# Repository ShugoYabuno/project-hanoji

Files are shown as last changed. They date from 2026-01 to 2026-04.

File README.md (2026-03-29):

# Project Hanoji

## 概要
手首や腕の負担を軽減する、八の字型（回外姿勢）のレバーレスコントローラー開発プロジェクト。

## 目標
- エルゴノミクスに基づいた操作性の高いコントローラーの開発
- 製品化および販売

## ディレクトリ構成
- `marketing/sns/`: SNS発信（投稿案・スケジュール管理）
- `marketing/strategy/`: 戦略立案（市場調査・競合分析・販売戦略）
- `marketing/product/`: 商品企画（仕様書・ロードマップ）
- `content/`: コンテンツ（ブログ記事・SNS投稿案・画像素材）
- `docs/`: ドキュメント（試作仕様・Deep Research）

## エージェント起動方法（Claude Code）

各ディレクトリで `claude` を起動すると、専用の指示（CLAUDE.md）が自動で読み込まれます。

| やりたいこと | 起動コマンド |
|---|---|
| SNS投稿を作りたい | `cd marketing/sns && claude` |
| 商品企画・試作仕様を進めたい | `cd marketing/product && claude` |
| 市場調査・戦略を考えたい | `cd marketing/strategy && claude` |
| ブログ記事を書きたい | `cd content && claude` |

複数タブで同時に起動することで、並列に作業できます。

## ドキュメント
- 競合調査（2026-01-14）: `docs/deepresearch/market_strategy/competitive_research_2026-01-14.md`
- Deep Research INDEX: `docs/deepresearch/INDEX.md`

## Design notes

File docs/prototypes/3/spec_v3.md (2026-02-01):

# 試作3号機 (v3) 仕様書：多面体キーウェルと分割構造の導入

## 1. 概要 (Overview)
試作3号機（v3）は、v1/v2で得られた「角度（Tenting/Opening Angle）」の知見に加え、新たに**「深さ（Depth）」と「分割構造（Modularity）」**を取り入れる。
人間の手の解剖学的構造に寄り添う「多面体（Polyhedral）」形状を採用することで、製造難易度を抑えつつ、ハイエンドなエルゴノミクスキーボードに近いフィット感と入力精度を実現することを目的とする。

## 2. 開発背景と振り返り

### v1/v2 の課題
*   **v1 (Flat Tented)**: テンティングのみでハの字角がなく、手首の背屈（反り）と滑り落ちが発生。
*   **v2 (Monocoque Tented)**:
    *   **形状**: 一体成型のため、3Dプリント時のオーバーハング面が荒れ、製造時間が長大化。
    *   **親指**: 親指キーが他の指と同じ平面にあったため、CM関節への負担が残り、押しにくさがあった。
    *   **配置**: パームレストに対し、ボタン位置が手前すぎた（窮屈）。

### v3 での解決アプローチ
*   **多面体キーウェル**: 曲面を「平面の組み合わせ」で近似し、指の屈曲軌道に合わせる。
*   **親指の立体配置**: 親指ユニットを物理的に一段下げる（Vertical Offset）。
*   **3パーツ分割構造**: 「天板」「フレーム」「底面」を分けることで、プリント品質の安定化とメンテナンス性を確保。

---

## 3. コンセプト (Concept)

### "Polyhedral Key Well" (多面体キーウェル)
完全な曲面（Curved）ではなく、複数の平面を角度をつけて接合する設計。
*   **メリット**:
    *   3Dプリント時に平面が出しやすく、スイッチの座りが安定する（ガタつかない）。
    *   パラメータ調整（角度変更）が容易。

### "Negative Tilt & Integrated Rest"
*   パームレスト部を最も高くし、指先に向かって下がる（Negative Tilt）形状を採用。
*   手首をニュートラル（水平〜やや下向き）に保ち、腱の緊張を最小化する。

---

## 4. 詳細仕様 (Specifications)

### 4.1 ジオメトリ・パラメータ
解剖学的調査に基づき、以下の数値を採用する（v3確定値）。

| 項目 | 設定値 | 意図・根拠 |
| :--- | :--- | :--- |
| **テンティング角 (Tenting)** | **20°** | 前腕の回内緊張を取り除くスイートスポット。 |
| **ハの字角 (Opening Angle)** | **20° (片側)** | センターラインに対する片側の開き角度（両側合計 40°）。脇を少し開いた自然な姿勢に合わせる。 |
| **チルト角 (Negative Tilt)** | **-10°** | パームレスト面（水平基準）に対し、Ridgeから奥側の**ボタン配置面（アクションボタン・移動ボタン共に）**が下がる角度。手首の背屈を防ぐ。 |
| **親指オフセット (Thumb Z)** | **-6.0 mm** (基準面より) | 親指の対立運動に合わせ、他指より低く配置。 |
| **親指内転角 (Thumb Inward)** | **20°** | 親指の腹が自然にスイッチを捉える角度。 |

### 4.2 レイアウト寸法
*   **パームレスト深さ**: 豆状骨（Pisiform）のサポート位置からホームポジション（中指）まで **約90mm** を確保。
*   **ボタン配置**:
    *   v2より全体を **15mm 奥へ移動**。

### 4.3 ボタンレイアウト詳細 (Advanced Layout Strategy)
調査資料「指に優しいボタンレイアウトの設計ガイド」に基づき、各指の役割と可動域に合わせた配置を行う。

#### A. Column Stagger (縦方向オフセット)
中指の先端位置を基準(0mm)とし、指の長さに合わせて各列を縦方向にずらす。
*   **中指列**: ±0 mm (基準)
*   **人差し指列**: -4.0 mm
*   **薬指列**: -6.0 mm
*   **小指列**: **-15.0 mm** (約0.75キー分)
    *   *根拠*: 小指は中指より約20mm短いため、大胆に下げることで「届かない」ストレスを解消する。

#### B. Row Stagger (横方向オフセット)
*   **オフセット量**: **0mm (Ortholinear / 縦揃え)**
    *   *理由*: 一般的なキーボードの斜めズレ（Row Stagger）は、脇を締めた姿勢で指を斜めに動かすための補正である。本機は「ハの字（Opening Angle）」によって腕の進入角度を正対させているため、指は真っ直ぐ手前に屈曲する。したがって、ボタンも縦一列に揃えるのが解剖学的にもゲーム操作（スライド入力等）的にも最適解となる。
    *   *(参考: Alice配列キーボード等も、ハの字に開くことでキー配列自体は縦揃えに近い構成を採用している)*

#### C. Splay (放射状配置)
*   **小指列の角度**: 外側に **10° 〜 15°** 開く。
    *   *根拠*: 小指の自然な外転運動に合わせ、窮屈な内側へのねじ込みを防ぐ。

#### C. Zoning (ゾーニング戦略)
フィッツの法則に基づき、使用頻度と距離を最適化する。
*   **Primary Zone (半径50mm圏内)**:
    *   主要攻撃ボタン（弱・中・強パンチ/キック）を配置。
    *   指先（DIP関節）の屈伸だけで届く範囲に収める。
*   **Secondary Zone**:
    *   特殊アクション（パリィ、インパクト等）は、Primary Zoneから **外側へ10mm** 離して配置。
    *   *意図*: 誤入力を防ぐとともに、明確な「指の移動」を意識させる。

#### D. Ridge (折れ目) との距離定義
多面体構造における平面の境界線（Ridge）と、設計上の基準点（Reference Point）を以下のように定義する。

*   **パームレスト基準点 (Reference Point)**:
    *   **定義**: 筐体（パームレスト部）の **手前エッジ (Front Edge) から 30mm 奥** の地点。
    *   *意図*: ここに豆状骨（手首の小指側の骨）が乗ることを想定する。手前ギリギリに置くとエッジが当たって痛いため、余裕を持たせた位置を基準とする。

*   **Ridge Line (屈曲点)**:
    *   パームレスト基準点から **45mm** 前方（※手前エッジからは計75mm）。
    *   このラインを最高点とし、ここからボタン面（Negative Tilt面）へと切り替わる。
    *   *意図*: 手のひらの中央（中手骨）付近で面を折り、MP関節の可動域と指の巻き込み（Curl）をサポートする。

*   **Ridgeから各ボタン穴の中心 (Hole Center) までの距離**:
    *   ※設計・モデリングの基準とするため、すべて「ボタン穴の中心座標」までの距離とする。
    *   **中指**: **45mm**
        *   *(参考: φ24mmボタンの場合、指が触れる手前エッジまでは約33mm)*
    *   **人差し指**: **42mm**
    *   **薬指**: **42mm**
    *   **小指**: **30mm**
        *   *補足*: 小指はColumn Stagger（-15mm）と合わせて、物理的にもRidgeに近づけることで、短い指でも無理なく届くようにする。

#### E. Movement Buttons (左手・移動ボタン) のY軸定義
左手側の3ボタン（Left, Down, Right）は一段構成であるため、右手側との整合性を以下のように定義する。

*   **Y軸基準 (Row Alignment)**:
    *   右手側の **上段 (Punch列) と下段 (Kick列) の中間、かつ上段寄り** を基準とする。
    *   **具体的数値**: 上段ボタン（Punch列）の中心Y座標から **手前へ 10mm (-10mm)** の位置を、移動ボタン（中指・Down）のY座標基準とする。
    *   *理由*: ユーザーのホームポジション感覚（上段と下段の間）に一致させ、左右の手首位置を対称に保つため。
*   **各指のオフセット (Stagger)**:
    *   右手と同様のColumn Staggerを適用し、指の長さにフィットさせる。
    *   **薬指 (Left)**: 中指より **-6.0mm** (手前)
    *   **中指 (Down)**: 基準 (0mm) / Ridgeから45mm
    *   **人差し指 (Right)**: 中指より **-4.0mm** (手前)

### 4.4 構造設計 (Mechanical Design)
プリント方向と品質を最適化するため、以下の3パーツ構成とする。

1.  **Top Plate (天板)**
    *   スイッチをはめ込むメインパーツ。多面体形状。
    *   *プリント方向*: 立てて出力（積層痕を打鍵方向に対して垂直にし、滑らかにする）。
2.  **Main Frame (側面・パームレスト)**
    *   手首を支える土台。剛性を確保。
    *   *プリント方向*: 平置き。
3.  **Bottom Plate (底蓋)**
    *   メンテナンス用ハッチ。
    *   *プリント方向*: 平置き。

### 4.5 締結・固定仕様 (Assembly)
*   **ネジ穴径**: **φ3.2 mm** (M3ネジ用)
    *   *方式*: ヒートインサートナットを使用せず、ボルト＆ナット（貫通またはポケット）で固定する設計とする。3Dプリント品へのダイレクトタッピングは強度が不安なため避ける。
    *   *配置*: 応力が集中する「パームレスト境界」と「四隅」の計6箇所を固定推奨。

---

## 5. 検証項目 (Hypotheses to Validate)

1.  **親指オフセットの操作性**:
    *   -6mmの段差は、同時押し（スライド入力）を阻害しないか？
    *   ジャンプボタンへのアクセスは改善するか？
2.  **多面体のフィット感**:
    *   指の腹で捉える感覚は向上するか？
    *   エッジ（折れ目）が手に当たって痛くないか？（フィレット処理の要否）
3.  **分割構造の剛性**:
    *   激しい打鍵（台パン等）において、接合部の強度は十分か？
    *   音鳴り（共振）が発生しないか？

## 6. 次のステップ
1.  **CADモデリング**: Fusion 360にて多面体ブロックを作成し、パラメータを適用。
2.  **部分試作**: 親指ユニット周辺のみを切り出してプリントし、オフセット量を確認。
3.  **全体試作**: v3-alphaの出力と組み立て。

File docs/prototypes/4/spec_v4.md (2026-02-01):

# 試作4号機 (v4) 仕様書：チルト角度 -15° の検証

## 1. 概要 (Overview)
試作4号機（v4）は、v3をベースに**チルト角のみ -15° に変更**して、手首の負担と指の巻き込み感を確認するための検証機である。
他の設計パラメータはv3を踏襲し、角度変更による体感差を明確に比較することを目的とする。

## 2. 開発背景と振り返り

### v3 からの変更点
*   **チルト角 (Negative Tilt)** を **-10° → -15°** に変更。
*   それ以外の構造・レイアウトはv3と同一。

---

## 3. コンセプト (Concept)

### "Polyhedral Key Well" (多面体キーウェル)
完全な曲面（Curved）ではなく、複数の平面を角度をつけて接合する設計。
*   **メリット**:
    *   3Dプリント時に平面が出しやすく、スイッチの座りが安定する（ガタつかない）。
    *   パラメータ調整（角度変更）が容易。

### "Negative Tilt & Integrated Rest"
*   パームレスト部を最も高くし、指先に向かって下がる（Negative Tilt）形状を採用。
*   手首をニュートラル（水平〜やや下向き）に保ち、腱の緊張を最小化する。

---

## 4. 詳細仕様 (Specifications)

### 4.1 ジオメトリ・パラメータ
解剖学的調査に基づき、以下の数値を採用する（v4確定値）。

| 項目 | 設定値 | 意図・根拠 |
| :--- | :--- | :--- |
| **テンティング角 (Tenting)** | **20°** | 前腕の回内緊張を取り除くスイートスポット。 |
| **ハの字角 (Opening Angle)** | **20° (片側)** | センターラインに対する片側の開き角度（両側合計 40°）。脇を少し開いた自然な姿勢に合わせる。 |
| **チルト角 (Negative Tilt)** | **-15°** | パームレスト面（水平基準）に対し、Ridgeから奥側の**ボタン配置面（アクションボタン・移動ボタン共に）**が下がる角度。手首の背屈を防ぐ。 |
| **親指オフセット (Thumb Z)** | **-6.0 mm** (基準面より) | 親指の対立運動に合わせ、他指より低く配置。 |
| **親指内転角 (Thumb Inward)** | **20°** | 親指の腹が自然にスイッチを捉える角度。 |

### 4.2 レイアウト寸法
*   **パームレスト深さ**: 豆状骨（Pisiform）のサポート位置からホームポジション（中指）まで **約90mm** を確保。
*   **ボタン配置**:
    *   v2より全体を **15mm 奥へ移動**。

### 4.3 ボタンレイアウト詳細 (Advanced Layout Strategy)
調査資料「指に優しいボタンレイアウトの設計ガイド」に基づき、各指の役割と可動域に合わせた配置を行う。

#### A. Column Stagger (縦方向オフセット)
中指の先端位置を基準(0mm)とし、指の長さに合わせて各列を縦方向にずらす。
*   **中指列**: ±0 mm (基準)
*   **人差し指列**: -4.0 mm
*   **薬指列**: -6.0 mm
*   **小指列**: **-15.0 mm** (約0.75キー分)
    *   *根拠*: 小指は中指より約20mm短いため、大胆に下げることで「届かない」ストレスを解消する。

#### B. Row Stagger (横方向オフセット)
*   **オフセット量**: **0mm (Ortholinear / 縦揃え)**
    *   *理由*: 一般的なキーボードの斜めズレ（Row Stagger）は、脇を締めた姿勢で指を斜めに動かすための補正である。本機は「ハの字（Opening Angle）」によって腕の進入角度を正対させているため、指は真っ直ぐ手前に屈曲する。したがって、ボタンも縦一列に揃えるのが解剖学的にもゲーム操作（スライド入力等）的にも最適解となる。
    *   *(参考: Alice配列キーボード等も、ハの字に開くことでキー配列自体は縦揃えに近い構成を採用している)*

#### C. Splay (放射状配置)
*   **小指列の角度**: 外側に **10° 〜 15°** 開く。
    *   *根拠*: 小指の自然な外転運動に合わせ、窮屈な内側へのねじ込みを防ぐ。

#### C. Zoning (ゾーニング戦略)
フィッツの法則に基づき、使用頻度と距離を最適化する。
*   **Primary Zone (半径50mm圏内)**:
    *   主要攻撃ボタン（弱・中・強パンチ/キック）を配置。
    *   指先（DIP関節）の屈伸だけで届く範囲に収める。
*   **Secondary Zone**:
    *   特殊アクション（パリィ、インパクト等）は、Primary Zoneから **外側へ10mm** 離して配置。
    *   *意図*: 誤入力を防ぐとともに、明確な「指の移動」を意識させる。

#### D. Ridge (折れ目) との距離定義
多面体構造における平面の境界線（Ridge）と、設計上の基準点（Reference Point）を以下のように定義する。

*   **パームレスト基準点 (Reference Point)**:
    *   **定義**: 筐体（パームレスト部）の **手前エッジ (Front Edge) から 30mm 奥** の地点。
    *   *意図*: ここに豆状骨（手首の小指側の骨）が乗ることを想定する。手前ギリギリに置くとエッジが当たって痛いため、余裕を持たせた位置を基準とする。

*   **Ridge Line (屈曲点)**:
    *   パームレスト基準点から **45mm** 前方（※手前エッジからは計75mm）。
    *   このラインを最高点とし、ここからボタン面（Negative Tilt面）へと切り替わる。
    *   *意図*: 手のひらの中央（中手骨）付近で面を折り、MP関節の可動域と指の巻き込み（Curl）をサポートする。

*   **Ridgeから各ボタン穴の中心 (Hole Center) までの距離**:
    *   ※設計・モデリングの基準とするため、すべて「ボタン穴の中心座標」までの距離とする。
    *   **中指**: **45mm**
        *   *(参考: φ24mmボタンの場合、指が触れる手前エッジまでは約33mm)*
    *   **人差し指**: **42mm**
    *   **薬指**: **42mm**
    *   **小指**: **30mm**
        *   *補足*: 小指はColumn Stagger（-15mm）と合わせて、物理的にもRidgeに近づけることで、短い指でも無理なく届くようにする。

#### E. Movement Buttons (左手・移動ボタン) のY軸定義
左手側の3ボタン（Left, Down, Right）は一段構成であるため、右手側との整合性を以下のように定義する。

*   **Y軸基準 (Row Alignment)**:
    *   右手側の **上段 (Punch列) と下段 (Kick列) の中間、かつ上段寄り** を基準とする。
    *   **具体的数値**: 上段ボタン（Punch列）の中心Y座標から **手前へ 10mm (-10mm)** の位置を、移動ボタン（中指・Down）のY座標基準とする。
    *   *理由*: ユーザーのホームポジション感覚（上段と下段の間）に一致させ、左右の手首位置を対称に保つため。
*   **各指のオフセット (Stagger)**:
    *   右手と同様のColumn Staggerを適用し、指の長さにフィットさせる。
    *   **薬指 (Left)**: 中指より **-6.0mm** (手前)
    *   **中指 (Down)**: 基準 (0mm) / Ridgeから45mm
    *   **人差し指 (Right)**: 中指より **-4.0mm** (手前)

### 4.4 構造設計 (Mechanical Design)
プリント方向と品質を最適化するため、以下の3パーツ構成とする。

1.  **Top Plate (天板)**
    *   スイッチをはめ込むメインパーツ。多面体形状。
    *   *プリント方向*: 立てて出力（積層痕を打鍵方向に対して垂直にし、滑らかにする）。
2.  **Main Frame (側面・パームレスト)**
    *   手首を支える土台。剛性を確保。
    *   *プリント方向*: 平置き。
3.  **Bottom Plate (底蓋)**
    *   メンテナンス用ハッチ。
    *   *プリント方向*: 平置き。

### 4.5 締結・固定仕様 (Assembly)
*   **ネジ穴径**: **φ3.2 mm** (M3ネジ用)
    *   *方式*: ヒートインサートナットを使用せず、ボルト＆ナット（貫通またはポケット）で固定する設計とする。3Dプリント品へのダイレクトタッピングは強度が不安なため避ける。
    *   *配置*: 応力が集中する「パームレスト境界」と「四隅」の計6箇所を固定推奨。

---

## 5. 検証項目 (Hypotheses to Validate)

1.  **チルト角 -15° の体感**:
    *   連続入力時の手首角度と疲労感は改善するか？
    *   指先の巻き込み量が過剰にならないか？
2.  **親指オフセットの操作性**:
    *   -6mmの段差は、同時押し（スライド入力）を阻害しないか？
    *   ジャンプボタンへのアクセスは改善するか？
3.  **多面体のフィット感**:
    *   指の腹で捉える感覚は向上するか？
    *   エッジ（折れ目）が手に当たって痛くないか？（フィレット処理の要否）

## 6. 次のステップ
1.  **CADモデリング**: v3モデルを複製し、チルト角のみ -15° に変更。
2.  **部分試作**: アクションボタン面のみを切り出して傾斜の体感を確認。
3.  **全体試作**: v4-alphaの出力と組み立て。

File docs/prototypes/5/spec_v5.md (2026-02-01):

# 試作5号機 (v5) 仕様書：ボタンレイアウト調整版

## 1. 概要 (Overview)
試作5号機（v5）は、v4の筐体仕様（チルト角 -15°）を踏襲しつつ、**ボタンレイアウトのみを調整**した検証機である。
筐体角度は固定し、入力感の改善を目的にレイアウトの微修正を行う。

## 2. 開発背景と振り返り

### v4 からの変更点
*   **チルト角**: v4と同一（-15°）。
*   **ボタンレイアウト**: v4の配置をベースに、手の届きやすさと誤入力の減少を目的として微調整する。

---

## 3. コンセプト (Concept)

### "Polyhedral Key Well" (多面体キーウェル)
完全な曲面（Curved）ではなく、複数の平面を角度をつけて接合する設計。
*   **メリット**:
    *   3Dプリント時に平面が出しやすく、スイッチの座りが安定する（ガタつかない）。
    *   パラメータ調整（角度変更）が容易。

### "Negative Tilt & Integrated Rest"
*   パームレスト部を最も高くし、指先に向かって下がる（Negative Tilt）形状を採用。
*   手首をニュートラル（水平〜やや下向き）に保ち、腱の緊張を最小化する。

---

## 4. 詳細仕様 (Specifications)

### 4.1 ジオメトリ・パラメータ
解剖学的調査に基づき、以下の数値を採用する（v5確定値）。

| 項目 | 設定値 | 意図・根拠 |
| :--- | :--- | :--- |
| **テンティング角 (Tenting)** | **20°** | 前腕の回内緊張を取り除くスイートスポット。 |
| **ハの字角 (Opening Angle)** | **20° (片側)** | センターラインに対する片側の開き角度（両側合計 40°）。脇を少し開いた自然な姿勢に合わせる。 |
| **チルト角 (Negative Tilt)** | **-15°** | パームレスト面（水平基準）に対し、Ridgeから奥側の**ボタン配置面（アクションボタン・移動ボタン共に）**が下がる角度。手首の背屈を防ぐ。 |
| **親指オフセット (Thumb Z)** | **-6.0 mm** (基準面より) | 親指の対立運動に合わせ、他指より低く配置。 |
| **親指内転角 (Thumb Inward)** | **20°** | 親指の腹が自然にスイッチを捉える角度。 |

### 4.2 レイアウト寸法
*   **パームレスト深さ**: 豆状骨（Pisiform）のサポート位置からホームポジション（中指）まで **約90mm** を確保。
*   **ボタン配置**:
    *   v2より全体を **15mm 奥へ移動**。

### 4.3 ボタンレイアウト詳細 (Advanced Layout Strategy)
ボタンレイアウトはv4から調整する。寸法は**v5のCADスケッチを正**とし、以下の差分を記録する。

#### A. v5で調整対象とする項目
*   **アクションボタン上下段のY間隔**: ホームポジション感覚に合わせて微調整。
*   **アクションボタン列のX位置**: 指の到達距離と誤入力のバランスを確認。
*   **移動ボタンのY基準**: 上段寄りの中間位置を維持しつつ、レイアウトの整合性を再確認。

#### B. v4からの暫定踏襲値
*   Column Stagger / Row Stagger / Splay / Ridge距離はv4と同等（必要に応じて上書き）。
*   変更点が確定したら、本セクションに数値を追記する。

### 4.4 構造設計 (Mechanical Design)
プリント方向と品質を最適化するため、以下の3パーツ構成とする。

1.  **Top Plate (天板)**
    *   スイッチをはめ込むメインパーツ。多面体形状。
    *   *プリント方向*: 立てて出力（積層痕を打鍵方向に対して垂直にし、滑らかにする）。
2.  **Main Frame (側面・パームレスト)**
    *   手首を支える土台。剛性を確保。
    *   *プリント方向*: 平置き。
3.  **Bottom Plate (底蓋)**
    *   メンテナンス用ハッチ。
    *   *プリント方向*: 平置き。

### 4.5 締結・固定仕様 (Assembly)
*   **ネジ穴径**: **φ3.2 mm** (M3ネジ用)
    *   *方式*: ヒートインサートナットを使用せず、ボルト＆ナット（貫通またはポケット）で固定する設計とする。3Dプリント品へのダイレクトタッピングは強度が不安なため避ける。
    *   *配置*: 応力が集中する「パームレスト境界」と「四隅」の計6箇所を固定推奨。

---

## 5. 検証項目 (Hypotheses to Validate)

1.  **ボタンレイアウト調整の効果**:
    *   指の到達距離が短くなったか？
    *   誤入力は減少したか？
2.  **チルト角 -15° の体感**:
    *   連続入力時の手首角度と疲労感は改善するか？
    *   指先の巻き込み量が過剰にならないか？

## 6. 次のステップ
1.  **CADモデリング**: v4モデルを複製し、ボタンレイアウトのみを修正。
2.  **部分試作**: 右手側ボタン面のみを切り出して比較テスト。
3.  **全体試作**: v5-alphaの出力と組み立て。

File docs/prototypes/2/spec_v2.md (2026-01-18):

# プロトタイプ v2 設計仕様書 (Draft)

## 1. 概要
- **目的**: v1の検証結果（保持困難、手首負荷）を解消し、快適な操作性を実現する。
- **主要変更点**:
    - **多面体・屈曲天板構造（Polyhedral/Bent Plate）の採用** [New!]
    - パームレストの一体化（必須アタッチメント化）
    - XY平面への角度付け（ハの字配置）
    - テンティング角の維持・最適化

## 2. 幾何学パラメータ (Geometry)

### 2.1 角度設定
| パラメータ | 設定値 (暫定) | 備考 |
| :--- | :--- | :--- |
| **テンティング角 (Z軸回転)** | 10° 〜 15° | エルゴノミクス調査に基づく推奨値。多面体構造により実現。 |
| **ハの字角度 (XY平面回転)** | **30° (片側 15°)** | **確定**。手首の尺側偏位を防ぐため。 |
| **スロープ傾斜角 (前方)** | **10° 〜 15° (Negative Tilt)** | 手首の背屈を抑制。これ以上の角度は神経圧迫のリスクあり。 |

### 2.2 寸法・配置
- **基本レイアウト**: レバーレス（Hitbox準拠）
- **構造デザイン**: **Polyhedral（多面体）構造**
    - 連続曲面ではなく、平面の組み合わせで構成。スイッチの固定安定性と製造容易性を優先。
    - **Ridge（折れ目）設定**:
        - **位置 (深さ)**: パームレスト手前端から **90mm**。
            - 手首の骨〜手のひらの中心までをカバーし、指の付け根(MP関節)がRidgeに来る想定。
        - **形状**: 鋭利な角を避け、**R2.0mm以上**のフィレット（丸み）を必須とする。
- **左右分割**:
    - [ ] 完全分割型
    - [x] **一体型（V字形状）**
        - **理由**: 膝上プレイ時の安定性を最優先するため（格闘ゲーム用途）。
        - **特徴**: 左右のユニットが中央または底面プレートで接続され、固定された「ハの字」と「テンティング」を持つ。
        - **左右間隔 (Split Distance)**: **50mm** (中央部でのボタン群の距離)
- **ボタン配置・サイズ**:
    - アクションボタン: 24mm
        - **配置**: Ridgeからボタン中心までの距離は **20mm 〜 25mm**。
            - 指を自然に曲げた状態での着地点を狙う。
    - ジャンプ/親指: 30mm
        - **高さオフセット**: 4指の平面より **-5mm 〜 -8mm** 低く配置 (親指の自然な握り込みに対応)。

## 3. 構造・コンポーネント
### 3.1 パームレスト
- **要件**: 天板の傾斜に合わせた**完全一体型**。
    - 水平な机に置くタイプは不可（手首が浮くため）。
- **形状**: 傾斜がついているため、手が滑り落ちないような摩擦係数の高い素材、または「返し」となる形状が必要。

### 3.2 安定性対策
- 底面に滑り止めシート用エリアを確保。
- 内部にウェイト（重り）を入れるスペースを作るか？
- 天板の剛性確保（アクリルなら3mm以上、または支柱追加）。

### 3.3 外側ストッパー（Side Wall）
- **目的**: テンティング傾斜（10-15°）による手の滑り落ち（外側へのスライド）防止。
- **デザイン方針**: **手首側限定＆フェードアウト形状**を採用。
    - **配置**: パームレスト部（小指球付近）にのみ高さを設け、ボタン横（指の可動域）に差し掛かる前に高さをなだらかに消失させる。
        - **理由**: 最外ボタンと縁の距離が **9.5mm** と狭いため、ボタン横に壁があると小指が衝突するリスクが高いため。
    - **寸法**:
        - **高さ**: **5mm 〜 8mm**（最適値）。
    - **形状処理**: 肌への当たりを優しくするため、内側（手が触れる側）にはR3mm以上のフィレット、または外に開くドラフト角を設ける。

## 4. 製造・素材選定 (Material & Manufacturing)
- **素材選定方針**: プロジェクト共通の指針については [hardware/materials_guide.md](../../../materials_guide.md) を参照のこと。

### 4.1 本プロトタイプ(v2)での採用設定
- **素材**: **PLA** (試作フェーズのため)
- **製造**: Bambu Lab P1/X1
- **サポート設定**: **Tree Hybrid** (内部空洞・傾斜面の支持に最適)

## 5. モデリング・Todo
- [ ] Fusion 360でのシートメタル/多面体設計の検討
- [ ] 「曲げ」による高さの変化と、内部スペース（配線・基板）の干渉チェック
- [ ] ボタン配置スケッチの作成（Ridgeからの距離20-25mmを基準線にする）
- [ ] 親指ボタンの段差（-5mm〜-8mm）の実装方法の検討

## 6. フィードバック & 改善記録
- **2026-01-18 印刷試験**: 天板裏面の荒れ対策として、側面設置プリント設定を確立。詳細は [v2_feedback.md](./v2_feedback.md) を参照。

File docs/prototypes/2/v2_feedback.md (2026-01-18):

# プロトタイプ v2 試作フィードバック & 次期(v3)検討事項

## 1. 3Dプリント製造上の課題と対策 (2026-01-18)

### 課題: 天板裏面の荒れ
- **現象**: テンティングおよびハの字傾斜により、天板の裏側が広範囲のオーバーハングとなる。`Tree (Default)` サポートで出力した結果、フィラメントの垂れ下がりが発生し、面が荒れてしまった。
- **影響**: ナット締結時の座面が不安定になる恐れがある。

### 対策方針 (次回プリント/v3試作時)

#### アプローチA: 造形方向の変更（推奨）
表面（天板面）の滑らかさを最優先し、積層痕を目立たなくするために**「側面を下にして立てて印刷」**する。

*   **配置 (Orientation)**:
    *   **Y軸合わせ**: モデルの長辺をプリンタのY軸（ベッド移動方向）に平行に合わせる。
        *   *理由*: Bambu Lab A1等のベッド駆動型において、転倒リスクを最小化するため。
*   **定着設定 (Bed Adhesion)**:
    *   **Brim**: `Outer brim only`, 幅 `15mm` 〜 `20mm`。
        *   *理由*: 接地面積が極端に狭いため、ブリムで強制的に足を広げて転倒を防ぐ。
*   **サポート設定**:
    *   **揺れ防止支柱**: `Tree (manual)` を使用し、モデルの中腹（高さの半分〜2/3付近）に手動でサポートポイントを追加して、左右から支える。
        *   *理由*: 高さがあるため、ノズル移動時の振動でモデル上部が揺れ、造形品質が下がるのを防ぐ（リンギング対策）。
*   **印刷速度**:
    *   **Silent Mode**: 必要に応じて速度を50%に落とす。

#### アプローチB: 平置きでの改善（安定重視）
もし立てて印刷して失敗する場合のバックアッププラン。

*   **サポート種類**: `Normal` (Style: `Grid` or `Rectilinear`)
    *   *理由*: Treeよりも土台が安定するため、広い平面を支えるのに適している。
*   **インターフェース設定**:
    *   **Top Z distance**: `0.1mm` 〜 `0.15mm` (通常0.2mmより詰める)
    *   **Top interface spacing**: `0mm` (Dense / 隙間なし)
    *   *理由*: サポート最上面を密な板状にし、本体との隙間を極限まで減らすことで垂れ下がりを物理的に防ぐ。

## 2. 設計・形状へのフィードバック (2026-01-18)

### 構成: 分割構造への回帰
- **現状 (v2)**: 一体成形（シングルプリント）。接合面がなく美しいが、サポート材の出力に時間がかかりすぎる。
- **次期 (v3)**: **「天板」「側面」「底面」の3パーツ構成**にする。
    - **狙い**: プリント時間の短縮と、各パーツの向きを最適化することでサポートを減らし、品質を向上させる。

### 外形形状: 5角形から4角形へ
- **現状 (v2)**: 5角形ベースの形状。
- **次期 (v3)**: **4角形（台形・長方形に近い形状）**に変更する。
    - **狙い**: 手のひらを置くスペース（パームレストエリア）を広く確保するため。

### 面構成: 親指（ジャンプ）エリアの高さ
- **現状 (v2)**: 設計簡易化のため、単純な多面体構成を採用。
- **次期 (v3)**: **ジャンプボタンの面を、パームレスト面よりも一段低く**設定する。
    - **狙い**: 親指の自然な可動域に合わせ、よりリラックスした状態で打鍵できるようにする。

### ボタンレイアウト配置
- **変更**: 移動ボタン群とアクションボタン群を、現在の位置よりも**上方向に約15mm**ずらす。
    - **狙い**: 手のひらの置き位置と指の届き具合の最適化。

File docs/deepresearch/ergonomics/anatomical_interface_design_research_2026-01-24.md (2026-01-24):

# 人間の手の解剖学的特性に基づく高効率・低負荷指先操作インターフェースの包括的研究

## 序論：現代インターフェース設計における人間工学的転換

現代の産業、医療、芸術、およびエンターテインメントの各分野において、指先を用いた精密な操作インターフェースの重要性はかつてないほど高まっている。しかし、伝統的な入力デバイスの多くは、依然として19世紀の機械的制約を色濃く残しており、人間の手の解剖学的構造に最適化されているとは言い難い。例えば、標準的なQWERTY配列キーボードに見られる「行ズレ（Row-staggered）」配置は、もともと機械式タイプライターの印字棒が絡まるのを防ぐために考案された歴史的遺物であり、バイオメカニクス的な合理性は欠如している。

本研究の目的は、エルゴノミクスキーボード、楽器、戦闘機の操縦系（HOTAS）、F1ステアリングホイール、そして手術支援ロボットといった、極めて高度な指先操作が要求される多領域の知見を統合することである。これにより、指の長さ、可動域、および筋肉の負荷分散に基づいた、次世代のゲームコントローラー設計にも応用可能な「解剖学的最適配置ルール」を導き出す。

設計思想の根底にあるのは、人間を機械に合わせるのではなく、機械を人間の身体構造に適応させるという「バイオメカニカル・エラ（生体力学時代）」への移行である。

## 指の解剖学的基本構造と運動特性の定量的分析

指の操作レイアウトを設計する上で、最優先されるべきパラメータは各指の長さの差異と、関節の回転中心に基づく運動軌道である。

### 指の長さの統計的指標

成人の指の長さ、すなわち中手指節関節（MP関節）から指先までの距離には、個体差はあるものの明確な統計的パターンが存在する。以下の表は、エルゴノミクス設計の基礎となる平均的な指の長さのデータである。

| 部位（指） | 平均長さ (mm) | 標準偏差 (mm) | 相対的な差（中指基準） |
| :--- | :--- | :--- | :--- |
| 親指 (Thumb) | 49.5 | 5.5 | -21.2 |
| 人差し指 (Index) | 63.9 | 4.1 | -6.8 |
| 中指 (Middle) | 70.7 | 5.2 | 0.0 |
| 薬指 (Ring) | 65.5 | 4.8 | -5.2 |
| 小指 (Little) | 53.3 | 4.3 | -17.4 |

このデータから明らかなように、中指を頂点とした非対称な円弧が手の自然な形状を構成している。人差し指と薬指の長さは比較的近いが、小指は中指に対して約17mm以上短く、この長さの差をボタン配置の垂直オフセット（Vertical Stagger）で吸収することが、エルゴノミクス設計の第一歩となる。

### 関節の可動域とバイオメカニクス

指の動きは、主にMP関節（付け根）、PIP関節（第1関節）、DIP関節（第2関節）の3つの関節によって制御される。ボタン操作において最も重要なのはMP関節を中心とした回転運動である。

*   **屈曲と伸展**: 指を曲げると指先は掌の内側に集まり、伸ばすと放射状に広がる。
*   **内転と外転**: 指を閉じる動きと開く動きである。小指は他の指に比べて外転の可動域が広く、薬指から離れる方向に大きく開くことができる。

特に小指は、垂直方向の運動（屈曲・伸展）において最も疲労しやすい特性を持っており、エルゴノミクスキーボードの設計者の中には、小指の負荷を減らすために垂直方向のキーを減らし、代わりに横方向のクラスタを配置するアプローチを提唱する者もいる。

## エルゴノミクスキーボードにおける配置最適化

キーボード設計の分野では、長年のユーザー体験と生体力学的研究に基づき、特定の数値や角度が「事実上の標準」として定着しつつある。

### 垂直オフセット（Column-staggered）の設計値

各指の長さに合わせて列（カラム）を上下にずらす手法において、中指を基準（0mm）とした場合の推奨される標準的なオフセット値は以下の通りである。

*   **中指（Middle）**: 基準点（0mm）。
*   **人差し指（Index）**: 中指より **3mm 〜 5mm** 下げる。
*   **薬指（Ring）**: 中指より **5mm 〜 8mm** 下げる。
*   **小指（Little）**: 最も大きな調整が必要であり、中指に対して **10mm 〜 15mm**（約0.75Uから1.0U）下げる配置が、多くの「攻撃的なスタッガー（Aggressive Stagger）」を特徴とするモデル（Kyria, Ferris Sweepなど）で採用されている。

これらの数値を適用することで、ホームポジションに指を置いた際、すべての指のパッド（腹）がキーの中心に自然に位置するようになる。逆に、直線の行に指を合わせようとすると、短い小指や薬指を不自然に伸ばす必要があり、これが腱に過度な張力を生じさせる原因となる。

### 放射状配置（Splay）の有効性と角度

「Splay」とは、キーの列を平行ではなく、MP関節を中心とした扇形に配置する設計である。これにより、手首を不自然に内側へ曲げる「尺側偏位（Ulnar deviation）」を完全に排除できる。

*   **標準的な開き角度**:
    *   人差し指列：**0度**（基準）
    *   薬指列：外側に **5度 〜 10度**
    *   小指列：外側に **15度 〜 25度**

研究によれば、指の自然な運動弧（Arc）に沿ったレイアウトは、標準的なレイアウトと比較して伸筋群の活動を最大37%減少させることができる。X-BowsやAlice配列に見られるような角度のついた配置は、一見特殊に見えるが、解剖学的な「ニュートラル・ポスチャ（中立位）」に基づいた真実の設計と言える。

### 3D凹面キーウェル（Key Wells）の効果

Glove80やKinesis Advantageなどのハイエンド・エルゴノミクスデバイスで採用されている「凹面キーウェル」は、垂直オフセットを3次元に拡張した概念である。

*   **メカニズム**: キーキャップを指先の回転半径に合わせた球面状に配置することで、上段や下段のキーへの到達距離を短縮する。
*   **バイオメカニクス的メリット**: 指を伸ばす（伸展）際の負荷が激減し、各キーへのアクセスタイムが均質化される。また、親指クラスタを低い位置に配置することで、親指の対立運動（Opposition）を最大限に活用できる。

## 楽器インターフェースにおける運指最適化の極致

楽器は数世紀にわたり、「高速な連続打鍵」と「複雑な同時押し」という、ゲームコントローラーの操作に極めて近い課題に取り組んできた。

### クロマチック・ボタン・アコーディオン（CBA）の幾何学的規則

CBAのボタン配列は、音楽的な合理性と指の物理的制約を高度に調和させている。

*   **アイソモーフィック・レイアウト**: ボタンは短三度の音程で垂直に並び、半音階が対角線上に並ぶ。この規則性により、どのキー（調）であっても同じ指の形（シェイプ）で演奏が可能となる。
*   **ボタンの物理パラメータ**:
    *   ボタン直径: **15mm 〜 16mm**。
    *   中心間ピッチ: **18mm 〜 20mm**。
    *   列間の段差（Step height）: **約 4mm**。このわずかな段差が、指を滑らせる（Slide）操作を容易にし、同時に隣接ボタンの誤操作を防ぐ触覚フィードバックとなる。

### テオバルト・ベームの管楽器改革（Schema）

19世紀のフルート奏者であり職人であったベームは、指の配置を「音響的な理想」から切り離すという革命を起こした。

*   **ベームの図式（Schema）**: 音孔の位置を数学的（対数的）に決定し、それを人間が届く範囲の「タッチピース」へリンク機構（アクスル、ロッド、スリーブ）を用いて導いた。
*   **教訓**: ボタンの「作用点」と指の「操作点」は必ずしも一致させる必要はない。自作コントローラーにおいても、内部配線やメカニカルリンクを活用し、内部構造を優先するのではなく、指の円弧上にボタンを配置すべきである。
*   **オフセットGキーの採用**: 多くの現代フルートでは、中指より短い薬指のためにGキーをわずかに外側にずらしている。これは、薬指のMP関節が他の指よりも手のひら側に位置するという解剖学的事実に対応している。

## 高機能操縦デバイスにおける situational zoning

戦闘機（HOTAS）やF1のステアリングホイールでは、認知負荷を最小限に抑えつつ、指の到達圏を最大限に活用する「ゾーニング」が徹底されている。

### HOTASにおける指の役割分担

HOTAS（Hands On Throttle-And-Stick）の基本は、グリップを握ったまま全スイッチを操作することである。

| 指 | 主な操作対象 | 特徴と理由 |
| :--- | :--- | :--- |
| 親指 (Thumb) | 多方向ハットスイッチ、TMS/CMS | 4軸の自由度を活かし、メニュー選択や目標捕捉を担当。 |
| 人差し指 (Index) | トリガー（2段階）、通信スイッチ | 反応速度が最も速く、かつ独立した屈曲運動が可能。 |
| 中指 (Middle) | 一部の補助スイッチ | 人差し指の動きと連動しやすいため、重要度の低い機能。 |
| 薬指・小指 | パドルスイッチ、グリップボタン | 「握り込む」動作の強さを利用。誤操作防止のため、重いバネ圧が設定される。 |

### F1ステアリングホイールの三段階ゾーニング

F1の設計では、グリップからの距離と操作頻度を3つの階層に分けている。

1.  **ティア1：常時アクセスゾーン（Upper C Area）**
    *   親指の先端が描く半径30mm以内の円弧上。DRS、オーバーテイクボタン、無線。
    *   理由：グリップを緩めることなく、親指の屈曲・伸展のみで操作可能。
2.  **ティア2：伸展アクセスゾーン（Lower C Area）**
    *   指を最大まで伸ばした際に届く範囲。デフ設定、ブレーキバランス。
    *   理由：1周に数回しか操作しないが、高速走行中に操作する必要がある。
3.  **ティア3：オフハンドゾーン（Main Face）**
    *   グリップを一時的に離す必要がある中央部。ピットリミッター、エンジンマップ、燃料調整。
    *   理由：停車中や直線走行中にしか使用しない、あるいは誤入力を絶対に避けたい機能。

## 手術支援ロボットにおける精密制御とスケーリング

da Vinciなどのロボットサージェリーでは、人間の指の「器用さ」を抽出し、物理的な限界を超えるための技術が組み込まれている。

### da Vinci マスターコントローラーの指配置

執刀医は、親指と人差し指（または中指）をマジックテープ式のリングに固定し、ペンやピンセットを扱うような「微細運動（Fine Motor Skills）」を利用する。

*   **指の選択（1&2 vs 1&3）**: 最近の研究では、親指と人差し指（1&2）よりも、親指と中指（1&3）を用いたほうが、手首の可動域制限が少なく、複雑な縫合において衝突エラーが少ない可能性が示唆されている。
*   **モーション・スケーリングの数理**:
    手元の操作量 $w_{exo}$ とロボット鉗子の開閉幅 $w_{ew}$ の関係は、以下の線形モデルで制御される。
    $$w_{ew} = \frac{max_{ew} - min_{ew}}{max_{exo} - min_{exo}} w_{exo} + C$$
    これにより、人間の指が 5cm 動いても、患部では 1cm しか動かないといった調整が可能になり、高精度な操作が実現される。

### 疲労軽減のための推奨関節角度

da Vinciのコンソール設計では、長時間の執刀を可能にするため、以下の「中立位」関節角度が定義されている。

| 関節 | 推奨角度範囲 | 根拠（RULA評価基準） |
| :--- | :--- | :--- |
| 首 ($\Delta N$) | 0度 〜 10度 | 頚椎への垂直荷重を最小化。 |
| 肩 ($\Delta S$) | 0度 〜 20度 | 肩峰下の圧迫を防止。 |
| 肘 ($\Delta E$) | 60度 〜 100度 | 上腕二頭筋と三頭筋の緊張バランス。 |
| 手首 | 0度 〜 15度 | 正中神経の圧迫を回避（手根管症候群予防）。 |

## 到達圏と快適領域（Reach & Comfort Zone）の理論的基盤

物理的なボタン配置を決定するための最も強力なツールは、フィッツの法則と、それに基づくリーチ・エンベロープ（到達圏包絡面）の定義である。

### フィッツの法則（Fitts' Law）と操作効率

ボタン操作時間（$MT$）を予測する公式は、以下の通りである。

$$MT = a + b \log_2 \left( \frac{D}{W} + 1 \right)$$

ここで、$D$ は現在の指の位置から目標までの距離、$W$ はボタンの有効幅である。この式から導かれる設計の鉄則は以下の3点である：

1.  **距離の短縮**: 最も頻繁に使用するボタンは、指のデフォルトの休息位置（Prime Pixel）に隣接させるべきである。
2.  **有効幅の拡大**: 距離 $D$ が遠くなるボタンほど、ターゲット幅 $W$ を大きく設計し、難易度指数（Index of Difficulty）を一定以下に保つ。
3.  **周辺部の利用**: コントローラーの縁やトリガーのストッパーは、物理的に「行き止まり」となるため、$W$ が無限大とみなされ、正確なエイミングなしに素早く入力できる。

### リーチ・エンベロープの階層定義

人間の前腕と指の動きから、以下の3つの主要なリーチゾーンが定義される。

1.  **第1ゾーン：プライマリ・ゾーン（Neutral Reach Zone）**
    *   肘を脇に置いたまま、前腕の回転のみで届く範囲。半径 約 350mm 〜 460mm（腕全体の場合）。
    *   指先操作においては、指の関節を伸ばしきらずに届く **半径 20mm 〜 40mm** の領域。
    *   ここに配置すべきもの：格闘ゲームの攻撃ボタン、移動用アナログスティック。
2.  **第2ゾーン：セカンダリ・ゾーン（Extended Reach Zone）**
    *   肘をわずかに動かして届く範囲。指先操作では、指を最大まで伸展させて届く **半径 50mm 〜 70mm** の領域。
    *   ここに配置すべきもの：サブウェポン、ガードボタン、インベントリショートカット。
3.  **第3ゾーン：ターシャリ・ゾーン（Outer Reach Zone）**
    *   上体を傾けたり、グリップを持ち替えたりする必要がある範囲。
    *   ここに配置すべきもの：メニュー、設定、リセット。

## 幾何学的作図ルール：自作コントローラーへの応用手順

これまでの調査に基づき、解剖学的に理想的なボタン配置を設計するための具体的な幾何学的作図ルールを提示する。

### 1. 基点（MP関節）の特定

人間の手のひらの幅を測定し、各指のMP関節（拳の骨の付け根）の座標 $(x_n, y_n)$ を定義する。

*   **中指のMP関節**: 原点 $(0, 0)$ とする。
*   **人差し指のMP関節**: $(-20mm, -5mm)$ 付近。
*   **薬指のMP関節**: $(+20mm, -5mm)$ 付近。
*   **小指のMP関節**: $(+40mm, -15mm)$ 付近。

※ 小指の付け根は中指に比べて約 **15mm 低い**位置にあることに注意。

### 2. 到達円弧（Reach Arcs）の描画

各指の MP 関節を中心とし、指を自然に伸ばした際の長さ（前述の平均値）を半径 $R$ として円弧を描く。

$$(x - x_n)^2 + (y - y_n)^2 = R_n^2$$

*   中指 $R = 70mm$
*   人差し指・薬指 $R = 65mm$
*   小指 $R = 55mm$

この円弧上にボタンを配置することで、指の回転運動に対してボタンが常に最短距離に位置することになる。

### 3. 垂直オフセットと Splay 角度の合成

単なる円弧配置ではなく、さらに指の外転（扇状の広がり）を考慮した角度 $ \theta $ を列ごとに設定する。

*   **人差し指列**: $ \theta = -15^\circ $ （内向き）
*   **中指列**: $ \theta = 0^\circ $ （基準）
*   **薬指列**: $ \theta = +10^\circ $ （外向き）
*   **小指列**: $ \theta = +25^\circ $ （大幅な外向き）

これにより、各指の列（カラム）が互いに干渉することなく、独立した直線運動（屈曲・伸展）を行うための通路が確保される。

### 4. ボタンサイズのグラデーション

フィッツの法則を補償するため、中心（ホームポジション）から離れるほどボタン面積を拡大する。

*   **ホームポジションボタン**: 直径 15mm（高速・高精度）
*   **上段・下段ボタン**: 直径 18mm 〜 20mm
*   **最外周・緊急用ボタン**: 24mm 以上、あるいは長円形。

## バイオメカニクス的根拠：なぜこの配置が「楽」なのか

本研究で推奨される配置が指への負担を軽減する理由は、単なる快適性の追求ではなく、以下の生体力学的メカニズムに基づいている。

1.  **尺側偏位（Ulnar Deviation）の解消**
    標準的なキーボードや不適切なコントローラーは、手を無理やり平行に置かせるため、手首が小指側に曲がった状態を強いる。これは手根管（Carpal Tunnel）を物理的に狭窄させ、正中神経を圧迫する。Splay（開き）と傾斜（Tenting）を組み合わせた配置は、手首を完全にニュートラル（真っ直ぐ）な状態に保つため、血流を維持し神経障害のリスクを最小化する。
2.  **腱の移動量（Tendon Excursion）の最適化**
    指を横方向に動かす（側方移動）動作は、本来の指の筋肉の走行に逆らう動きである。Column-staggered 配置により、指の横方向へのジャンプを「垂直方向の屈曲」に置き換えることで、前腕の筋活動量を最大で30%以上削減できる。
3.  **筋肉の出力特性と負荷分散**
    親指は他の指の約2倍の筋質量と筋力を持っている。一方、多くのインターフェースでは親指を「スペースバー」や「単一のボタン」にのみ使用し、非力な小指に多数の「シフト」や「修飾キー」を割り当てている。本報告のゾーニング設計は、強力な親指に頻度の高いコマンドを割り振り、非力な小指には握り込みによるパドル操作などの単純なタスクを限定的に割り当てることで、手全体の疲労バランスを最適化する。

## 結論と設計への推奨事項

自作のゲームコントローラー設計において、人間の手の解剖学的特性を最大限に活かすためには、以下の結論を設計指針とすべきである。

*   **脱・直線格子**: ボタンを直線的なグリッドに並べるのは避けるべきである。中指を頂点とし、小指に向かって **10mm 以上**の垂直スタッガーを設けることが必須である。
*   **放射状運動の受容**: 各指のカラムを外側に **10度 〜 25度** 傾ける「Splay」設計を取り入れる。これにより、指の自然な伸展動作がそのままボタン入力に直結する。
*   **親指の多機能化**: 単一のアナログスティックだけでなく、親指の円弧上に複数の追加ボタン（親指クラスタ）を配置し、手の筋肉の半分近くを占める親指のポテンシャルを解放する。
*   **触覚によるゾーニング**: 操作頻度に応じて、ボタンのサイズ、高さ、表面のテクスチャを変化させる。特に「緊急だが頻度が低い」ボタンには、F1のように誤操作防止のガードリムを設けることが有効である。
*   **スケーリングの導入**: 高速かつ精密なエイミングが必要な場合、da Vinciのように物理的な操作量と内部的な入力値を「5:1」などの比率でスケーリングする調整機能をソフトウェア層で実装することを検討する。

指先インターフェースの設計は、もはや単なる造形ではなく、人間の身体運動をコード化する科学である。本報告に示した数値と作図ルールを適用することで、ユーザーの潜在的なパフォーマンスを最大限に引き出し、同時に長期的な健康を維持する卓越したコントローラーが実現されるだろう。

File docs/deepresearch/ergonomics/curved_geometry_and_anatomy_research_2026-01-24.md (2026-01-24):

# 競技型格闘ゲーム用デバイスにおける曲面幾何学と解剖学的適合性の統合研究：次世代レバーレスコントローラーの設計パラメータ

格闘ゲームという極めて高い入力密度（Actions Per Minute, APM）と、強力な衝撃を伴う「底打ち（Bottoming out）」動作が繰り返される環境において、入力デバイスの人間工学的な設計は、単なる快適性の追求を超え、選手の選手生命を左右する反復性労働災害（RSI）の防止という重要な役割を担っている。従来のレバーレスコントローラー、特に「Hitbox」に代表される平面的なレイアウトは、アーケード文化の継承という側面では合理的であったが、解剖学的な視点からは、手首の背屈（Extension）、尺屈（Ulnar Deviation）、および前腕の回内（Pronation）を強制する構造となっている。

本報告書では、自作キーボードコミュニティにおける「Dactyl Manuform」や、商業的成功を収めた「Glove80」、「Kinesis Advantage360」といった高度な人間工学デバイスの設計思想を分析し、格闘ゲーム用レバーレスコントローラーに適用すべき立体的なボタン配置のパラメータを、具体的な数値と解剖学的根拠に基づいて提示する。

## 1. 親指（Thumb Cluster）の運動学と垂直オフセットの算定

親指は手の機能において約40%から50%の重要性を占めるとされ、他の四指とは根本的に異なる運動メカニズムを有している。他の指が主に屈曲と伸展を行うのに対し、親指は大菱形骨と第一中手骨からなる鞍関節（CMC関節）を起点とした「対立運動（Opposition）」を主動作とする。

### 1.1 垂直オフセットの解剖学的必要性と理論値

平面的なボタン配置において、親指が他の指と同じ高さにある場合、親指を動作させるためにCMC関節を無理に外転・内転させる必要があり、これは腱鞘炎の一種であるド・ケルバン病や母指CM関節症のリスクを高める。これを回避するため、親指ボタンは人差し指のホームポジション面に対して「垂直に低く」配置されなければならない。

Dactyl Manuformの設計フレームワークにおいて、この垂直オフセット（$Z$-offset）は、手の自然な静止位（Position of Function）に基づいて決定される。研究データおよびGitHub上のオープンソースパラメータによれば、基準面からの垂直下降距離は以下のように定義されている。

| 設計パラメータ | 推奨数値 (mm) | 実装モデル・ソース |
| :--- | :--- | :--- |
| 標準垂直オフセット | 9 mm - 12 mm | Dactyl Manuform (Default) |
| 拡張垂直オフセット | 16 mm | Dactyl Manuform (High-tenting configuration) |
| 最低点高度 (Table to Keycap) | 20 mm | Glove80 (Low-profile implementation) |

解剖学的には、手首を20度から30度背屈させた状態での親指の先端は、人差し指の第二関節付近と同じ平面上に位置する。ボタンの高さ（スイッチの全高を含む）を考慮すると、物理的なケース面におけるオフセットは **10mm から 15mm** の範囲が、親指の付け根にかかる緊張を最小化する最適解となる。

### 1.2 親指の回転円弧（Thumb Arc）と傾斜角の最適化

親指を内側に動かす際、その軌跡は単なる直線ではなく、円錐形の回転運動を描く。対立運動が進むにつれて、親指の爪の面は手のひらに対して垂直な状態から平行な状態へと、最大で $90^{\circ}$ 近く回転（回内）する。この運動軌道に適合させるため、親指クラスターは単一の平面ではなく、複数の角度が組み合わされた「ハの字型」の傾斜が必要である。

Dactyl Manuformのソースコード（dactyl.clj）における角度パラメータでは、親指ユニットに対して以下のような多軸的な傾斜が与えられている。

*   **橈側傾斜（Thumb Tilt）**: 約 $15^{\circ}$ から $25^{\circ}$。これは親指の腹がボタン面に対して常に垂直に接するように設定される。
*   **前方傾斜（Thumb Angle）**: $10^{\circ} - 15^{\circ}$。親指を伸ばした際の自然な前方投影に合わせる。

Glove80の設計 journey によれば、親指クラスターの配置は500以上の実験とハードウェアプロトタイプを経て決定されており、手のひらを動かさずに6つのボタンすべてにアクセスできる「パテント・ペンディング」のカーブレイアウトを採用している。

格闘ゲームにおいては、特に「ジャンプ（Up）」ボタンが親指の最も遠い位置（または下部の大きなボタン）に割り当てられるため、このボタンへの到達距離を縮めるために、クラスター全体を親指の付け根方向に数ミリメートル寄せる（Tuck）設計も有効である。

## 2. 指の屈曲軌道に適合する曲面キーウェル（Concave Key Well）の設計

四指（人差し指、中指、薬指、小指）の打鍵動作は、近位指節間関節（PIP関節）を中心とした円弧運動である。平面的なキーボードでは、上段や下段を打つ際に指を伸ばす（Extension）か、手首全体を移動させる必要があるが、曲面（Concave）設計では指を「巻き込む」動作だけで全段にアクセスできる。

### 2.1 曲率半径（Curvature Radius）の算定と幾何学的根拠

曲面設計における最大の課題は、指の長さに合わせた最適な半径 $R$ を見出すことである。PIP関節の屈曲時の回転軸（Helical Axis）を分析した研究によれば、指の運動は純粋な円ではなく、螺旋状の軌跡をたどるが、実用的な設計においては以下の半径が推奨されている。

$$R_{optimal} = L_{finger} \times k + H_{cap}$$

ここで $L_{finger}$ は指の全長（約 $170\text{mm} - 190\text{mm}$）、$k$ はホームポジション時の指の曲げ係数、$H_{cap}$ はキートップから回転中心までの高さである。自作コミュニティにおける実測データによれば、以下の数値が標準として機能している。

| 指の長さ (中指) | 推奨曲率半径 R (mm) | ユーザーの体感 |
| :--- | :--- | :--- |
| 短め (160mm 以下) | 25 mm - 40 mm | 非常にタイトな「お椀型」。指の移動が極小化される。 |
| 標準 (170-180mm) | 50 mm - 70 mm | Dactyl系のデフォルトに近い。適度な開放感とアクセシビリティ。 |
| 長め (190mm 以上) | 100 mm 以上 | Kinesis Advantage2の緩やかなカーブに近い。大きな手の動きを許容する。 |

Glove80の設計において、各列（Column）の円弧は完全な円形（Circular Arc）ではなく、人間の指の関節連動に基づいた「黄金比螺旋（Golden Ratio Spiral）」に近い形状が採用されている。これは、指が深く曲がるほど回転半径が小さくなる解剖学的特性を反映したものである。

### 2.2 テント角（Tenting）とネガティブチルトの相乗効果

前腕の自然な姿勢は、手のひらが内側を向く「握手」のような状態である。平面キーボードはこの姿勢を $90^{\circ}$ 回内させるため、橈骨と尺骨の間に静的な筋肉緊張を生じさせる。格闘ゲームでは、この状態で激しくボタンを叩くため、手首への負担は事務作業の数倍に達する。これを解消するための推奨角度設定は以下の通りである。

*   **テント角（Tenting Angle）**: $15^{\circ} - 40^{\circ}$。Kinesis Advantage360では、ユーザーの好みに合わせて $20^{\circ}$（Low）、Medium、Highの3段階をボタン一つで切り替え可能にしている。「Dactyl-Manuform-Tight」のような極限までコンパクト化したモデルでは、最大 $40^{\circ}$ のテント角が設定され、前腕の緊張をほぼ完全に消失させている。
*   **ネガティブチルト（Negative Tilt）**: $-10^{\circ} - -15^{\circ}$。手前を高く、奥を低くすることで、手首の背屈（Extension）を抑制し、手根管内の圧力を下げる。研究によれば、スロープを $+15^{\circ}$ から $-15^{\circ}$ に変更することで、手首の伸展角は平均 $13^{\circ}$ 改善（$22^{\circ}$ から $9^{\circ}$ へ減少）し、中立的な姿勢に近づく。

**成功例としての組み合わせ例**：
「テンティング 20度 ＋ ネガティブチルト 10度」。この構成は、Glove80やKinesisで実証されており、長時間のプレイにおいても疲労を感じにくい「ニュートラル・ポジション」を実現する。

## 3. パームレストとボタン列（Home Row）の幾何学的相関

レバーレスコントローラーにおいて、手首（特に豆状骨周辺）のサポートは、安定した高速入力を可能にするための基盤である。しかし、不適切な位置への圧迫は正中神経を圧迫し、逆効果となる。

### 3.1 豆状骨（Pisiform）からホームポジションまでの最適距離

手の付け根にある豆状骨（Pisiform）をパームレストのクッションの中心付近に置いたとき、そこから中指のホームボタン（J/Fキーに相当する位置）の中心までの距離は、指の操作範囲を決定する。

*   **解剖学的基準値**: 一般的な成人男性の掌長（手首のしわから指の付け根まで）は約 $100\text{mm} - 110\text{mm}$ である。
*   **デバイスの実測値**: Glove80の総奥行きは $206\text{mm}$ であり、パームレストなしの状態が $168\text{mm}$ であることから、パームレストの深さは約 $38\text{mm} - 40\text{mm}$ と推定される。パームレストの端からホーム列までの物理的距離は $85\text{mm} - 95\text{mm}$ に設定されている。

### 3.2 パームレストの設計思想と「0.6x Hand Length」の経験則

パームサポートの奥行き設計における一つの指針として、以下のヒューリスティック（経験則）が提唱されている。

*   **理想的なサポート深度**: 手の長さの約 0.6倍。
*   **具体的な数値**: 手の長さが $180\text{mm}$ の場合、約 $108\text{mm}$ のサポート面が確保されることが望ましい。

また、パームレストの高さは、キーボードのフロントエッジ（ケースの端）の高さと「±1.5mm以内」で一致させる必要がある。格闘ゲーム特有の「激しい打鍵」を考慮すると、柔らかすぎるメモリーフォームは沈み込みによって手首を背屈させてしまうため、高密度のゲルや硬めのフォーム、あるいは木製やアクリル製の硬質な素材が、姿勢の矯正と力の伝達効率の面で有利に働く。

## 4. 格闘ゲーム専用レバーレスにおける人間工学的設計の特異点

汎用的なエルゴノミクスキーボードと格闘ゲーム用デバイスの最大の違いは、入力の「強さ」と「同時押し」の頻度にある。

### 4.1 スイッチの物理的特性とストロークの最適化

格闘ゲームでは、1フレーム（1/60秒）の入力を競うため、アクチュエーションポイント（反応点）の短さが重視される。

*   **キートラベル（Total Travel）**: 一般的なスイッチは $4.0\text{mm}$ だが、格闘ゲームでは $3.0\text{mm} - 3.5\text{mm}$ 程度のショートストロークが好まれる。
*   **底打ち（Bottoming out）への対策**: 競技者は一日に数千から数万回の打鍵を行う。Gateron Brown（押し下げ圧 $45\text{g} - 55\text{g}$）や、さらに軽い Kailh Box Pink（$35\text{g}$）などが、長時間の集中力を維持するために選択される。

### 4.2 特殊レイアウト：Azealと「BattleHut」に見る革新

従来のHitboxレイアウトに疑問を呈する設計者たちは、より「手指の役割」を明確にした配置を模索している。

*   **BattleHut（カスタムレバーレス）**: 10個のアクションボタンを、手のサイズに合わせてコンパクトに配置。右手の親指ボタンには「Up（ジャンプ）」以外にも「MK（中キック）」や「HK（大キック）」を割り当て、同時押しの利便性を向上させている。
*   **左手用8ボタンDパッド**: 十字キーの代わりに8つのボタンを配置し、斜め入力を一指で完結させる設計。これにより、レバーレス特有の「指の体操」を減らし、複雑なコマンド（214や421など）をより滑らかに実行可能にしている。

## 5. 自作コミュニティとオープンソース・パラメータの解析

GitHub上の「Dactyl Manuform」系リポジトリは、数千人のユーザーによる調整結果が反映された「人間工学の宝庫」である。

### 5.1 パラメータ化された設計の強み

Dactyl Manuformは Clojure で記述されており、以下の変数を変更することで、個々のユーザーに最適化された STL ファイルを生成できる。

*   `rows` / `columns`: 手のサイズに応じて 4x5 から 6x7 まで調整可能。
*   `row-curvature` / `column-curvature`: 指の曲がり具合を定義。
*   `column-offsets`: 指のスタッガー（段差）を定義。中指に対して小指をどれだけ手前に配置するか（Pinky Stagger）は、小指の短さをカバーするために非常に重要である。

### 5.2 実際の製作におけるコミュニティの知見

Reddit（r/ErgoMechKeyboards）や Geekhack での議論によれば、初心者が陥りやすいミスとして「既存のキーボードを模倣しすぎる」ことが挙げられる。曲面設計を導入する場合、以下の手順が推奨される。

1.  **プロトタイプ作成**: 厚紙や粘土で自分の手の「機能的静止位」を型取り、大まかなボタン位置をマーキングする。
2.  **テストプリント**: 筐体全体ではなく、特定の列（中指列など）だけをプリントし、曲率 $R$ が自分の指に合っているか確認する。
3.  **配線の簡略化**: 立体筐体ではプリント基板が使えないため、Amoeba PCB（単一スイッチ用基板）や銅線による手配線が必要となる。この際、配線の厚みがケース内の干渉を引き起こさないよう、ケースの高さを $4\text{mm} - 5\text{mm}$ 余裕を持って設計することが重要である。

## 結論：次世代レバーレスのための設計ロードマップ

以上の調査に基づき、自作エルゴノミクス・レバーレスコントローラーのための推奨設計パラメータを統合する。

*   **親指ユニットの最適化**: 人差し指のホーム面から **12mm** 低く配置し、親指の対立運動に合わせて **20度** の内側傾斜を与える。
*   **キーウェルの構築**: 曲率半径 **R=60mm** 前後の円弧（または螺旋状）の断面を持ち、各指の長さに合わせて **5mm - 8mm** の列スタッガーを設定する。
*   **姿勢の制御**: **20度** のテント角と **-10度** のネガティブチルトを組み合わせ、前腕と手首のニュートラルを維持する。
*   **パームサポート**: 豆状骨からホーム列まで **90mm** 前後の距離を確保し、打鍵時の安定した支点を提供する。

これらの数値は、人間の解剖学的構造と、過酷な格闘ゲームの操作要求を橋渡しするものである。平面から曲面への移行は、習得に時間を要する（Adjustment Period）ものの、一度身体が適合すれば、これまでにない速度での入力と、怪我のリスクを最小化した長時間の競技活動を可能にする。設計者は、単なるスペックの追求ではなく、使用者の「手の延長」としてのデバイスを構築するために、これらのパラメータを自身の身体感覚と照らし合わせて調整し続けるべきである。

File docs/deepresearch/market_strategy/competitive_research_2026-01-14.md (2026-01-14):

# 次世代エルゴノミクス・レバーレスコントローラー市場における競合調査と「Project Hanoji」の市場投入戦略
（Gemini Deep Research 出力の収録）

- 調査日: 2026年1月14日
- リサーチャー: AI分析官（Gemini）
- 注記: 本文は Gemini の出力をベースに収録しています（リンクの Markdown 化・表の体裁調整など、体裁のみ最小限整形）。

---

## 0. エグゼクティブサマリー

格闘ゲーム用デバイス市場は、物理レバーからレバーレス（ボタン式）への歴史的な移行期にあり、入力速度の極大化と同時に「身体への負担」が新たな課題として浮上している。Project Hanojiが掲げる「回外姿勢とテンティング」は、従来の平面型デバイスが引き起こす手首の尺側偏位や前腕のねじれを解消する強力な価値仮説であり、特に長時間練習を行う競技者やエルゴノミクス志向のデスクワーカー層に深く刺さるポテンシャルを有している。現在、市場はRazerやVictrixのような大手メーカーの「PS5認証・薄型・広面積モデル」と、Haute42に代表される「低価格・オープンソース基板・多ボタンモデル」に分断されている。一方で、身体的負担を解決する分割型や傾斜型はMavercadeのKeebWarriorやBishop\|SelectのMaestroなど、極めてニッチかつ高価格、あるいは入手性の低い小規模生産に留まっている。本報告書では、これら25件以上の競合分析に基づき、Project Hanojiが取るべき「可変テンティング」と「膝上安定性」を両立した差別化戦略、およびリスク管理と価格設計を詳述する。

## 1. 競合マップ：カテゴリ別の市場構造

レバーレスコントローラー市場は、その形状と技術的アプローチによって以下の5つの主要カテゴリに分類できる。

### 1.1. 平面レバーレス（スタンダード/薄型）

市場の主流であり、Razer、Victrix、Hit Box、Haute42、JunkFood Arcades（Snack Box）などが含まれる。これらは「携帯性」や「入力精度」を最優先しており、エルゴノミクスについては「薄型化による手首の反りの軽減」という消極的なアプローチに留まっている。

### 1.2. エルゴノミクス一体型（傾斜・スロープ）

筐体自体に傾斜や曲線を持たせたタイプ。Victrix Pro FS-12（6.28度の傾斜）や、木製高級機のMaestro（左右独立傾斜）が代表的である。手首の角度を自然に保とうとする試みだが、角度が固定されているため、ユーザー個々の体格への適合性に課題がある。

### 1.3. 分割（スプリット）・モジュール型

左右のボタンユニットが物理的に分離、あるいはヒンジで接続されているタイプ。MavercadeのKeebWarriorがこのカテゴリの旗手であり、肩幅に合わせた配置が可能だが、高角度のテンティング（傾斜）を実現するには別途スタンドや工夫が必要となる。

### 1.4. キーボード流用・WASD型

MixboxやMavercadeのKeebFighterのように、キーボードのキースイッチやWASD配列をそのまま持ち込んだタイプ。PCゲーマーには親しみやすいが、WASD特有の指の上下移動が格闘ゲームにおける「thumb jump（親指でジャンプ）」よりも効率で劣るという指摘も多い。

### 1.5. DIY・オープンソース系

GitHubで公開されているFlatboxや、3Dプリント筐体を用いたBOOTH/Etsyの個人販売品。価格が安く、特定のユーザーニーズ（特定のボタン配置など）に特化しているが、保証やサポート、PS5互換性に難がある場合が多い。

## 2. 競合リスト：25件の詳細概況

北米、欧州、日本市場における主要競合および注目の個人・小規模メーカー25件を抽出した。価格や仕様は2025年〜2026年時点の最新情報を反映している。

| 製品名 | メーカー | 販売チャネル | 価格帯 (USD/JPY) | 特徴 | 対応機種 | 入手性 |
|---|---|---|---|---|---|---|
| Kitsune | Razer | 公式/Amazon | $299 / ¥48,000 | PS5認証、光学式、19mm薄型 | PS5, PC | 高 |
| Pro FS-12 | Victrix | 公式/Amazon | $399 / ¥60,000 | 6.28度傾斜、アルミ筐体 | PS5, PS4, PC | 中 |
| Hit Box | Hit Box | 公式/代理店 | $249 / ¥40,000 | レバーレスの元祖、三和ボタン | PC, PS4 | 中 |
| Snack Box Micro | JunkFood | 公式 | $185 - $230 | 超小型、アプリ連動、PS5ネイティブ | PS5, XSX, PC | 低 |
| T16 / R16 | Haute42 | AliExpress/Amazon | $50 - $90 | 圧倒的安価、GP2040-CE、液晶 | PC, Switch | 高 |
| M Plus | Haute42 | AliExpress | $100 - $150 | アルミ筐体、質感、多ボタン | PC, Switch | 高 |
| KeebWarrior | Mavercade | 公式 (CA) | $103 - $177 | 分離型、ヒンジ、RJ45接続 | PC, Switch | 低 |
| Maestro | Bishop\|Select | 公式/Etsy | $699 - $739 | 木製高級機、左右独立斜面 | PS5, PC | 極低 |
| Ultra Box | Punk Workshop | 公式/AliExpress | $130 - $280 | 磁気開閉天板、独自静音ボタン | PC, Switch | 中 |
| KeebFighter | Mavercade | 公式 (CA) | $130 - $166 | キーボード風、アクリル積層 | PC, Switch | 中 |
| Flatbox | (Open Source) | BOOTH/Etsy | ¥10,000 - ¥20,000 | 3Dプリント、格安、コミュニティ製 | PC, Switch | 中 |
| Faust / Bridget | SGF Devices | 公式 (US) | $120 - $200 | 3Dプリント、質実剛健 | PC, Switch | 中 |
| Granola | Granola Arcade | 公式 (US) | $100 - $150 | 米国製、独自PCB、薄型 | PC, Switch | 中 |
| ScrubTier | ScrubTier | 公式 (UK) | $150 - $200 | 英国発、デザイン重視 | PC, Switch | 中 |
| Mixbox | Mixbox Arcade | 公式 | $250 - $300 | WASD配列のパイオニア | PC, PS4 | 中 |
| F700 Flat | Mayflash | Amazon | $150 / ¥23,000 | ワイヤレス、PS5パススルーポート | PS5, PC | 高 |
| Nolva | HORI | 公式 (日本) | ¥12,000 | 日本限定、エントリーモデル | PC | 高 |
| Slab Mini | Slab | Etsy | $95 | 3Dプリント、カスタマイズ性 | PC, Switch | 中 |
| Keybox Type 2 | Keybox | Etsy | $122 | 基板剥き出し、DIY感 | PC, Switch | 中 |
| RaidenBox | RaidenBox | Etsy | $189 | 高品質ケース、Snackbox代替 | PC, PS5 | 低 |
| SHINOGI | SAYA ARCADE | BOOTH | ¥29,800 | 日本発、洗練されたデザイン | PC, Switch | 低 |
| JumpHack04 | 蒼い工房 | BOOTH | ¥44,800 | 日本発、SF6特化多ボタン | PC, Switch | 低 |
| PocketXT V2 | (個人販売) | Etsy | $115 | 分割レイアウト、小型 | PC, PS4 | 低 |
| Maestro Prototype | Bishop\|Select | 公式 | $449 | Maestroの廉価/試作版 | PC | 極低 |
| KeebBrawler 04LP | Mavercade | 公式 | $170 | 大型、金属プレート、堅牢 | PC, Switch | 中 |

## 3. 上位10競合の詳細比較表

Project Hanojiの直接的な競合、または技術的ベンチマークとなる上位10件について、詳細な仕様を比較する。

| 項目 | Razer Kitsune | Victrix FS-12 | Snack Box Micro | Haute42 T16 | Mavercade KeebWarrior | Bishop\|Select Maestro | Punk Workshop M | Mayflash F700 Flat | SGF Devices Faust | Project Hanoji (仮) |
|---|---|---|---|---|---|---|---|---|---|---|
| 形状 | 極薄一体型 | 大型一体型 | 超小型一体型 | 中型薄型一体型 | 分割・ヒンジ型 | 左右独立傾斜一体型 | 中型薄型一体型 | 大型厚型一体型 | 小型薄型一体型 | 分割・テンティング型 |
| 角度 | 0度 | 6.28度固定 | 0度 | 0度 | 可変(ヒンジ/別売脚) | 30度傾斜(左右) | 0度 | 0度 | 0度 | 15-30度(目標) |
| サイズ | 338x239x19mm | 416x292x63mm | 254x127x13mm | 296x196x15mm | 148x138x14mm (片) | 約300x200x57mm | 300x200x27mm | 約350x240x60mm | 185x115x15mm | 未定(小型分割想定) |
| 重量 | 約0.8kg | 2.5kg | 0.36kg | 約0.9kg | 0.66kg (両) | 約1.5kg | 約1.5kg | 約2.0kg | 約0.4kg | 0.5-1.0kg(目標) |
| スイッチ | 光学ロープロ | 三和電子 | Kailh Amber | Kailh V2 | Kailh Choc V2 | Crown SDB-202 MX | 独自静音V1 | 三和電子 | Kailh Choc | Cherry MX/静音推奨 |
| Hotswap | × | △ (配線) | 〇 | 〇 | 〇 | △ (配線) | 〇 | △ (配線) | 〇 | 〇 |
| SOCD | 4モード切替 | 標準(CPT準拠) | アプリ制御 | GP2040-CE | GP2040-CE | GP2040-CE/Brook | 独自基板 | 標準切替 | GP2040-CE | GP2040-CE |
| 基板 | Razer独自 | Victrix独自 | M3 PCB (独自) | RP2040系 | RP2040系 | Brook/RP2040 | PKB 2040 | Mayflash独自 | RP2040系 | RP2040系 |
| 自由度 | 低 | 低 | 低 | 中 (多ボタン) | 高 (分離/WASD可) | 中 (傾斜固定) | 中 (ボタン選択) | 低 | 中 | 高 (角度/配置) |
| 素材 | アルミ天板 | アルミ削出 | PC/アクリル | アクリル積層 | 3Dプリント/鉄 | 高級オーク材 | カーボン/アクリル | 樹脂 | 3Dプリント | 3Dプリント/小ロット |
| 組立 | 完成品 | 完成品 | 完成品 | 完成品 | 完成品 | 完成品 | 完成品 | 完成品 | 完成品 | 完成品/キット両案 |
| 保証 | 1年(大手) | 1年(大手) | 短期間 | 短期間 | 30日/返品不可 | 手作り品質保証 | 返品不可 | 1年 | 30日 | 初期不良対応 |
| コミュニティ | 巨大 | 巨大 | 活発(Discord) | 活発(オープン) | 中規模 | 小規模 | 中規模 | 巨大 | 中規模 | 新規構築 |

## 4. 「エルゴノミクス」訴求メッセージの分析

「エルゴノミクス」を前面に押し出している競合他社が、どのようなコピーや構成でユーザーに訴求しているかを分析する。

### 4.1. 代表的な訴求メッセージと刺さっているポイント

- **Victrix Pro FS-12：競技パフォーマンスへの還元**
  - メッセージ: 「Integrated 6.28° wrist slope to help reduce fatigue（疲労軽減のための6.28度の一体型スロープ）」
  - 分析: 単なる快適さではなく、「疲労軽減が精度維持（＝勝利）に直結する」という競技的メリットとして昇華させている。
- **Razer Kitsune：薄型化による手首の自然な角度**
  - メッセージ: 「Slim, portable form factor... lower execution time（スリムでポータブル...実行時間の短縮）」
  - 分析: 筐体の薄さを「手首を曲げずに済む＝エルゴノミクス」と定義。厚いアケコンに対する優位性を強調している。
- **Bishop\|Select Maestro：健康と高級感の両立**
  - メッセージ: 「Kiss wrist pain goodbye... handcrafted ergonomic style（手首の痛みにおさらば...手作りのエルゴスタイル）」
  - 分析: 開発者自身が慢性的疾患を抱えている背景を公開し、「痛みを知る者が作った救済の道具」というストーリー性で共感を得ている。
- **Mavercade KeebWarrior：姿勢の自由度と適応性**
  - メッセージ: 「Allows players to position the controllers in a natural stance（自然なスタンスで配置可能）」
  - 分析: 「肩幅に合わせて開く」という分割キーボードの成功体験を格ゲー市場に導入。既存の平面モデルの「窮屈さ」を不満点として逆手に取っている。

## 5. ユーザーの不満点の抽出と分析

RedditやYouTubeのレビューから、現行デバイスに対する身体的・操作的・ビジネス的不満を抽出した。

### 5.1. 身体的な痛みと疲労

- **回内（Pronation）による緊張**: 「手のひらを下に向け、手首を平らに固定する姿勢は非常に不自然で、腕の筋肉を常に緊張させている。これが原因で短時間のプレイでも痛みが出る」
- **尺側偏位（Ulnar Deviation）**: 「ボタンが密集しているため、手首を外側に曲げる姿勢を強いられる。これが長期間続くと手根管症候群のリスクが高まる」
- **指の疲労と打鍵強度**: 「格闘ゲームはボタンを強く叩く傾向があり、ストロークが長すぎたり、跳ね返りが強すぎると指の関節を痛める」

### 5.2. 操作性と携帯性のジレンマ

- **膝上プレイの不安定さ**: 「薄型軽量モデル（Snack Box等）は持ち運びには最高だが、膝の上でプレイすると安定せず、激しい操作でコントローラーが動いてしまう」
- **騒音問題**: 「集合住宅や家族がいる環境では、アケコン特有の打鍵音が苦情の原因になる。静音ボタンは必須だが、標準で搭載されているモデルは少ない」
- **ボタン数の不足**: 「SF6のようなモダンな操作系では、追加のボタン（L3/R3/Fn）が独立していないと、トレーニングモードの効率が著しく下がる」

### 5.3. ビジネス・サポート面

- **PS5互換性の不安定さ**: 「パススルー認証（GP2040-CE）はいつソニーに塞がれるか不安だ。純正の認証チップを積んだ高額モデルか、安価なドングル併用かの選択を迫られるのがストレス」
- **納期と入手性**: 「小規模メーカーの優秀な製品は常に『Sold Out』であり、eBayなどで転売価格で買うしかない」

## 6. Project Hanoji が取るべき差別化ポイント案

以上の調査結果を踏まえ、Project Hanojiが後発・小規模メーカーとして勝つための戦略的差別化ポイントを提案する。

- **「回外（Supination）」を促進する高角度テンティング**
  - 根拠: 既存のVictrix（6.28度）やMaestro（約30度）は固定角度である。Hanojiは、3Dプリントの利点を活かし、ユーザーが自身の腕の太さや座り方に合わせて角度を物理的に調整、あるいは交換可能な「ウェッジ（楔）」システムを採用すべきである。
- **「膝上」での安定性を担保するベースプレート・システム**
  - 根拠: 分割型の弱点は膝上での安定性にある。分割したユニットを、ユーザーの肩幅に合わせた位置で固定できる「連結用ベースプレート（またはクッション）」をオプション提供することで、競技シーンでの実用性を飛躍的に高める。
- **「静音特化」と「押し心地」のカスタマイズ**
  - 根拠: 深夜プレイ層の不満は深刻である。標準でKailh Choc V2 Silent等の静音スイッチを採用し、かつ打鍵衝撃を吸収するダンパー構造を筐体に組み込むことで、「最も静かなエルゴノミクス・レバーレス」としてのポジションを確立する。
- **物理L3/R3およびカスタムマクロボタンの独立配置**
  - 根拠: SF6のトレーニング環境への不満に応える。標準の12〜16ボタンに加え、筐体上部や側面に、ブラインドタッチを阻害しない配置で追加ボタンを設け、利便性を差別化する。
- **オープンソース・エコシステムとの親和性と透明性**
  - 根拠: GP2040-CEのコミュニティは強大である。独自基板を開発するのではなく、実績のあるRP2040系基板を使用しつつ、ファームウェアのカスタム設定をGitHub等で公開することで、技術志向のユーザー層からの信頼を獲得する。

## 7. 価格帯提案

競合他社の価格構造とユーザーの支払意欲に基づき、3つのプランを提案する。

| プラン | 提案価格 | 構成内容 | 根拠 |
|---|---|---|---|
| 低：DIY/スターター | ¥18,000 - ¥25,000 | 3Dプリント筐体（未塗装/積層痕あり）、未組立キット、RP2040基板、基本ボタン。 | Haute42（$60〜）よりもエルゴノミクス価値が高く、Flatbox（¥1.5万）に近い価格設定で参入障壁を下げる。 |
| 中：競技用標準モデル | ¥35,000 - ¥48,000 | 表面処理済み筐体、静音スイッチ標準装備、PS5パススルーポート（ドングル別売）、専用ベースプレート。 | Razer Kitsune（¥4.8万）と同等の価格だが、「分割・テンティング」という機能的優位性で差別化。 |
| 高：プレミアム・オーダー | ¥65,000 - ¥85,000 | CNC削り出しパーツ/高級材の混合、PS5認証基板、セミオーダーのボタン配置、永久修理保証、キャリングケース。 | Victrix（¥6万）やMaestro（$699〜）のターゲット層に対し、完全に自身の身体に適合した「一生モノ」の価値を提供。 |

## 8. リスクと参入障壁

事業の持続性を脅かす要因と、その対策を整理する。

- **法務・認証リスク**
  - 米国での販売にはFCC、欧州にはCE、日本にはPSE（電源・電池含む場合）や技適（無線の場合）が必要となる。
  - 対策: 初期は有線接続のみに限定し、かつ「電子部品を含まない筐体キット」としての販売、あるいは認証済みのRP2040モジュールを使用することで、法的なコンプライアンスコストを最小化する。
- **PS5の互換性遮断**
  - ソニーがサードパーティ製デバイスやパススルー認証を無効化する恐れがある。
  - 対策: 公式ライセンス品の分解・組み込み（パッドハック）をサポートする設計にするか、Brook社等の信頼性の高い変換アダプタの使用を前提としたマーケティングを行う。
- **模倣と知財の限界**
  - 形状の模倣は容易であり、3Dプリントデータが流出・リバースエンジニアリングされるリスクがある。
  - 対策: 物理的な形状だけでなく、「ファームウェアの最適化」や「ユーザーコミュニティへのサポート」といった非定型的なサービスで差別化を図る。
- **供給網の不安定さ**
  - 3Dプリンタの故障やスイッチの欠品により納期が遅延し、ユーザーの信頼を失うリスク。
  - 対策: 在庫販売を基本とし、受注生産（Group Buy）形式を取る場合は、進捗をSNSで透明性高く報告する体制を整える。

## 9. 参考リンク集

- [Mavercade (KeebWarrior)](https://mavercade.com/) - 分割・ヒンジ型のベンチマーク
- [Bishop\|Select (Maestro)](https://bishopselect.com/) - エルゴノミクス高級機の訴求方法
- [GP2040-CE Official](https://gp2040-ce.info/) - 低遅延オープンソースファームウェアの基盤
- [Razer Kitsune Official](https://www.razer.com/console-controllers/razer-kitsune) - 薄型化によるエルゴ訴求の極致
- [Printables (Splitbox)](https://www.printables.com/model/513335-splitbox) - 3Dプリント筐体の設計思想

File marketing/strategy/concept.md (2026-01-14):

# コンセプト & ターゲット戦略

## 1. プロジェクト理念 (Core Philosophy)
**「Project Hanoji: ゲーミング姿勢の再定義」**

Hanojiは、単なる入力デバイスではなく、プレイヤーとゲームを持続可能につなぐインターフェースです。
「八の字」を描く自然な腕の角度（回外姿勢）に着目し、既存の平面レバーレスコントローラーが抱える身体的負荷（回内によるねじれ）を解消します。

> **由来**: 腕の配置やコントローラーの形状が漢数字の「八」になることから命名。末広がりで縁起が良いという意味も込める。

## 2. 解決する課題 (The Problem)
既存の一般的なレバーレスコントローラー（平面型）には、構造上の課題がありました。

- **強制される「回内」姿勢**: 手のひらを机に対して水平（真下）に向けるため、前腕の骨（橈骨と尺骨）が交差し、筋肉と神経が常に緊張状態になる。
- **手首への圧迫**: 平面操作では手首を反らせる必要があり、腱への負担が大きい。また、筐体の角に手首が当たり、神経圧迫（手根管症候群等のリスク）につながる。
- **パフォーマンスの低下**: 身体の緊張は、長時間のプレイにおいて集中力の欠如や操作精度の低下、疲労の蓄積を招く。

## 3. ソリューション (The Solution)
**「八の字」エルゴノミクスデザイン**

- **自然な傾斜（テンティング）**: 左右のボタン配置面を山型（八の字）に傾斜させることで、前腕を自然な角度（ニュートラルな回外状態）で保ちます。
- **負荷からの解放**: 腕のねじれを解き放つことで、長時間のトレーニングやトーナメントシーンでも、身体へのダメージを最小限に抑えます。
- **サステナブルなゲーミング**: 「痛みで引退するプレイヤーを減らす」。長く、高いパフォーマンスでプレイし続けるためのデバイスを提供します。

## 4. ターゲットペルソナ (Target Persona)

### ① The Grinder（ストイックな競技者）
- **属性**: 20代後半〜40代。格闘ゲーム（SF6, 鉄拳, GGST等）のランクマッチや大会に積極的に参加するコアゲーマー。
- **行動**: 毎日数時間の練習、週末の長時間プレイが日課。
- **悩み**: 手首や指の慢性的な痛み、腱鞘炎の不安、肩こり。年齢とともに身体のケアや「いつまで続けられるか」という不安を感じ始めている。
- **インサイト**: 「練習量は落としたくないが、身体はいたわりたい」「痛みのせいで負けたくない」。

### ② The Ergonomics Seeker（機能性・健康重視層）
- **属性**: エンジニア、プログラマー、デスクワーカーなど、普段からPC作業が多い層。自作キーボード（分割キーボード）に関心がある層と重複。
- **行動**: 効率化や健康のためのツールには投資を惜しまない。
- **インサイト**: 「理にかなった形状が好き」「エルゴノミクスという言葉に弱い」。

## 5. マーケティングの軸 (Key Messaging)
- **機能的価値**: 「回外姿勢により、手首・腕の負担が激減する」「長時間プレイしても疲れない」。
- **情緒的価値**: 「一生ゲームを楽しむためのパートナー」「身体を大切にする賢いゲーマーの選択」。
- **キャッチコピー案**:
    - "Unleash Comfort. （快適さを解き放て）"
    - "Play Natural, Play Longer. （あるがままに、より長く）"

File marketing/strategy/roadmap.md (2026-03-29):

# 開発・販売ロードマップ

## Phase 1: 試作開発 & コンセプト検証 (現在 〜 1ヶ月後目安)
**目標: 自分が納得して使えるプロトタイプの完成**
- [ ] **ハードウェア**
    - [ ] 3Dモデル (Fusion 360) のブラッシュアップ
        - [ ] 手首置き（パームレスト）部分の形状調整
        - [ ] ボタンホールの公差調整
    - [ ] テストプリント & 組立検証（v5 進行中）
    - [ ] 実際にゲームで使用してフィードバック収集（操作性、疲労度）
- [ ] **マーケティング**
    - [x] ターゲット層（ペルソナ）の詳細詰め（完了）
    - [x] 競合調査レポート作成（2026-01-14：完了）
    - [ ] プロジェクト名のロゴ案作成（ラフでOK）

## Phase 2: 情報発信 & ファンベース構築 (1ヶ月後 〜 2ヶ月後目安)
**目標: 「欲しい！」と思ってくれるフォロワーを集める**
- [x] **コンテンツ**
    - [x] ブログ/Noteの開設（https://note.com/arly_3_atelier）
    - [x] 記事投稿: v1フィードバック記事「自作レバーレス製作記 Vol.1：理想の角度を求めて失敗した話」
    - [x] SNS (X/Twitter) アカウント開設（https://x.com/_arly_3_atelier）
    - [ ] 開発風景（3Dモデル画面、プリント中の動画）の投稿開始
    - [ ] 記事投稿 Vol.2以降（v2〜v5の開発ログ）
- [ ] **コミュニティ**
    - [ ] Discordサーバーの開設（必要であれば、テスター募集用）

## Phase 3: 製品化準備 (2ヶ月後 〜 3ヶ月後目安)
**目標: 販売可能な品質と生産体制の確立**
- [ ] **ハードウェア**
    - [ ] 量産用設計への移行（3Dプリント品として売るか、金型等を考えるか決定）
    - [ ] 部品選定（キースイッチ、キーキャップ、マイコン基板、配線材）
    - [ ] サプライヤー確保と発注
- [ ] **ビジネス**
    - [ ] 原価計算（BOM作成）
    - [ ] 販売価格の決定
    - [ ] パッケージ（箱、梱包材）の選定・デザイン
    - [ ] 配送方法の選定（クリックポスト、宅急便コンパクト等）

## Phase 4: ローンチ (3ヶ月後以降)
**目標: 初回ロット完売**
- [ ] **販売**
    - [ ] ECサイト構築（BOOTH, Shopify, BASE等）
    - [ ] 商品写真撮影
    - [ ] 商品ページ公開
- [ ] **プロモーション**
    - [ ] 販売開始日時の告知
    - [ ] ローンチ記念キャンペーン（あれば）

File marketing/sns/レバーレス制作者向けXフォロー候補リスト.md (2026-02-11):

# 自作レバーレスコントローラー販売を目指す個人クリエイター向け Xフォロー候補リスト

本リストは「自作レバーレスコントローラーを将来的に販売する」個人クリエイターが、制作と販売に必要な情報を効率よく収集するためのXアカウントフォロー候補です。技術寄り／プロセス寄りの方針で、情報の密度と実用性を優先して選定しています。

---

## カテゴリ1：自作レバーレス／自作アケコン制作者

### 1. ぽめ
- **@ID:** @pomegd
- **カテゴリ:** 自作レバーレス制作者／基板設計
- **フォロー理由:** KiCadで基板設計から薄型hitboxまで一貫して制作し、GP2040やUFBを活用した制作過程をブログとツイートで丁寧に記録している[^6][^10]
- **代表的な投稿:** Raspberry Pi Pico＋GP2040で薄型レバーレスを自作する過程をBOOTHで頒布含め公開。KiCadデータ・回路図・ファームウェアをすべてオープンにしている[^10]

### 2. 碧井いそめ
- **@ID:** @isomeaoi
- **カテゴリ:** 自作レバーレス制作者／販売工房
- **フォロー理由:** 碧井工房代表としてスト6向けレバーレス「JumpHack」を設計・販売し、YouTubeでも制作工程を配信[^11][^47]
- **代表的な投稿:** 薄型機「07」の試作準備過程や、自作レバーアケコンのフレーム共通化の試作過程を写真付きで記録[^86][^47]

### 3. makisuke（くろまき工房）
- **@ID:** @kuromakisuke
- **カテゴリ:** 自作アケコン制作者／販売工房
- **フォロー理由:** アクリル加工と3Dプリンターを駆使した独自設計の桜/夜桜ケースが人気。BOOTHで自作小型アケコン用の柱パーツなども販売[^39][^18]
- **代表的な投稿:** アクリルデザインのレバーレスケース新作の告知と制作過程。販売前のX事前告知が恒例[^18]

### 4. 格ゲーマーささき
- **@ID:** @dnm3rd
- **カテゴリ:** 自作レバーレス解説者
- **フォロー理由:** 「誰でも作れる最強自作レバーレスコントローラー最適解」動画で自作入門の決定版を発信[^5]
- **代表的な投稿:** 格安レバーレスキットの組み立て解説動画（521いいね）が広く参照されている[^5]

### 5. Shiryl-shi
- **@ID:** @Nikogel360
- **カテゴリ:** 自作アケコン界隈のハブ
- **フォロー理由:** 国内外のアケコン制作者・販売者・パーツショップを網羅したリンク集を作成・管理。業界の情報流通の中心的存在[^18][^19]
- **代表的な投稿:** 「現在自作アケコンを作ってるorパーツを出してる個人or業社をまとめた方が良い？」の投票から始まったリンク集記事[^19]

### 6. 東郷
- **@ID:** @TogoHashibiroko
- **カテゴリ:** アケコン制作・販売
- **フォロー理由:** プラモ、CG制作も行う多趣味なクリエイターで、アケコン販売中[^16]
- **代表的な投稿:** プロフィールに「アケコン販売中！」と明記し、制作・販売の過程を投稿

### 7. レト
- **@ID:** @reto9696kazu
- **カテゴリ:** 自作アケコンパーツ制作
- **フォロー理由:** BOOTHにてベアリングアクチュエーターや磁気ボタンなど独自パーツを販売。パーツ設計に特化した情報源[^17]
- **代表的な投稿:** アケコンパーツの自作過程と試行錯誤の記録

### 8. moimate（Rushbox Click）
- **@ID:** @moimate_inc
- **カテゴリ:** レバーレス開発メーカー
- **フォロー理由:** 「キーボード設計のノウハウを活かしたアケコン開発」というコンセプトで、キーボード×アケコンの知見融合を実践[^12]
- **代表的な投稿:** キーボード設計のノウハウをアケコンに活かす開発思想の発信[^12]

### 9. IORI | 伊織（伊織技研）
- **@ID:** @iori_sf
- **カテゴリ:** 基板設計・アケコン制作
- **フォロー理由:** Precision Fighting Board 8000Hz（ポーリングレート8000Hz対応、遅延0.125ms）を設計・販売。3Dプリントによる自作レバーレスの磁石開閉化など実用TIPSも発信[^96][^110]
- **代表的な投稿:** アケコンの蓋を磁石開閉にする工程記録、note「IORI's Hack Logs」での技術共有[^110]

### 10. SAYA ARCADE
- **@ID:** @SAYA_ARCADE
- **カテゴリ:** レバーレス制作・販売
- **フォロー理由:** 11ボタン薄型レバーレス「SHINOGI」を独自配列で設計・販売。開発報告をXで丁寧に行う[^82][^83]
- **代表的な投稿:** 「【開発報告】11ボタンレバーレス開発もいよいよ終盤。カーボンプレートが届きました」など開発進捗を写真付きで発信[^82]

### 11. jfedor
- **@ID:** @jfedor2（GitHub中心）
- **カテゴリ:** オープンソース レバーレス設計
- **フォロー理由:** Flatbox（低プロファイルhitboxレイアウト）のオリジナル設計者。3Dプリントモデル、PCBデータ、コードをすべてオープンソースで公開[^122]
- **代表的な投稿:** GitHubでFlatbox rev1〜rev9までの全リビジョンをKailh Chocスイッチ対応で公開[^122]

---

## カテゴリ2：自作キーボード制作者（設計・組立系）

### 12. foostan
- **@ID:** @foostan
- **カテゴリ:** 自作キーボード設計者
- **フォロー理由:** 自作キーボード界のベストセラー「Corne（crkbd）」設計者。SREとキーボードデザインを兼務し、基板設計・ケース設計のノウハウが非常に豊富[^64][^73]
- **代表的な投稿:** Cornelius Low-profileの新設計やCorne ULPの構想を写真付きで発信。BOOTHのpskbd.booth.pmで頒布[^64]

### 13. びあっこ
- **@ID:** @Biacco42
- **カテゴリ:** 自作キーボード設計者／コミュニティ運営
- **フォロー理由:** Ergo42設計者であり、Self-Made Keyboards in Japan Discordサーバーの開設者。日本の自作キーボードコミュニティの草分け的存在[^68][^74]
- **代表的な投稿:** 4x7 split keyboard Ergo42の制作失敗談やコミケでの同人誌頒布[^68]

### 14. ふく
- **@ID:** @yfuku_（キーボード専用: @dailycraftkbd）
- **カテゴリ:** 自作キーボード設計者
- **フォロー理由:** ソフトウェアエンジニアでありながら自作キーボードを設計・製作。Daily Craft Keyboardとして活動[^20]
- **代表的な投稿:** 自作キーボードの設計プロセスと完成品の紹介

### 15. aki27
- **@ID:** @aki27kbd
- **カテゴリ:** 自作キーボード設計者
- **フォロー理由:** トラックボール内蔵の自作キーボード「cocot46plus」を設計。設計に至った経緯とこだわりを詳細に記録[^69]
- **代表的な投稿:** cocot46plusの設計経緯と技術的こだわりを紹介する記事を公開[^69]

### 16. e3w2q
- **@ID:** @e3w2q
- **カテゴリ:** 自作キーボードコミュニティ貢献者
- **フォロー理由:** 自作キーボードアドベントカレンダーの記事をまとめ、各制作者の作品にコメントを付ける活動を継続[^52]
- **代表的な投稿:** アドベントカレンダー記事の横断的レビューと感想

### 17. 蓮乃 紫
- **@ID:** @piroridon
- **カテゴリ:** 自作キーボード設計者
- **フォロー理由:** 独自のLotus配列を考案し、Akashaキーボードを設計。イベント出展やnoteでの設計体験記も発信[^23]
- **代表的な投稿:** 「わたしの自作キーボードはここから！」noteでLotus配列の考案からキーボード完成までのプロセスを公開[^23]

### 18. 天高工房
- **@ID:** @skyhigh_works
- **カテゴリ:** 自作キーボード設計者
- **フォロー理由:** HHKBレイアウトの分割キーボードなどを設計・試作。基板の試作放出なども行う[^77][^42]
- **代表的な投稿:** 自作キーボードの基板写真と制作過程の投稿[^77]

### 19. ゆかり
- **@ID:** @eucalyn_
- **カテゴリ:** 自作キーボードイベント主催
- **フォロー理由:** 「天キー（天下一キーボードわいわい会）」主催者。日本の自作キーボードコミュニティの交流拠点を運営[^74]
- **代表的な投稿:** 天キーでのパネルディスカッションやキーボード展示の記録[^74]

### 20. ぺかそ
- **@ID:** @Pekaso
- **カテゴリ:** 自作キーボード設計者
- **フォロー理由:** Fortitude60を設計・制作。天キーの司会進行も務める[^74]
- **代表的な投稿:** Fortitude60の設計とビルドログ

### 21. 遊舎工房
- **@ID:** @yaboratory（店舗公式）
- **カテゴリ:** 自作キーボード専門店
- **フォロー理由:** 秋葉原の実店舗で自作キーボードキット販売、レーザーカットサービスも提供。自作デバイス全般の部品調達先として有用[^29][^45]
- **代表的な投稿:** 新入荷キットの紹介や工作室の活用事例[^45]

### 22. kazy
- **@ID:** @kazy_developer（推定）
- **カテゴリ:** 自作キーボード愛好家・レビュアー
- **フォロー理由:** 年間12台以上の自作キーボードを購入・ビルドし、各製品の詳細レビューとタイピング動画をTikTokでも発信[^26]
- **代表的な投稿:** 「2025年自作キーボード沼2年目の活動を振り返る」noteで多数のキーボードを紹介[^26]

---

## カテゴリ3：3Dプリント／造形・筐体設計の実務者

### 23. IORI | 伊織（再掲・筐体設計面）
- **@ID:** @iori_sf
- **カテゴリ:** 3Dプリント筐体設計
- **フォロー理由:** 自作レバーレスを3Dプリントで制作し、ネジ穴の耐久性向上のための磁石開閉化など実践的なTIPSを発信[^110]
- **代表的な投稿:** 「アケコンの蓋を磁石開閉にする」記事でネオジム磁石と鉄板シートを使った実装手順を公開[^110]

### 24. 画面端工房
- **@ID:** （BOOTHで「画面端工房」として活動）
- **カテゴリ:** 3Dプリント筐体販売
- **フォロー理由:** 自作レバーレスアケコン用のガワ（筐体）を3Dプリンタで制作・販売。板厚3.5mm、三和ボタン対応のサイズ設計[^127]
- **代表的な投稿:** 「試作段階なので若干仕様変更の可能性」と明記し、反復改善プロセスを公開[^127]

### 25. TheTrain
- **@ID:** @TheTrain24
- **カテゴリ:** 3Dプリント筐体設計／GP2040-CE開発
- **フォロー理由:** Open Stick Communityの主要メンバー。3Dプリント対応のModularケース、Slim、Astroなど多数のオープンソース筐体を設計。OSBボタンも設計[^115][^117]
- **代表的な投稿:** GP2040-CE v0.7.10リリース告知や、Open Stick Modular各バリエーションの設計公開[^117][^115]

### 26. アツユキ
- **@ID:** @aaa_tu
- **カテゴリ:** 3Dプリント×自作デバイス
- **フォロー理由:** Ergo42 Towelのカスタム3Dプリントケースを制作し、Fusion360での設計からプリント、組み立てまでの全工程を記録[^71]
- **代表的な投稿:** 純正アクリルケースをベースにFusion360で設計し、M4ネジ分割構造にした3Dプリントケースの制作過程[^71]

### 27. 大西拓磨（おさかなキーボード）
- **@ID:** @illlilllililill（推定）
- **カテゴリ:** キーボード筐体設計・3Dプリント
- **フォロー理由:** Blenderで鞍型キャップを考案し、3Dプリンターで造形。基板もKiCadで自作。制作過程の四苦八苦を率直に記録[^51]
- **代表的な投稿:** 「おさかなキーボードの現状」noteで、ステップスカルプチャーの鞍型キャップ考案から販売開始までのプロセス記録[^51]

---

## カテゴリ4：基板設計・電子工作（RP2040/GP2040-CE等）

### 28. inajob
- **@ID:** @ina_ani
- **カテゴリ:** RP2040基板設計・電子工作
- **フォロー理由:** RP2040を使った独自基板を公式リファレンスに従い設計・実装。ホットエアーガンでのQFN56実装やType-C端子の設計ノウハウを公開[^43]
- **代表的な投稿:** 「自分で設計するRP2040基板」ブログ記事で、回路設計から部品調達、実装テストまでの全工程を詳述[^43]

### 29. 74th
- **@ID:** @74th
- **カテゴリ:** RP2040基板キット販売／電子工作
- **フォロー理由:** RP2040手はんだ実装に挑戦する開発ボードキットをBOOTHで販売。KiCadプロジェクトファイルとPCBデータもGitHubで公開[^49]
- **代表的な投稿:** 「RP2040を手はんだ実装に挑戦する開発ボードキット」のBOOTH販売。実装方法の動画もYouTubeで公開[^49]

### 30. GP2040-CE公式（OpenStickCommunity）
- **@ID:** @OpenStickCommunity（GitHub/Discord中心）
- **カテゴリ:** ファームウェア開発コミュニティ
- **フォロー理由:** RP2040ベースのゲームパッドファームウェアGP2040-CEの開発元。SOCD cleaningモード・低遅延(0.76ms)・マルチプラットフォーム対応[^62][^113]
- **代表的な投稿:** リリースノートで各バージョンの機能追加・バグ修正を詳細に記載[^116]

### 31. FeralAI
- **@ID:** @FeralAI（GitHub中心）
- **カテゴリ:** GP2040オリジナル開発者
- **フォロー理由:** GP2040の原型を構築し、コミュニティプロジェクトの基盤を築いた[^62]
- **代表的な投稿:** GP2040のオリジナルリポジトリとMITライセンスでのオープンソース公開

### 32. ぽめ（再掲・基板設計面）
- **@ID:** @pomegd
- **カテゴリ:** KiCad基板設計
- **フォロー理由:** Pico Fighting BoardのKiCadデータを活用し、独自のGP2040対応基板を設計。UFBとGP2040両方の経験あり[^10]
- **代表的な投稿:** 「回路図もKiCad用のデータもソースもファームウェアも無料で公開されている」として、自作アケコン基板の全データを共有[^10]

### 33. GP2040-CEカスタムビルド解説者
- **@ID:** @taiseiue（推定、WSOFTブログ著者）
- **カテゴリ:** GP2040-CEカスタムビルド
- **フォロー理由:** GP2040-CEのGPIOピン変更・カスタムビルド手順を日本語で丁寧に解説[^7]
- **代表的な投稿:** 「GP2040-CEを自分でカスタマイズしてビルドする話」でWaveShare RP2040-ZeroのBoardConfig.h編集からビルドまでを詳述[^7]

### 34. SGFDevices
- **@ID:** @SGFDevices
- **カテゴリ:** GP2040-CE関連デバイス
- **フォロー理由:** GP2040-CEのPS4/PS5/Xbox対応パススルーやドングル関連の技術情報を発信[^112]
- **代表的な投稿:** Xbox互換性実装についての技術的説明やFAQ対応[^112]

---

## カテゴリ5：格ゲー有識者／大会運営（SOCDなどルールに詳しい）

### 35. takahata88
- **@ID:** @takahata88（note著者）
- **カテゴリ:** 格ゲーコントローラー規制の有識者
- **フォロー理由:** 「ガフロコン事件」を起点にSOCDクリーナーの歴史、CPTレギュレーション改定の経緯を時系列で詳細にまとめている[^31]
- **代表的な投稿:** 「ガフロコン事件がヒットボックス、レバーレスに与えた影響」noteで、SOCDの技術的背景からルール改定までを網羅[^31]

### 36. EVO Japan公式
- **@ID:** @evojapan_info
- **カテゴリ:** 格ゲー大会運営
- **フォロー理由:** 日本最大級の格闘ゲーム大会の公式アカウント。コントローラーレギュレーションの最新情報を把握するために必須[^102]
- **代表的な投稿:** 大会エントリー情報、トーナメント表、有志コミュニティ交流会のサポート情報[^102]

### 37. Shiryl-shi（再掲・大会ガイド面）
- **@ID:** @Nikogel360
- **カテゴリ:** 大会参加ガイド作成
- **フォロー理由:** 「EVO Japan 2025へのコントローラー持ち込みガイド」など、大会でのデバイス運用に関する実践的な情報を発信[^34]
- **代表的な投稿:** EVO Japan参加者向けの最新版ガイドをブログで公開。プール時間の被り対応など運営目線の知見も[^34]

### 38. AUTOMATON（ゲームメディア）
- **@ID:** @AUTOMATONJapan
- **カテゴリ:** 格ゲーニュース・コントローラー規制報道
- **フォロー理由:** ComboBreaker 2019のコントローラー使用禁止問題など、SOCDに関する技術的かつ公平な報道を行うゲームメディア[^32]
- **代表的な投稿:** 「海外の大型格闘ゲーム大会にて特定のコントローラーが使用禁止に」の詳報記事[^32]

### 39. LABO"GC"
- **@ID:** @labogc（推定）
- **カテゴリ:** コントローラー改造ガイドライン策定
- **フォロー理由:** コントローラー改造のレベル区分ガイドラインを策定し、大会運営者向けの基準を提供。SOCDモジュールの扱いについても見解を公開[^137][^147]
- **代表的な投稿:** 「カスタムコントローラーガイドライン」でレベル1〜3の改造区分と競技への影響を詳述[^137]

### 40. カプコン格闘ゲーム公式
- **@ID:** @CapcomFighters
- **カテゴリ:** CPTレギュレーション発信元
- **フォロー理由:** Capcom Pro Tourの公式アカウント。コントローラー規定の変更やSOCDに関する公式声明の一次ソース[^100]
- **代表的な投稿:** CPTにおけるコントローラー使用規定の更新告知[^100]

### 41. 4Gamer
- **@ID:** @4aboratory
- **カテゴリ:** 格ゲーニュース
- **フォロー理由:** カプコン綾野氏へのSOCDインタビューなど、コントローラー問題の深掘り取材を実施[^35]
- **代表的な投稿:** 「カプコンの綾野智章氏にCAPCOM Pro Tour 2019におけるコントローラー規定を聞く」インタビュー記事[^35]

---

## カテゴリ6：販売・頒布を行う個人工房

### 42. 碧井工房（再掲）
- **@ID:** @isomeaoi
- **カテゴリ:** レバーレス販売工房
- **フォロー理由:** store.jumphack.jpでスト6向けレバーレスを販売。プロトタイプから量産までの過程を公開[^11]
- **代表的な投稿:** JumpHack01のプロトタイプ紹介と販売開始告知[^126]

### 43. くろまき工房（再掲）
- **@ID:** @kuromakisuke
- **カテゴリ:** アケコンケース・パーツ販売
- **フォロー理由:** kuromaki.booth.pmで桜/夜桜シリーズのケース、自作用柱パーツなどを頒布[^39][^18]
- **代表的な投稿:** 順番待ちシステムでの販売と事前告知

### 44. One-Off Controller
- **@ID:** @oneoffcont
- **カテゴリ:** オーダーメイドアケコン
- **フォロー理由:** 2023年10月より開始したオーダーメイドケース販売。アクリル印刷等の新技術に積極的にチャレンジ[^22][^18]
- **代表的な投稿:** オーダーメイドアケコンの完成品写真とカスタム事例[^22]

### 45. ののずふぁくとり〜
- **@ID:** @Nonos_factory
- **カテゴリ:** アクリル成形・特殊形状コントローラ
- **フォロー理由:** アクリル形成を得意とし、特殊形状のコントローラを制作[^18]
- **代表的な投稿:** 毎回設計変更を加える開発姿勢で、過去製品を見るだけでも参考になる[^18]

### 46. CRAB CRAFT
- **@ID:** @KEYCAP（推定、CRAB CRAFTとして活動）
- **カテゴリ:** 猫アケコン販売
- **フォロー理由:** 猫モチーフのユニークなアケコン「WASABI」やレバーアケコン「TSUKUNE」を制作・販売[^125][^126]
- **代表的な投稿:** 「ゲーミングバザーで展示していたレバーレス猫アケコンは11月数量限定で販売予定」[^125]

### 47. てんきゅうラボ
- **@ID:** （BOOTHで活動）
- **カテゴリ:** レバーレスケース販売
- **フォロー理由:** 11ボタン対応透明ケース、右移動ボタン仕様キーボード型レバーレスなど多品種を販売[^126]
- **代表的な投稿:** BOOTHでの新製品投入が活発。ボタン配置カスタマイズ可能な設計[^126]

### 48. anose
- **@ID:** （BOOTHで活動）
- **カテゴリ:** 自作レバーレスキット販売
- **フォロー理由:** 自作レバーレスキットをBOOTHで頒布。キット形式で初心者の入門用にも[^126]
- **代表的な投稿:** 自作レバーレスキットの販売と組み立てガイド

### 49. RNO laboratory
- **@ID:** （BOOTHで活動）
- **カテゴリ:** ボタンカスタムパーツ販売
- **フォロー理由:** 三和ボタン用SSSS Kitやケーブル延長キットなど、ニッチなカスタムパーツを販売[^129]
- **代表的な投稿:** 三和ボタンカスタムパーツの設計改良と新バージョンリリース

### 50. RilemeFactory
- **@ID:** （BOOTHで活動）
- **カテゴリ:** 自作ボタン販売
- **フォロー理由:** マイクロスイッチ搭載ボタン「option」24φを設計・販売。独自のボタン設計に特化[^128]
- **代表的な投稿:** 自作ボタンのバージョンアップ過程

### 51. えふびろーむ
- **@ID:** （BOOTHで活動）
- **カテゴリ:** アダプタ・スペーサーパーツ販売
- **フォロー理由:** 30Φ→24Φ変更スペーサーやHaute42 T16用スペーサーなど、互換性パーツを設計・販売[^126]
- **代表的な投稿:** 既存製品のカスタマイズを可能にする変換パーツの設計[^126]

### 52. ケルさん工房
- **@ID:** （BOOTHで活動）
- **カテゴリ:** 簡易レバーレスキット販売
- **フォロー理由:** 3Dプリント製の簡易レバーレスキットを頒布[^126]
- **代表的な投稿:** 手軽に組み立てられるレバーレスキットの販売

### 53. 74th Books & Gadgets
- **@ID:** @74th
- **カテゴリ:** アケコンキット・RP2040基板販売
- **フォロー理由:** SparrowG21（GH60互換ケースで作るレバーレスアケコンキット、ジョイスティック付き）を販売[^126]
- **代表的な投稿:** キーボードケース互換のレバーレスキットという独自コンセプト[^126]

### 54. Akitoのおみせ
- **@ID:** （BOOTHで活動）
- **カテゴリ:** 木製レバーレス販売
- **フォロー理由:** 木製薄型レバーレスコントローラー「MOUNTAIN」を販売。素材選定の独自性[^126]
- **代表的な投稿:** 木製筐体ならではの質感と制作過程

---

## カテゴリ7：試作・開発プロセスを丁寧に記録する人

### 55. ぽめ（再掲・プロセス記録面）
- **@ID:** @pomegd
- **カテゴリ:** 開発プロセス記録
- **フォロー理由:** KiCadでの基板設計→Elecrowへのアクリル発注→組み立て→完成という全工程をブログとツイートで段階的に記録。失敗と修正の過程も含む[^6]
- **代表的な投稿:** 「薄型hitboxタイプのオリジナルコントローラーを作ってみたよ」で設計→基板→ガワ→完成の全工程を写真付きで公開[^6]

### 56. 碧井いそめ（再掲・プロセス記録面）
- **@ID:** @isomeaoi
- **カテゴリ:** 試作プロセス記録
- **フォロー理由:** 薄型機07の試作準備から、フレーム共通化の検討、パーツ調達の制約までリアルタイムで記録[^47][^86]
- **代表的な投稿:** 「できればフレームをレバーレスと共通にしたいのでまずはレバーレスで試作。レバーはフレームにかかる力の強さが…」という設計判断の記録[^86]

### 57. inajob（再掲・プロセス記録面）
- **@ID:** @ina_ani
- **カテゴリ:** RP2040基板の設計〜実装プロセス記録
- **フォロー理由:** 公式リファレンスの読解→回路設計→部品調達（AliExpress/LCSC）→実装→動作確認のフローを丁寧にブログ化[^43]
- **代表的な投稿:** 「ホットエアーガンでRP2040実装できた！」のツイートから始まる実装チャレンジの記録[^43]

### 58. SAYA ARCADE（再掲・プロセス記録面）
- **@ID:** @SAYA_ARCADE
- **カテゴリ:** 製品開発プロセス記録
- **フォロー理由:** SHINOGIの開発過程を「【開発報告】」タグで定期的に発信。カーボンプレート検討や配列決定のプロセスが見える[^82]
- **代表的な投稿:** 11ボタンレバーレス開発の各フェーズを段階的に告知[^82]

### 59. IORI | 伊織（再掲・プロセス記録面）
- **@ID:** @iori_sf
- **カテゴリ:** ハックログ形式のプロセス記録
- **フォロー理由:** note「IORI's Hack Logs」（月額500円、初月無料）で大っぴらに書きにくい技術的知見やハックを記録[^110]
- **代表的な投稿:** 磁石開閉化、基板設計の裏話など実務的なハック記録[^110]

### 60. 大西拓磨（再掲・プロセス記録面）
- **@ID:** @illlilllililill（推定）
- **カテゴリ:** 試行錯誤の率直な記録
- **フォロー理由:** 基板設計の外注→自力修正、Blenderでの筐体モデリング、ステップスカルプチャーの考案など試行錯誤をそのまま記録[^51]
- **代表的な投稿:** 「プロセスぐちゃぐちゃなので編年体でいきます！」と宣言する率直な開発記録[^51]

### 61. いのまきら
- **@ID:** @inomakira（note著者）
- **カテゴリ:** 自作レバーレス入門記録
- **フォロー理由:** 「薄型レバーレスコントローラーは誰でも自作できるという話」noteで、Raspberry Pi PicoからWaveshare RP2040-Zeroへのステップアップ過程を記録[^13]
- **代表的な投稿:** 初号機（Raspberry Pi Pico＋GP2040）から2号機（RP2040-Zero）への進化を段階的に解説[^13]

---

## 海外アカウント（補完）

### 62. PUNK WORKSHOP JAPAN
- **@ID:** @punkworkshop_jp
- **カテゴリ:** レバーレスメーカー（日本公式）
- **フォロー理由:** 独自ボタンと薄型レバーレスのラインナップ。新製品情報やPWS R14/MINI BOX/ULTRA BOXの展開[^149]
- **代表的な投稿:** 初のレバーコントローラー「PWS Lever」の開発告知[^150]

### 63. Haute42|COSMOX-JP
- **@ID:** @Haute42_Cosmox
- **カテゴリ:** レバーレスメーカー（日本公式）
- **フォロー理由:** T16/M16など多ボタンレバーレスの日本展開。価格帯が手頃で市場の参考になる[^133]
- **代表的な投稿:** X1専用レバーモジュール「Xスティック」の発表（1.7Kいいね）[^133]

### 64. Haute42 | COSMOX（グローバル）
- **@ID:** @Haute42_
- **カテゴリ:** レバーレスメーカー（グローバル）
- **フォロー理由:** Hautepad Xのモジュール調整機能など、最先端のレバーレス設計思想を発信[^136]
- **代表的な投稿:** EVO選出のHautepad Xのアップグレード「X-Move」の発表[^136]

### 65. FightBox Japan
- **@ID:** @FightBoxJP（推定）
- **カテゴリ:** レバーレスメーカー
- **フォロー理由:** 3つのSOCDモード対応（上優先デフォルト）。大会規格準拠の設計方針が参考になる[^30]
- **代表的な投稿:** スト6のレバーレスルールへの対応状況の発信[^30]

---

## 競合・市場把握のための参考アカウント

### 66. ZENAIM
- **@ID:** @ZENAIM_jp（推定）
- **カテゴリ:** 大手レバーレス開発
- **フォロー理由:** 国内プロゲーマー（ひかる、ももち）のこだわりをmm単位で反映したレバーレスを2026年発売予定で開発中[^92]
- **代表的な投稿:** TGS2025での試作機展示と試遊台の設置[^92]

### 67. e-elements
- **@ID:** @e_elements_jp（推定）
- **カテゴリ:** レバーレス・ゲーミングデバイス情報
- **フォロー理由:** ラピッドトリガー搭載レバーレスなど、SOCDクリーナーの柔軟な設定に関する最新動向を報道[^38]
- **代表的な投稿:** VARMILO FK2のSOCD設定の柔軟性についての解説記事[^38]

---

## リスト活用のポイント

| 活用目的 | 推奨カテゴリ |
|---|---|
| 基板設計を学びたい | カテゴリ4（@pomegd, @ina_ani, @74th, @iori_sf） |
| 3Dプリント筐体を設計したい | カテゴリ3（@TheTrain24, @aaa_tu, 画面端工房） |
| GP2040-CEのカスタマイズ | カテゴリ4（OpenStickCommunity, @TheTrain24） |
| SOCDルールの最新動向 | カテゴリ5（@evojapan_info, @CapcomFighters, @takahata88） |
| 販売・頒布の参考 | カテゴリ6（@isomeaoi, @kuromakisuke, @SAYA_ARCADE） |
| 開発プロセスの参考 | カテゴリ7（@pomegd, @isomeaoi, @iori_sf） |
| キーボード技術の応用 | カテゴリ2（@foostan, @Biacco42, @aki27kbd） |

---

## 補足事項

- BOOTHで活動する工房はXアカウントを持たないケースもあるため、BOOTH店舗ページのフォロー（お気に入り登録）も並行推奨
- GP2040-CEの最新情報はGitHub（OpenStickCommunity/GP2040-CE）とDiscordサーバーが最も速い[^113]
- Shiryl-shiのリンク集（shiryl-shi.hatenablog.com）は国内外のアケコン販売者を網羅しており、定期的にチェック推奨[^18]
- 自作キーボード界隈と自作アケコン界隈の技術的な重なり（KiCad、RP2040、キースイッチ、3Dプリント筐体）は大きく、キーボード設計者のフォローがレバーレス制作に直結する知見をもたらす[^45][^12]

---

## References

5. [これが誰でも作れる最強自作レバーレスコントローラー最適解です ...](https://x.com/dnm3rd/status/1737378038927761894) - 格ゲーマーささき (@dnm3rd). 521 likes. これが誰でも作れる最強自作レバーレスコントローラー最適解です https://t.co/jyyuC3bfEN 動画です。

6. [薄型hitboxタイプのオリジナルコントローラーを作ってみたよ](https://pomegd.hatenablog.com/entry/2021/01/10/174010) - なんとなくの大きさを想定して必要となるボタンを配置。最低限ON/OFFのボタンとUniversal Fighting Board（以下UFB）があればコントローラーは作れるので、 ...

7. [GP2040-CEを自分でカスタマイズしてビルドする話](https://blog.wsoft.ws/taiseiue/gp2040-ce-custom-build/) - かっこいいね。 問題のアケコン. GP2040-CEですが、どうやらRP2040系のマイコンでゲームコントローラーを作るためのOSSのファームウェアみたいです。

10. [Raspberry Pi Pico+GP2040で薄型レバーレスを自作（試作 ...](https://pomegd.hatenablog.com/entry/2022/02/23/150000) - 回路図もkicad用のデータもソースもファームウェアも無料で公開されているので、皆さんも自作アケコン作りに挑戦してみてはいかがでしょうか。楽しいよ。

11. [碧井いそめ (@isomeaoi) / Posts / X](https://x.com/isomeaoi) - 碧井いそめ (@isomeaoi) - Posts - 碧井工房代表。スト6向けレバーレス作ってます！→ store.jumphack.jp 格ゲーしたりレバーレス作るYouTubeもやってます .....

12. [moimate【公式】🎮 Rushbox Click (@moimate_inc) on X](https://x.com/moimate_inc/status/2018644500890202492) - 「キーボード設計のノウハウを活かせばもっと良いアケコンが作れるのでは！？」 ストリートファイター6が販売されてすぐのこと。

13. [薄型レバーレスコントローラーは誰でも自作できるという話｜いの](https://note.com/inomakira/n/n043fdf0c4d4a) - Raspberry Pi Pico(GP2040)というマイコンをご存知でしょうか？ファームウェアをインストールするだけで簡単にアケコン用の基板になってしまう優れものです ...

16. [東郷@アケコン販売中！ (@TogoHashibiroko) / Posts / X](https://x.com/TogoHashibiroko) - プラモ作ったりゲームやったりCG作ったりダーツしたり…多趣味なハシビロコウです。 無言フォロー失礼してます。気軽にフォローお願いします！

17. [レト/自作ボタン等アケコンパーツ販売](https://x.com/reto9696kazu) - ... アケコン沼にハマってパーツの自作を始めました。BOOTHにてアケコン用のベアリングアクチュエーターと磁気を利用したボタンを販売したりしてます。あと、... | X ...

18. [アーケードコントローラーのリンク集 - 脳内垂れ流し](https://shiryl-shi.hatenablog.com/entry/URLURLURL) - お客様の理想に合わせたアーケードコントローラーをオーダメイドで製作いたします。 レバー、レバーレス、特殊なボタン配置など様々な希望にあわせた ...

19. [現在自作アケコンを作ってるorパーツを出し ...](https://x.com/Nikogel360/status/1727278926613905826) - 現在自作アケコンを作ってるorパーツを出してる個人or業社をまとめた方が良い？ まとめろに投票する人はリプで販売サイトを1つ書いといて下さい

20. [ふく (@yfuku_) / Posts / X](https://x.com/yfuku_) - ふく (@yfuku_) - Posts - ソフトウェアや自作キーボードを作ってます。 キーボードアカ → @dailycraftkbd | X (formerly Twitter)

22. [One-Off Controller | オーダーメイドアケコン作成](https://x.com/oneoffcont/status/2019009164865835290) - ... 販売中『理想の1台』をお届けできるようご希望に合わせて製作 ... One-Off Controller | オーダーメイドアケコン作成's Image 1 on X · One ...

23. [わたしの自作キーボードはここから！｜蓮乃 紫 - note](https://note.com/akasha_min/n/n992431af2256) - ... 者です。（Twitter（現X）：https://x.com/piroridon）自作キーボードを始めてだいたい3年くらいになり、今では自分でキーボードを設計し、イベント ...

26. [2025年自作キーボード沼2年目の活動を振り返る｜kazy - note](https://note.com/kazy_developer/n/n930f20394532) - どうも、最近毎月自キーを買うのがデフォルトになってきてしまっているkazyです。Xでも自キー関連発信しているので良かったフォローしてくれると喜びます ...

29. [遊舎工房 | 自作キーボード＆レーザーカット](https://yushakobo.jp) - 秋葉原・末広町に実店舗を構えており自作キーボードキットの販売や工作室を運営しています。 また、主に個人の方を対象にしたレーザーカット、UVプリントサービスを ...

30. [FightBox Japan](https://fightboxarcade-jp.com) - ゲーム大会規格に準拠. 3つのモードをサポート. 上優先SOCDモード (デフォルト) ... 今カプコンからスト6のレバーレスルールも. fightBox. 運営に問い合わせしたら ...

31. [「ガフロコン事件」 がヒットボックス、レバーレスに与えた影響 ...](https://note.com/takahata88/n/nb30cf9fe9682) - ガフロコンを悪の代名詞として使うな！ 格闘ゲーム向けと言われ、理論値最強なんて言われてるヒットボックスとその派生であるレバーレスコントローラー。

32. [海外の大型格闘ゲーム大会にて特定のコントローラーが使用 ...](https://automaton-media.com/articles/newsjp/20190528-93027/) - 大型格闘ゲーム大会である「ComboBreaker 2019」にて、プロゲーマーの梅原大吾氏が持ち込み・使用を予定していたレバーレスコントローラーの一種、通称「 ...

34. [<令和7年最新版>EVO Japan 2025 presented by レバテックへ ...](https://shiryl-shi.hatenablog.com/entry/evoj25guide) - 今回は大会エントリー者だけで9000人という大規模な大会(そのうち7割以上がスト6)となったので、昨年と同様に初参加の方も多いと思います。

35. [カプコンの綾野智章氏に「CAPCOM Pro Tour 2019」における](https://www.4gamer.net/games/397/G039789/20190724010/) - 梅原大吾氏が使用するレバーレスコントローラが，通常のアーケードコントローラなどでは再現できない動きが可能ということで大きな物議を醸し，今回のルール ...

38. [【ラピッドトリガー搭載レバーレス】ふもっふのおみせとVARMILO ...](https://e-elements.jp/portal/news/26684/) - 特に、大会のルールで厳密に規定されているのが「同時押しの処理（SOCDクリーナー）」です。VARMILO FK2は、従来のレバーレスよりも柔軟な設定が可能で、「 ...

39. [makisuke (@kuromakisuke) / Posts / X](https://x.com/kuromakisuke) - makisuke (@kuromakisuke) - Posts - 趣味に生きる('Д')！色々作ってます 。 くろまき工房中の人。 お店 kuromaki.booth.pm 過去作ったもの twi...

42. [自作キーボードはじめました](https://tips.hecomi.com/entry/2019/02/26/005014) - 最近、人気の自作キーボード周りの情報を追っかけるのにハマっています。昨年末に以下のようなつぶやきをしたところ、たかしすきーさんが何と所望の ...

43. [自分で設計するRP2040基板 - inajob's blog - はてなブログ](https://inajob.hatenablog.jp/entry/rp2040-board) - RP2040は、Raspberry Pi PicoのメインのICです。 Raspberry Pi Picoは安価で入手性も良い開発ボードですが、形状が固定されており、製品に組み込むことを ...

45. [自作キーボード専門店・遊舎工房が広げた ... - WORKSIGHT](https://worksight.substack.com/p/173) - 自分で基板を設計したり、独自構造の〈変なキーボード〉をつくってみよう ... 自作キーボードながら、はんだ付け不要で組み立てができる超親切設計。

47. [07の試作の準備できたけどこれが4台分しかパーツがなくて](https://x.com/isomeaoi/status/2019207780708807010) - 碧井いそめ (@isomeaoi). 26 likes. やっと開発中の薄型機、07の試作の準備できたけどこれが4台分しかパーツがなくて、、、各所で試してもらいたいの ...

49. [RP2040を手はんだ実装に挑戦する開発ボードキット ...](https://booth.pm/ja/items/3929664) - Rasibperry Pi Pico の MCU、RP2040 を使った開発を体験できるキットです。 3枚分のPCBと、1個の制作に必要な部品が全て含まれています。

51. [おさかなキーボードの現状｜大西拓磨](https://note.com/illlilllililill/n/n1781dedd4372) - 昨日はミクモさんの『ほぼゼロから始める自作キーボード設計体験記』これすごいですね。なんでみんなそんな恙なく基板を書けるんでしょうか。自分も全く ...

52. [e3w2q (@e3w2q) / Posts / X](https://x.com/e3w2q) - 2022年の自作キーボードに関するアドベントカレンダーから、記事内で見つけたあれこれに、感想やコメントしたり、ネタにしたりした記事を書きました。 最後に、 ...

62. [GP2040-CE Homepage | GP2040-CE](https://gp2040-ce.info) - GP2040-CE (Community Edition) is a gamepad firmware for the Raspberry Pi Pico and other boards based...

64. [foostan (@foostan) / Posts / X](https://x.com/foostan) - foostan (@foostan) - Posts - Site Reliability Engineering, Keyboard Designing - Community: discord.g...

68. [Self-Made Keyboards in Japan Discord Server を開設した話](https://biacco42.hatenablog.com/entry/2017/11/17/093000) - 今回は究極のキーボードについてと、著者のクレカが停止させられた自作キーボードの作例も載っています。 1日目（金曜日）東た37a "plusTK2S"です！

69. [トラックボール付自作キーボード、cocot46plusを作った話を書き ...](https://x.com/aki27kbd/status/1530371770288865284) - aki27 ... キーボード、cocot46plusを作った話を書きました。設計に至った経緯とこだわりを紹介しています。 #cocot46 #cocot46plus #自作キーボード ...

71. [定番自作キーボード「Ergo42 Towel」を - 創作意欲とか物欲とか](https://www.creativity-ape.com/entry/2021/06/03/180000) - 近頃はDactyl Manuformばっかり触っていますが、僕が自作キーボード界隈に踏み入るきっかけになったのは、Ergo42 Towelというキーボードでした。

73. [グループバイの仕組み - 遊舎工房](https://shop.yushakobo.jp/pages/whatisgroupbuy) - 自作キーボードのベストセラー「Corne」の開発者であるFoostanさんが設計した、アルミ切削ケースキーボードです。著者が買っておけばよかったと深く後悔している ...

74. [キーボードを愛し、キーボードを自分で作り出す人々「天下一 ...](https://makezine.jp/blog/2019/01/tenkaichi_keybord_waiwaikai.html) - 遊舎工房の分割型自作キーボードキット「Helix」を片方だけ使い、これだけでキーボードとして使えるようにした「Froggy」。3色のカエルのキーとの同時 ...

77. [this is my new keyboard(not yet pcb). #自作キーボード](https://x.com/skyhigh_works/status/1056797495747993600) - 天高工房 (@skyhigh_works). 18 likes. this is my new keyboard(not yet pcb). #自作キーボード.

82. [SAYA ARCADE](https://x.com/SAYA_ARCADE/status/1701833483524718843) - 【開発報告】 11ボタンレバーレス開発もいよいよ終盤になります。 アクセサリーパーツとして検討しているカーボンプレートが届きました。

83. [SAYA ARCADE (@SAYA_ARCADE) / Posts / X](https://x.com/SAYA_ARCADE) - コントローラーを制作しております。 11ボタン薄型レバーレスコントローラー『SHINOGI』 We produce 11 buttons leverless controller products！ ...

86. [自作レバーアケコンの試作バージョン1。できればフレームを ...](https://x.com/isomeaoi/status/1842430668699238642) - 自作レバーアケコンの試作バージョン1。できればフレームをレバーレスと共通にしたいのでまずはレバーレスで試作。レバーはフレームにかかる力の強 ...

92. [国内プロ格闘ゲーマーのこだわりを反映した「ZENAIM」のレバー ...](https://www.4gamer.net/games/703/G070366/20250927029/) - とくに今回は，2026年の早い時期に発売することを目指して開発中のレバーレスコントローラ（以下，アケコン）を試遊台で試せるのが見どころだ。 レバーレス ...

96. [8個追加しました Precision Fighting Board | 伊織技研 https://t. ...](https://x.com/iori_sf/status/1709206977845612625) - Precision Fighting Board 8000Hz アケコン基板 - 伊織技研 - BOOTH. iori-giken.

100. [『ストリートファイターV』プロモーションプロデューサー綾野智章 ...](https://automaton-media.com/articles/interviewsjp/20190727-98359/) - つまりCOMBO BREAKERのルールには以前からSOCDの取扱いについての記述があり、その内容がある程度問題ないと確認した上で、大会ルールに従ってください ...

102. [EVO Japan | REGULAR TICKET -3/2🐤 (@evojapan_info) ...](https://x.com/evojapan_info) - 有志コミュニティが主催する交流会です。 スペース、機材などを #EVOJ26 実行委 がサポートします。

110. [アケコンの蓋を磁石開閉にする｜IORI](https://note.com/ioridev/n/nffb4e5a6d754) - 8000Hz動作のアケコンを作れる自作用基板を販売しております。 Precision Fighting Board | 伊織技研 https://t.co/5Gsz6h7lpJ #booth_pm #...

112. [r/fightsticks - GP2040-CE Xbox Compatibility Announced](https://www.reddit.com/r/fightsticks/comments/18i3mis/gp2040ce_xbox_compatibility_announced/) - GP2040-CE will have compatibility with Xbox One and Series! But, it will work in the same way as com...

113. [OpenStickCommunity/GP2040-CE: Multi-Platform Gamepad ...](https://github.com/OpenStickCommunity/GP2040-CE) - GP2040-CE (Community Edition) is a gamepad firmware for the Raspberry Pi Pico and other boards based...

115. [OpenStickCommunity/Hardware - GitHub](https://github.com/OpenStickCommunity/Hardware) - Open Stick Community hardware repo. This repository is a collection of open-source hardware designs ...

116. [Releases · OpenStickCommunity/GP2040-CE - GitHub](https://github.com/OpenStickCommunity/GP2040-CE/releases) - This is the GP2040-CE v0.7.8 firmware release. v0.7.8 see a major overhaul and refactor to our displ...

117. [The GP2040-CE team is happy to announce the release of v0.7.10 ...](https://x.com/TheTrain24/status/1841499077243965667) - The GP2040-CE team is happy to announce the release of v0.7.10. v0.7.10 is a large release that upda...

122. [jfedor2/flatbox: Low profile hitbox-layout fightstick - GitHub](https://github.com/jfedor2/flatbox) - This repository contains 3D-printable models, PCB design files and code needed to make an arcade con...

125. [ゲーミングバザーで展示していたレバーレス猫アケコンは11月数量 ...](https://x.com/craft_kani/status/1716388032423862328) - ゲーミングバザーで展示していたレバーレス猫アケコンは11月数量限定で販売予定です   #レバーレス · #アケコン · #hitbox · #スト6 · CRAB CRAFT @KEYCAP ...

126. [レバーレスに関する人気の同人グッズ173点を通販できる! - BOOTH](https://booth.pm/ja/items?tags%5B%5D=%E3%83%AC%E3%83%90%E3%83%BC%E3%83%AC%E3%82%B9)

127. [レバーレスアケコンのガワ Lサイズ - 画面端工房 - BOOTH](https://booth.pm/ja/items/7842349) - 自作レバーレスアケコン用のガワです。 別ページで出品しているガワのLサイズになります。 上面に2つ30mmの穴が空いている以外は全て24mmの穴です。

128. [マイクロスイッチ搭載ボタン「option」24φ v2.3 - RilemeFactory](https://booth.pm/ja/items/7401474) - 在庫なし

129. [【三和ボタンカスタムパーツ】 SSSS Kit v2 - RNO laboratory - BOOTH](https://booth.pm/ja/items/4766846) - 在庫あり

133. [Haute42|COSMOX-JP【公式】](https://x.com/Haute42_Cosmox) - レバーレスのアケコン、Haute42 C16( @Haute42_Cosmox )届いたー！！ なのでデスクは壁紙のJURIに濃い合わせてピンクのライトアップ スト6始めます (でも娘 ...

136. [Haute42 | COSMOX (@Haute42_) / Posts and Replies / X](https://x.com/Haute42_/with_replies) - X-Move incoming! The ultimate upgrade to our Evo-nominated Hautepad X: every single module can be pr...

137. [【最新版】カスタムコントローラーガイドライン](https://labogc.com/labogc-guideline/) - 今回はゲームを競技的にプレイするユーザー向けに“コントローラーの改造”及び“カスタムコントローラーの概要”について述べておきたいと考えております。

147. [【暫定版】GCコントローラー改造ガイドライン](https://pico-labogc.hatenablog.com/entry/2021/09/28/175507) - ・大会、対戦会における募集要項や対戦ルール等に記載する場合、全面的に転載及び引用を許可します。URLの記載の有無や管理人への連絡も任意とし、強制 ...

149. [PUNK WORKSHOP JAPAN (@punkworkshop_jp) / Posts / X](https://x.com/punkworkshop_jp) - PUNK WORKSHOP 日本公式アカウント。 新製品の情報をお届けします。 お問い合わせはこちら: punkworkshop.jp/pages/contact ※全てのお問い合わせにはお答え致しか...

150. [【新商品情報】PWS Lever(仮)🕹 PUNK WORKSHOPから初 ...](https://x.com/punkworkshop_jp/status/1781289559273468166) - PUNK WORKSHOPから初のレバーコントローラーが2024年の夏頃に発売予定です。 詳細については、下記の記事をご覧ください。 punkworkshop.jp/blogs/updates ...

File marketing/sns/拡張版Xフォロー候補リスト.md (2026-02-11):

# 拡張版：自作レバーレス制作者向け Xフォロー候補リスト（追加分）

前回リストでフォローできなかった分を補完するため、各カテゴリごとに追加候補をリストアップしました。@IDはツイートURL・プロフィールURL等から確認できたもののみ記載しています。

---

## カテゴリ1：自作レバーレス／自作アケコン制作者（追加）

### 1. たんしお
- **@ID:** @SuperTanshio
- **カテゴリ:** 自作レバーレス制作者／組立キット販売
- **フォロー理由:** レバーレス・レバー両方の組立キットを販売。天板にイラストやシールを挟んで自分だけのデザインにできるカスタマイズ性が特徴[^153]
- **代表的な投稿:** 組立キット販売の告知と、購入者によるカスタム事例のRT

### 2. シュール先輩
- **@ID:** @SurSenpai
- **カテゴリ:** 自作レバーレス制作者／YouTube解説
- **フォロー理由:** 基板設計からアクリル積層型の薄型レバーレスを自作する全工程をYouTubeで公開。PWS V2軸採用、コミックノイズのパーツ活用まで丁寧に解説[^165][^88]
- **代表的な投稿:** 「ダンボールで出来る！ガワから作る！自作レバーレスアケコンの作り方」動画（ボタン配列設計から最終組み立てまでステップ別解説）[^165]

### 3. 口レ（ロレン）
- **@ID:** @LorenStroganoff
- **カテゴリ:** 自作アケコン制作者
- **フォロー理由:** 普通のレバータイプから11ボタンOLED搭載レバーレスまで多様なアケコンを設計・制作。「厨二心満載のスペック」をコンセプトに掲げる[^162]
- **代表的な投稿:** 24mm/30mmボタンモデルの「普通のアケコン」やOLED搭載レバーレスの作品投稿[^162]

### 4. たば
- **@ID:** @hati_taba
- **カテゴリ:** 自作アケコン制作者
- **フォロー理由:** 独自設計のコントローラーを制作し、作例を定期的に投稿[^14]
- **代表的な投稿:** カスタムボタン配列のレバーレス制作過程[^14]

### 5. いよすけ
- **@ID:** @i_y_122
- **カテゴリ:** 自作レバーレス制作者／YouTube
- **フォロー理由:** 「アケコン製作未経験のド素人が0からレバーレスを作ってみた」動画で、アクリルカットからマグネット開閉加工まで全27分の制作ドキュメンタリーを公開[^154]
- **代表的な投稿:** アクリルオーダー→ホールソーでボタン穴あけ→Brook UFB配線→動作テストの完全工程記録[^154]

### 6. kinghalo
- **@ID:** （noteで活動）
- **カテゴリ:** 自作レバーレス制作者／解説
- **フォロー理由:** 「これを見れば作れます」と題した超薄型レバーレス制作解説noteが非常に充実。260mm×200mm、厚さ23mmのB5サイズ設計で、ボタン選定・コスト計算・図面データ配布まで網羅[^155]
- **代表的な投稿:** JumpHack・PUNK WORKSHOP・自作それぞれの比較検討から「20000円以下で高品質な箱を作る」目標設定まで詳細記録[^155]

### 7. fmyknote
- **@ID:** @fmyknote
- **カテゴリ:** 自作アケコン制作者
- **フォロー理由:** 設計の都合上ファストン端子が使えない制約下でのはんだ付け工程をライブ配信で公開。Brook USBボードを使った制作[^156]
- **代表的な投稿:** はんだ付け組み立て中継配信（設計コンセプトやパーツ選定理由を語りながら進行）[^156]

### 8. あかもず
- **@ID:** @akamozu（推定）
- **カテゴリ:** 自作レバーレス制作者
- **フォロー理由:** 100均「ハコット」を使ったアケコン制作記録をブログで公開。低コスト筐体の実験的アプローチ[^157]
- **代表的な投稿:** 道具箱「ハコット」で自作アケコンを作った製作記録（初心者向け参考情報）[^157]

### 9. ハニワ
- **@ID:** @haniwa_yukkuri
- **カテゴリ:** 自作レバーレス制作者／ゆっくり解説
- **フォロー理由:** 本職電気エンジニアが設計するQANBAボタン採用レバーレス。設計図データ配布あり、レーザーカッターの知識も持ちアクリルオンライン活用を解説[^192]
- **代表的な投稿:** ボタン配置設計→アクリル→配線→GP2040-CE設定まで18分のゆっくり解説動画[^192]

### 10. khide
- **@ID:** （noteで活動）
- **カテゴリ:** 自作レバーレス制作者
- **フォロー理由:** 「アケコン改造に限界を感じてレバーレスを自作した話」noteで、アルミフレーム＋アクリル板方式による低コスト制作を開拓。多くの後続制作者が参考にしている[^164]
- **代表的な投稿:** ケース制作方法の選択肢比較と実制作過程[^164]

---

## カテゴリ2：自作キーボード制作者（追加）

### 11. サリチル酸
- **@ID:** @Salicylic_acid3
- **カテゴリ:** 自作キーボード設計者／コミュニティ中心人物
- **フォロー理由:** 「自キ温泉ガイド」として自作キーボード設計ガイドVol1を執筆・大幅加筆。7sKB/7sPro/GoForty/Ergo68など多数設計。「知らない人はいないと言っても過言ではない」と評される存在[^176][^178]
- **代表的な投稿:** Acid Caps Premiumの設計やErgo68対応キーキャップセットの発表。設計ガイドの加筆告知[^175][^176]

### 12. ヨーキース（白銀ラボ）
- **@ID:** @Yowkees
- **カテゴリ:** 自作キーボード設計者／販売
- **フォロー理由:** トラックボール付き分割キーボード「Keyball」シリーズ（39/44/61）の設計者。飛騨市で白銀ラボを運営し、遊舎工房でも販売[^194]
- **代表的な投稿:** Keyball39 BLACK射出成形版の製作、新色・新スイッチの組み合わせ事例[^194]

### 13. takashicompany
- **@ID:** @takashicompany
- **カテゴリ:** 自作キーボード設計者
- **フォロー理由:** 0.8uキーキャップも自作する設計者。Baumkuchen等多数のキーボードを設計し、BOOTHと遊舎工房で頒布。トラックボール搭載モデルも設計[^168][^181]
- **代表的な投稿:** 「2023年の自作キーボード活動を振り返る」で設計思想と製品ラインナップを総括[^181]

### 14. Daihuku
- **@ID:** @Daihuku0015
- **カテゴリ:** 自作キーボードYouTuber／レビュアー
- **フォロー理由:** 年間21台以上のキーボードを組み立て・レビューし、YouTube動画で設計者の作品を紹介。「キー部」イベントのライブ配信も実施。設計者との橋渡し役[^168][^170]
- **代表的な投稿:** HidaritePad9の設計編動画、Keyball全シリーズレビュー動画[^170][^197]

### 15. t-miyajima
- **@ID:** （Webサイトで活動）
- **カテゴリ:** 自作キーボード設計者
- **フォロー理由:** Dvorak配列の40%キーボードを工房で設計・制作。制作座談会のライブ配信も実施[^166]
- **代表的な投稿:** 2025年3月に新しいキーボード制作ページを公開[^166]

### 16. ysk1025
- **@ID:** @ysk1025
- **カテゴリ:** 自作キーボード設計者
- **フォロー理由:** 天キーのテンキーで初めてキーボード設計に挑戦。「ネジもいらないほどシンプルに、できるだけ安価に」をコンセプトに設計[^174]
- **代表的な投稿:** 天キーテンキーの完成報告ツイート[^174]

### 17. 蓮乃 紫（再掲・インタビュアーとして）
- **@ID:** @piroridon
- **カテゴリ:** 自作キーボードクリエイターインタビュー
- **フォロー理由:** 「自作キーボード：クリエイターインタビュー」企画で設計者の魅力を発信。サリチル酸さん等へのインタビューで設計者間の知見共有を促進[^178]
- **代表的な投稿:** クリエイターインタビュー#10 サリチル酸さん編[^178]

---

## カテゴリ3：3Dプリント／造形・筐体設計の実務者（追加）

### 18. Tsukasa_3D
- **@ID:** @Tsukasa_3D
- **カテゴリ:** 3Dプリント大型造形
- **フォロー理由:** 家庭用3Dプリンターで小さなモジュールを組み合わせ、大型構造物（移動式工房「ラボトラ」）を制作。モジュラー設計の考え方がアケコン筐体にも応用可能[^201]
- **代表的な投稿:** MakerFaire Tokyo 2024出展作品「ラボトラ」の制作過程動画（200以上の3Dプリント部品）[^201]

### 19. HomeMadeGarbage
- **@ID:** @HomeMadeGarbage
- **カテゴリ:** 3Dプリント×電子工作
- **フォロー理由:** 3Dプリンタとマイコンを使ったロボットアーム・倒立振子等の制作過程をブログ化。Advent Calendar形式で年間の制作物を体系的に記録[^167]
- **代表的な投稿:** 「電子工作作品選集2025年」で年間の全制作物をまとめ、MuJoCo強化学習まで発展[^167]

### 20. Rookwork
- **@ID:** @Rookwork（GitHub中心）
- **カテゴリ:** レバーレス筐体設計（海外）
- **フォロー理由:** 「EXPress」レバーレスコントローラーを独自設計。ボタン配置の検討からホールパンチャーでの穴あけまで、設計思考のプロセスをブログで詳述[^214]
- **代表的な投稿:** 「Designing the EXPress」記事で、既存レバーレスへの不満→自作設計→3台制作までの全思考プロセスを公開[^214]

### 21. タコキン
- **@ID:** （geek.tacoskingdom.com運営）
- **カテゴリ:** 3Dプリント×DIY電子工作
- **フォロー理由:** Ender-3 PROの立ち上げからCura設定、穴や柱の出力品質向上まで、3Dプリント実務のノウハウをブログで体系的に記録[^169]
- **代表的な投稿:** サイクロン集じん装置のDIY、フィラメント乾燥器の改造評価など実用品制作記事[^169]

### 22. まあく
- **@ID:** @markscraft（推定、まあくの工作の部屋運営）
- **カテゴリ:** 3Dプリント×ロボット工作
- **フォロー理由:** R2-D2の3Dプリント外装制作や二足歩行ロボ開発など、3Dプリントパーツの切れ味・精度検証を実機で記録[^171]
- **代表的な投稿:** 3Dプリント（PLA）パーツの切れ味検証、ホームオートメーション制作[^171]

### 23. ちくまクリエイティブ
- **@ID:** （chikuma-creative.com運営）
- **カテゴリ:** 3Dプリント×ロボット
- **フォロー理由:** 「家庭用3Dプリンタと一般的な電子部品でヒューマノイドロボットを制作する」個人プロジェクト。筐体設計の精度と強度のバランスが参考になる[^213]
- **代表的な投稿:** ヒューマノイドロボット制作の各フェーズ記録[^213]

---

## カテゴリ4：基板設計・電子工作（追加）

### 24. コミックノイズ
- **@ID:** @comicnoise（BASE/YouTube: @pomm）
- **カテゴリ:** 自作レバーレスパーツ販売／基板＋配線セット
- **フォロー理由:** Raspberry Pi Pico基板と配線セット、USBケーブルセット、Kailhオリジナルスイッチ「SAIYA Silent」等をBASEで販売。組み立てのハードルを大幅に下げるキット化に注力[^185][^193]
- **代表的な投稿:** Kailh×コミノイオリジナル「SAIYA Silent」ロープロファイル軸の試用配信、PORONフォームによるボタン枠改造パーツ[^193][^180]

### 25. GP2040-CEカスタムビルド解説（WSOFT）
- **@ID:** @taiseiue（推定）
- **カテゴリ:** GP2040-CEファームウェアカスタム
- **フォロー理由:** WaveShare RP2040-ZeroでのGP2040-CEカスタムビルド手順を日本語で丁寧に解説。BoardConfig.hの編集方法まで記載[^7]
- **代表的な投稿:** GPIO設定の変更方法、ビルド環境構築から完成までの手順書[^7]

### 26. SGFDevices（再掲・詳細）
- **@ID:** @SGFDevices
- **カテゴリ:** GP2040-CE拡張デバイス
- **フォロー理由:** PS4/PS5/Xboxパススルー対応ドングル等、GP2040-CEと組み合わせるハードウェアを開発[^112]
- **代表的な投稿:** Xbox互換性のFAQと技術解説[^112]

### 27. OpenStickCommunity（GitHub/Discord）
- **@ID:** GitHub: OpenStickCommunity
- **カテゴリ:** オープンソースファームウェア＋ハードウェア
- **フォロー理由:** GP2040-CE本体に加え、Advanced Breakout Board、Flatbox Rev5、Open Stick Modular等のハードウェア設計もオープンソースで公開。KiCad基板データ、3Dプリントケースデータすべて入手可能[^113][^115]
- **代表的な投稿:** Hardware リポジトリで Flatbox Rev5（Kailh Choc/Cherry MX両対応）等のPCB設計公開[^115]

### 28. jfedor2（再掲・詳細）
- **@ID:** @jfedor2（GitHub中心）
- **カテゴリ:** Flatboxオリジナル設計
- **フォロー理由:** Flatbox全リビジョン（Rev1〜Rev9）を公開。RP2040直接実装型PCBで、基板がそのまま筐体になる最薄設計。3Dプリントボトムケースも提供[^122]
- **代表的な投稿:** GitHubでKiCadプロジェクト・ガーバーデータ・3Dプリントモデルをすべて公開[^122]

---

## カテゴリ5：格ゲー有識者／大会運営（追加）

### 29. 瀬戸風味
- **@ID:** @setofuumi
- **カテゴリ:** SOCD規制・コントローラーレギュレーション有識者
- **フォロー理由:** EVO Japan 2024のRules欄の解説、2019年のウメハラHitBox禁止事件からCPTルール改正までの経緯を時系列で整理。SOCD問題の最も包括的な日本語解説者の一人[^206]
- **代表的な投稿:** 「EvoJapan2024 Rulesのコントローラーの項目って何なの？」ブログで用語解説からメーカー別ルールの違いまで網羅[^206]

### 30. ライブラリ2045
- **@ID:** （Google Sites運営）
- **カテゴリ:** 大会規定・SOCD解説
- **フォロー理由:** SOCDの技術的定義からCPT・GGST・GBVSR等タイトル別のルール差異まで体系的にまとめたリファレンスサイト[^209]
- **代表的な投稿:** 「大会規定とSOCD」ページで上下同時押しニュートラル vs 上優先の違いとタイトル別運用を解説[^209]

### 31. Jeni / 畠山駿也
- **@ID:** @jenixo0
- **カテゴリ:** 格ゲーコントローラー公平性の議論者
- **フォロー理由:** コントローラーの公平性についてのパネルディスカッション参加者。「レバーレスを含むデバイスの多様性」と「競技の公平性」の両立を議論[^206]
- **代表的な投稿:** 大会でのコントローラー議論の重要性を発信[^206]

### 32. EVO Japan公式
- **@ID:** @evojapan_info
- **カテゴリ:** 大会運営
- **フォロー理由:** 日本最大級格闘ゲーム大会。コントローラーレギュレーション更新の一次ソース[^102]
- **代表的な投稿:** 大会ルール・エントリー情報[^102]

### 33. カプコンファイターズ
- **@ID:** @CapcomFighters
- **カテゴリ:** CPTレギュレーション元
- **フォロー理由:** CPTルール（移動4つ・アクション11以内、SOCD処理規定）の公式発信源[^209]
- **代表的な投稿:** CPTルール更新告知[^209]

### 34. TOPANGA
- **@ID:** @topaboratory（推定）
- **カテゴリ:** 格ゲー大会運営
- **フォロー理由:** トパンガリーグ等の大型大会を運営。プロ選手のデバイス環境を直接見られる機会[^192]
- **代表的な投稿:** 大会配信・選手のコントローラー情報

### 35. いおり（レジェンドケン）
- **@ID:** @iori_jr
- **カテゴリ:** 格ゲーYouTuber／デバイスレビュー
- **フォロー理由:** プロゲーマー使用デバイス紹介動画で、HitBox/PUNK WORKSHOP/Kitsune/Haute42等のレバーレスを比較解説[^187]
- **代表的な投稿:** 「プロが使用してるデバイス＋その他オススメデバイス紹介」動画[^187]

---

## カテゴリ6：販売・頒布を行う個人工房（追加）

### 36. コミックノイズ（Comic Noise）
- **@ID:** @comicnoise（BASE店舗）
- **カテゴリ:** レバーレス完成品＋DIYパーツ販売
- **フォロー理由:** 完成品レバーレス（SUNGA 17 Buttons/ComboBox）からDIY用パーツ（基板+配線セット・USBケーブルセット・Kailhスイッチ・PORONフォーム）まで幅広く販売。個人工房の販売モデルとして参考になる[^185][^188]
- **代表的な投稿:** オリジナルKailh×コミノイ SAIYAスイッチの開発販売[^193]

### 37. たんしお工房
- **@ID:** @SuperTanshio
- **カテゴリ:** レバーレス組立キット販売
- **フォロー理由:** 組立キット形式で販売し、天板カスタマイズ性を売りにする[^153]
- **代表的な投稿:** 期間限定販売の告知と組立事例[^153]

### 38. PUNK WORKSHOP JAPAN
- **@ID:** @punkworkshop_jp
- **カテゴリ:** レバーレスメーカー日本公式
- **フォロー理由:** MINI BOX/ULTRA BOX/R14に加え独自ボタン（PWS Blaze等）を展開。価格帯と品質のバランスが個人工房の市場分析に有用[^149][^150]
- **代表的な投稿:** PWS Lever（初のレバーコントローラー）の開発告知[^150]

### 39. Haute42 COSMOX-JP
- **@ID:** @Haute42_Cosmox
- **カテゴリ:** レバーレスメーカー日本公式
- **フォロー理由:** T16/M16/X1等の薄型レバーレスを低価格帯で展開。「Xスティック」モジュールなどモジュラー設計の参考[^133]
- **代表的な投稿:** X1専用レバーモジュール「Xスティック」発表（1.7Kいいね）[^133]

### 40. RNO laboratory
- **@ID:** （BOOTHで活動）
- **カテゴリ:** ボタンカスタムパーツ販売
- **フォロー理由:** 三和ボタンSSSS Kit v2で既存ボタンのショートストローク化を実現。多くの自作レバーレス制作者が採用[^129][^165]
- **代表的な投稿:** SSSS Kitの改良版リリースとユーザーフィードバック反映[^129]

### 41. RilemeFactory
- **@ID:** （BOOTHで活動）
- **カテゴリ:** 自作ボタン販売
- **フォロー理由:** マイクロスイッチ搭載ボタン「option」24φ v2.3を販売[^128]
- **代表的な投稿:** バージョンアップ履歴と設計改良[^128]

### 42. 画面端工房
- **@ID:** （BOOTHで活動）
- **カテゴリ:** 3Dプリント筐体販売
- **フォロー理由:** レバーレスアケコン用ガワ（Lサイズ/板厚3.5mm/三和ボタン対応）を3Dプリントで販売[^127]
- **代表的な投稿:** 試作段階の仕様変更過程を透明に公開[^127]

### 43. 遊舎工房
- **@ID:** @yushakobo_shop
- **カテゴリ:** 自作キーボード/デバイス部品販売
- **フォロー理由:** 秋葉原の実店舗でスイッチ・キーキャップ・基板・レーザーカットサービスを提供。レバーレス制作にも必要な部品の調達先[^29]
- **代表的な投稿:** 新入荷キット紹介、フリーマーケットイベントの開催[^29]

---

## カテゴリ7：試作・開発プロセスを丁寧に記録する人（追加）

### 44. kinghalo（再掲・プロセス記録面）
- **@ID:** （noteで活動）
- **カテゴリ:** 制作判断プロセスの詳細記録
- **フォロー理由:** 「自作のメリットは何か」「JumpHackより安く理想の箱を作れるか」という経済合理性の検討から設計に入る。ボタン選定（PWS/三和/マイクロスイッチ）の比較や「指が短くてボタンに届かない」問題まで率直に記録[^155]
- **代表的な投稿:** 仮想敵（既製品価格帯）の設定→コスト目標→設計→失敗→改善のPDCA全過程[^155]

### 45. シュール先輩（再掲・プロセス記録面）
- **@ID:** @SurSenpai
- **カテゴリ:** 動画による制作プロセス記録
- **フォロー理由:** ステップ①ボタン配列設計図→②穴開け→③GP2040-CEインストール→④配線→⑤仕上げの5段階を章立てで動画記録[^165]
- **代表的な投稿:** 各ステップのタイムスタンプ付き詳細解説[^165]

### 46. あめ
- **@ID:** （noteで活動: @rainygene推定）
- **カテゴリ:** 初制作の率直な記録
- **フォロー理由:** 「自分で何かものを作るのもnote記事を書くのも初めて」という初心者視点で、ボタン選定（Kailh Choc v2）からはんだ付けまでの全工程を記録。制作後にマスター到達までの使用感も追記[^195]
- **代表的な投稿:** 薄型レバーレス制作→スト6マスター到達の追記付きnote記事[^195]

### 47. いのまきら（再掲）
- **@ID:** @inomakira（note著者）
- **カテゴリ:** ステップアップ過程の記録
- **フォロー理由:** Raspberry Pi Pico→WaveShare RP2040-Zeroへの基板ステップアップ、1号機から2号機への改善過程を段階的に記録[^13]
- **代表的な投稿:** 「薄型レバーレスコントローラーは誰でも自作できるという話」[^13]

### 48. Rookwork（再掲・プロセス記録面）
- **@ID:** @Rookwork
- **カテゴリ:** 設計思考プロセスの記録（海外）
- **フォロー理由:** 「既存のレバーレスが全部気に入らない」からスタートし、ボタン配置の人間工学的検討→素材選定→穴あけ工具の試行錯誤（ドリル→レーザー→ホールパンチャー）まで設計判断の「なぜ」を丁寧に記録[^214]
- **代表的な投稿:** 「Designing the EXPress」でHole puncherに辿り着くまでの失敗遍歴を含む全プロセス公開[^214]

### 49. ebisen
- **@ID:** （noteで活動）
- **カテゴリ:** アケコンデビューの記録
- **フォロー理由:** コミックノイズのパーツを使ったレバーレス自作でアケコンデビューした記録[^183]
- **代表的な投稿:** パーツ選定から完成までの初心者視点の制作記[^183]

### 50. あるてむ
- **@ID:** （noteで活動）
- **カテゴリ:** 自作アケコン制作記録
- **フォロー理由:** 「少し安くレバーレスを入手」する目的で自作を選択し、制作過程を記録[^158]
- **代表的な投稿:** 自作アケコン制作記をnoteで公開[^158]

---

## 海外アカウント補完

### 51. TheTrain
- **@ID:** @TheTrain24
- **カテゴリ:** GP2040-CE中心開発者／ハードウェア設計（海外）
- **フォロー理由:** Open Stick CommunityのリードメンテナでGP2040-CEのリリース管理。Advanced Breakout Board・Open Stick Modular等の3Dプリント対応ケース多数設計[^117][^115]
- **代表的な投稿:** GP2040-CE各バージョンのリリースノート投稿[^117]

### 52. Flatbox（jfedor2）
- **@ID:** GitHub: jfedor2
- **カテゴリ:** オープンソースPCB設計（海外）
- **フォロー理由:** Flatbox Rev1〜Rev9で「PCBがそのまま筐体になる」最薄レバーレスを実現。基板設計の極限を学べる[^122]
- **代表的な投稿:** GitHubでの全設計データ公開[^122]

### 53. Haute42グローバル
- **@ID:** @Haute42_
- **カテゴリ:** レバーレスメーカー（グローバル）
- **フォロー理由:** Hautepad X/X-Moveのモジュラー設計。EVO選出のデバイスメーカーとして市場のトレンドを把握[^136]
- **代表的な投稿:** 新モジュール発表・技術仕様公開[^136]

---

## 活用のポイント

| 目的 | 今回の追加で特に有用なアカウント |
|---|---|
| 低コスト制作のノウハウ | @SurSenpai, kinghalo(note), khide(note), @haniwa_yukkuri |
| パーツ販売の参考 | @comicnoise(BASE), @SuperTanshio, RNO lab, RilemeFactory |
| 設計ガイド・教材 | @Salicylic_acid3（設計ガイド本）, @Daihuku0015（動画レビュー） |
| SOCD・大会ルール最新情報 | @setofuumi, ライブラリ2045, @iori_jr |
| 3Dプリント筐体設計 | @Tsukasa_3D, @HomeMadeGarbage, Rookwork |
| 初心者目線の失敗記録 | あめ(note), ebisen(note), あるてむ(note) |

---

## 補足

- noteやブログで活動する制作者の多くはXアカウントを持っていますが、ハンドルネームが異なる場合があります。note記事内のリンクからX(@)を辿るのが確実です
- コミックノイズ（@comicnoise / YouTube: @pomm）はBASEでの販売モデルが秀逸で、個人工房としてのEC運営の参考になります[^185]
- 前回リストの@IDが変更・鍵アカウントだったものは、note/BOOTH/GitHubなど別プラットフォームでの活動を確認し、最新の@IDを追跡してください

---

## References

7. [GP2040-CEを自分でカスタマイズしてビルドする話](https://blog.wsoft.ws/taiseiue/gp2040-ce-custom-build/) - かっこいいね。 問題のアケコン. GP2040-CEですが、どうやらRP2040系のマイコンでゲームコントローラーを作るためのOSSのファームウェアみたいです。

13. [薄型レバーレスコントローラーは誰でも自作できるという話｜いの](https://note.com/inomakira/n/n043fdf0c4d4a) - Raspberry Pi Pico(GP2040)というマイコンをご存知でしょうか？ファームウェアをインストールするだけで簡単にアケコン用の基板になってしまう優れものです ...

14. [たば (@hati_taba) / Posts / X](https://x.com/hati_taba) - くろまき工房さん( @kuromakisuke)に夜桜  を購入させて頂けることになり、合わせたステッカーとレバーボールを自作して完成🕹️ 中身とか変わっても一生このアケコンを ...

29. [遊舎工房 | 自作キーボード＆レーザーカット](https://yushakobo.jp) - 秋葉原・末広町に実店舗を構えており自作キーボードキットの販売や工作室を運営しています。 また、主に個人の方を対象にしたレーザーカット、UVプリントサービスを ...

88. [基板から薄型レバーレス自作した経験。 これやってみて - Twitter](https://x.com/SurSenpai/status/1972491275141292377) - 【スト6】基板から自分で設計した薄型レバーレスを自作する！！Punk WorkshopのV2軸を採用！※概要欄に作り方あり【アクリル積層型】. チャンネル登録 ...

102. [EVO Japan | REGULAR TICKET -3/2🐤 (@evojapan_info) ...](https://x.com/evojapan_info) - 有志コミュニティが主催する交流会です。 スペース、機材などを #EVOJ26 実行委 がサポートします。

112. [r/fightsticks - GP2040-CE Xbox Compatibility Announced](https://www.reddit.com/r/fightsticks/comments/18i3mis/gp2040ce_xbox_compatibility_announced/) - GP2040-CE will have compatibility with Xbox One and Series! But, it will work in the same way as com...

113. [OpenStickCommunity/GP2040-CE: Multi-Platform Gamepad ...](https://github.com/OpenStickCommunity/GP2040-CE) - GP2040-CE (Community Edition) is a gamepad firmware for the Raspberry Pi Pico and other boards based...

115. [OpenStickCommunity/Hardware - GitHub](https://github.com/OpenStickCommunity/Hardware) - Open Stick Community hardware repo. This repository is a collection of open-source hardware designs ...

117. [The GP2040-CE team is happy to announce the release of v0.7.10 ...](https://x.com/TheTrain24/status/1841499077243965667) - The GP2040-CE team is happy to announce the release of v0.7.10. v0.7.10 is a large release that upda...

122. [jfedor2/flatbox: Low profile hitbox-layout fightstick - GitHub](https://github.com/jfedor2/flatbox) - This repository contains 3D-printable models, PCB design files and code needed to make an arcade con...

127. [レバーレスアケコンのガワ Lサイズ - 画面端工房 - BOOTH](https://booth.pm/ja/items/7842349) - 自作レバーレスアケコン用のガワです。 別ページで出品しているガワのLサイズになります。 上面に2つ30mmの穴が空いている以外は全て24mmの穴です。

128. [マイクロスイッチ搭載ボタン「option」24φ v2.3 - RilemeFactory](https://booth.pm/ja/items/7401474) - 在庫なし

129. [【三和ボタンカスタムパーツ】 SSSS Kit v2 - RNO laboratory - BOOTH](https://booth.pm/ja/items/4766846) - 在庫あり

133. [Haute42|COSMOX-JP【公式】](https://x.com/Haute42_Cosmox) - レバーレスのアケコン、Haute42 C16( @Haute42_Cosmox )届いたー！！ なのでデスクは壁紙のJURIに濃い合わせてピンクのライトアップ スト6始めます (でも娘 ...

136. [Haute42 | COSMOX (@Haute42_) / Posts and Replies / X](https://x.com/Haute42_/with_replies) - X-Move incoming! The ultimate upgrade to our Evo-nominated Hautepad X: every single module can be pr...

149. [PUNK WORKSHOP JAPAN (@punkworkshop_jp) / Posts / X](https://x.com/punkworkshop_jp) - PUNK WORKSHOP 日本公式アカウント。 新製品の情報をお届けします。 お問い合わせはこちら: punkworkshop.jp/pages/contact ※全てのお問い合わせにはお答え致しか...

150. [【新商品情報】PWS Lever(仮)🕹 PUNK WORKSHOPから初 ...](https://x.com/punkworkshop_jp/status/1781289559273468166) - PUNK WORKSHOPから初のレバーコントローラーが2024年の夏頃に発売予定です。 詳細については、下記の記事をご覧ください。 punkworkshop.jp/blogs/updates ...

153. [たんしお (@SuperTanshio) / Posts / X](https://x.com/SuperTanshio) - 2025年9月7日～14日(日)20:00まで！ ... 組立キットをメインにレバーレス、レバーどちらも販売しています！ ... ・ご自身で天板にイラストやシールを挟んで自分だけのデザインに！

154. [アケコン製作未経験のド素人が0からレバーレスを作ってみた。](https://www.youtube.com/watch?v=fyHqBQWi85c) - ▶マキタ(Makita) DIYモデル 充電式震動ドライバドリル M850DSX バッテリ2個付
https://amzn.to/3QF0oUb

▶Brook Universal Fighting ...

155. [【これを見れば作れます】超薄型レバーレスアケコンの制作方法解説](https://note.com/kinghalo_dl/n/nba75df864ed0) - どうもこんにちは、kinghaloです。 レバーレスアケコンを自作したのでこれから自作しようとしている人のために制作方法をまとめておこうと思います。参考にしていただければ。 ついでにレバーレスを自作す...

156. [#自作アケコン レバーレスコントローラーはんだ付け組み立て中継 #オリジナルアケコン](https://www.youtube.com/watch?v=50rB69-JR0A) - blog:https://fmyknote.com/
twitter:https://twitter.com/fmyknote
学生のとき以来の電子工作。設計の都合上ファストン(平型)端子が使えないの...

157. [道具箱「ハコット」で自作アケコンを作ってみた(製作記録) - akamozu_LOVの日記](https://akamozu-lov.hatenablog.com/entry/2025/02/22/181046) - 自作アケコン作りました。その製作記録。これから作る人の参考になれば幸いです。

158. [自作アケコンを作ってみた｜あるてむ](https://note.com/artem4183/n/n3191aa67aa68) - いろいろ調べていくと、アケコン自作を行っている例がいくつかありました。少し安くレバーレスを入手できそうだと考え、実際に制作してみました。 拙い ...

162. [口レ (@LorenStroganoff) / Posts / X](https://x.com/lorenstroganoff) - 「普通のアケコン」レバータイプ24mm /30mmボタンモデル！ ... 11ボタンにOLED搭載！厨二心満載のスペック！ たくさんのご応募お待ちしております

164. [アケコン改造に限界を感じてレバーレスを自作した話② 作成編](https://note.com/khide/n/n170e12e76c15) - さて、いよいよレバーレスの制作に入っていくわけだが、自作コントローラーはとにもかくにもガワ、ケースを作らないと始まらない。 で、さっそくダイソー ...

165. [【解説】ダンボールで出来る！？ガワから作る！自作レバーレスアケコンの作り方【コミックノイズ】【三和ボタン】【PWS Blaze】](https://www.youtube.com/watch?v=TsyR8BpLKuw) - チャンネル登録、高評価よろしければ是非！
Twitchも遊びに来てください！

【今日の動画について】
アケコンのガワはどう調達すれば良いか。
この問題を解決すべく私はRazerのキーボードのダンボー...

166. [自作キーボード - t-miyajima ウェブサイト](https://t-miyajima.jp)

167. [[電子工作] ロボット / リアクションホイール 自作](https://homemadegarbage.com/category/electronics) - 3Dプリンタやマイコンを使ってロボットアームやリアクションホール、バーサライタ等、様々な電子工作品の製作過程をブログにしております。

168. [2022年に組み立てた自作キーボードと携わったイベントについて｜Daihuku](https://note.com/daihukukeyboard/n/n1b28aade50ab) - 1. はじめに この記事は、”2022年のキーボード #2 Advent Calendar 2022” 12月10日の記事です。12月9日はJunさんの”忘年会2022”でした。 この記事では、202...

169. [タコツボの中の工作室〜電子工作系ブログ | 3Dプリンターの部](https://geek.tacoskingdom.com/3dprinter) - (同)タコキンの運営するDIY電子工作系ブログです。ラズパイやArduinoなどの自作した小物を中心に、電子工作の「ツボ」を勉強したり紹介したりするサイトです。

170. [自作キーボード作ってみた HidaritePad9（#1 設計編） in 遊舎工房](https://www.youtube.com/watch?v=0_TLw7c9teU) - 自作キーボードのお店 遊舎工房にて2019年6月に開催されたイベント「meishi展」で私は自身が設計したキーボード「HidaritePad9」を出展しました。そのキーボードは初めて設計したこともあり...

171. [まあくの工作の部屋](https://markscraft.blogspot.com)

174. [天キーのテンキーで初めて自作キーボードの設計をしてみて](https://x.com/ysk1025/status/2019176837323321355) - 天キーのテンキーが完成しました。 ネジもいらないほどシンプルに、できるだけ安価になるようにまとめてみました。 テンキー部分が余りがちなキーキャップ ...

175. [そうなんです、実はAcid Caps Premiumは私の設計したキーボード ...](https://x.com/Salicylic_acid3/status/2019188410691551729) - そうなんです、実はAcid Caps Premiumは私の設計したキーボードに対応するようにセットを設計していて、その中にはErgo68も含まれていたのでした。

176. [自作キーボード設計ガイド Vol1を大幅加筆したよ！](https://salicylic-acid3.hatenablog.com/entry/guide1-update) - こんにちは。自キ温泉ガイドのサリチル酸です。 自作キーボード設計ガイドを大幅加筆したので、その内容について解説したいと思います。

178. [自作キーボード：クリエイターインタビュー #10 「サリチル酸さん」](https://note.com/akasha_min/n/n98e186064a6f) - はじめに 自作キーボード界隈で活動されている「人」にフォーカスし、作品ではなく製作者の魅力をお届けするインタビュー企画 「自作キーボード：クリエイターインタビュー」。第10回目は、自作キーボード界隈で...

180. [【#レバーレス・#アケコン】配信 コミックノイズオリジナル Kailh×コミノイ SAIYA Silentロープロファイルを試す](https://www.youtube.com/watch?v=9DHEr8gndAI) - ※2月4日配信の動画版になります

製品ページはこちら
https://comicnoise.base.shop/items/96857327

ほぼ毎日、18時30分ごろから配信中！
※レバーレス・...

181. [2023年の自作キーボード活動を振り返る](https://zenn.dev/takashicompany/articles/b2e5a7c8f2d1e4)

183. [レバーレスを自作してアケコンデビューしてみた｜ebisen - note](https://note.com/ebisen_ttt/n/nf825b704c7b6) - コミックノイズ | Comic Noiseで購入する · 自作レバーレス用のUSBケーブルセット | コミックノイズ | Comic Noise powered by BASE 自作レバーレス用の ....

185. [コミックノイズ | Comic Noise](https://comicnoise.base.shop) - ボタンキャップ · キースイッチ · 押ボタン · DIY用パーツ · レバーレスコントローラー · 部品・改造・工具 · その他. MEMBERSHIP. コミノイ-MemberShip- · マイ...

187. [【アケコン/PAD/レバーレス】プロが使用してるデバイス＋その他オススメデバイス紹介！！　#スト6  #ストリートファイター6 #レバーレス](https://www.youtube.com/watch?v=U_ws67YZDRA) - レジェンドケンのいおりと申します。

ーーーーーーーーーーーーーーーーーーーーーーーーーーーーーーー
★レバーレス
ヒットボックス
┗https://amzn.to/4dJNzSp

punk wor...

188. [レバーレスコントローラー - コミックノイズ | Comic Noise](https://comicnoise.base.shop/categories/6122023) - 【終了】SUNGA 17 Buttonsレバーレスコントローラー. ¥16,700. SOLD OUT. SUNGA 17 Buttonsレバーレスコントローラー☆PS4/PS5パススルーUSB端子の...

192. [【超簡単!?】超気持ちい爆速レバーレスアケコンの作り方【設計図配布あり】【ゆっくり解説】](https://www.youtube.com/watch?v=7x71YljCRbg) - ストリートファイター６用に、QANBAボタンを使用した、
レバーレスのアーケードコントローラーを自作してみました┌|∵|┘

動画内には映っていませんが、実際にはラズパイはUVボンドで固定し、
延長用...

193. [コミックノイズの商品一覧](https://note.com/comicnoise/store) - 『コミックノイズ』公式アカウントです😺幸せを分かち合い、喜びも倍にしよう💖面白いモノをシェアしたい💥

194. [ヨーキース🎱 (@Yowkees) / Posts / X](https://x.com/Yowkees) - 飛騨市の自作キーボード通販サイト【白銀ラボ】代表。トラックボール付き分割キーボードキット【Keyballシリーズ】と空飛ぶクルマ【Beedol】 @Beedol_Shirogan を作っ ...

195. [薄型レバーレスアケコン作ってみた｜あめ](https://note.com/rainygene/n/n5b05aca0de4f) - 事の発端はやはりスト6だった この記事を見に来てくださっている人にはおそらくレバーレスがなんだとか、スト6がなんだとかの説明は必要ないかと思います。 自分がスト6以前に遊んでいた格ゲーは 鉄拳7 ギル...

197. [【大注目】トラックボール付き自作キーボード Keyball 全シリーズ紹介 | Keyball : Custom Mechanical Trackball Keyboard Review](https://www.youtube.com/watch?v=1cAUIVWyOXU&feature=emb_imp_woyt) - Keyballは以下の特徴をもった自作キーボードです。
- Keyball61/Keyball44/Keyball39 三つラインナップ
- 滑らかで着脱が容易なオリジナルのトラックボールケース
- ...

201. [移動式工房「ラボトラ」を作る！](https://www.youtube.com/watch?v=h5ScycPsByA) - 3Dプリンターで「移動式工房」を作る挑戦！
こんにちは、Tsukasaです！この動画では、3Dプリンターを活用して制作した、どこへでも移動できる「ラボトラ」のコンセプトと制作過程を詳しく紹介します。
...

206. [EvoJapan2024：Rulesのコントローラーの項目って何なの？+格ゲー大会のコントローラーを巡る話2024年版 - setofuumiのblog](https://setofuumi.hatenablog.com/entry/2024/02/05/002055) - EvoJAPAN2024のRules欄にあるコントローラーの項目で「どういうこと？」ってなりそうなので解説を書いた https://t.co/C6Mh986hYgEvoJPのRules:コントローラー...

209. [ライブラリ2045 - 大会規定とSOCD](https://sites.google.com/view/library2045/fgc/socd) - SOCDとは SOCD（Simultaneous Operation of Cardinal

213. [ロボットをつくってみる](https://chikuma-creative.com/) - 家庭用3Dプリンタと一般的な電子部品でヒューマノイドロボットを制作してみる個人的なプロジェクト

214. [Designing the EXPress, an all-button arcade controller – Rookwork](https://rookwork.com/leverless-controller-design) - I've always liked the concept of fighting games, but I struggle with the controls, so I decided to d...

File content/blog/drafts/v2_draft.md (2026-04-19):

# 自作レバーレス製作記 Vol.2：角度を足したら前進したけど、親指と作り方で詰まった話

こんにちは。
普通のレバーレスを長く触っていると、置き方や手首まわりがなんとなくしっくりこないことがあります。
前回の v1 では、左右の傾きだけを入れた結果、手が滑るし、手首も反るしで、思ったより楽になりませんでした。

そこで v2 では、**テンティング（左右の面を内側に傾けること）** とハの字の開き方をまとめて入れて、もっと自然に手を置けるかを試しました。
今回は細かい実装の話ではなく、**角度を入れたら使い心地がどう変わったか** に絞って書きます。
自作経験がなくても、「エルゴノミクス寄りのレバーレスって実際どうなんだろう」と気になっている人に読んでもらえたらうれしいです。

※この記事も完成報告ではなく、試作の**メモ／ログ** です。数値や結論は、現時点の体感と観察にもとづく**暫定** として書きます。

## 先に3つだけ

- v1 より、角度の方向性はかなり良くなった
- ただし、見た目どおりに作るのはかなり大変だった
- 特に親指ボタンは、他の指と同じ考え方では置きにくかった

## まず見てほしい形の違い

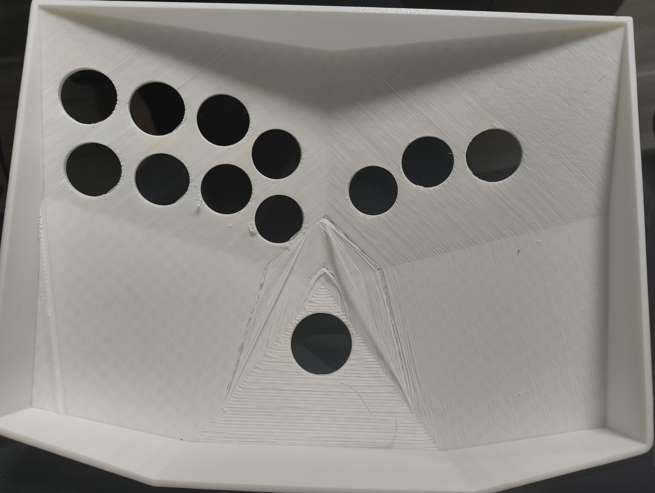
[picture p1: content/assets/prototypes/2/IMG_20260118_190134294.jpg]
v2 上面（設計）

*設計時点の上面。ハの字に広がるボタン配置と、中央のジャンプボタンエリア。*

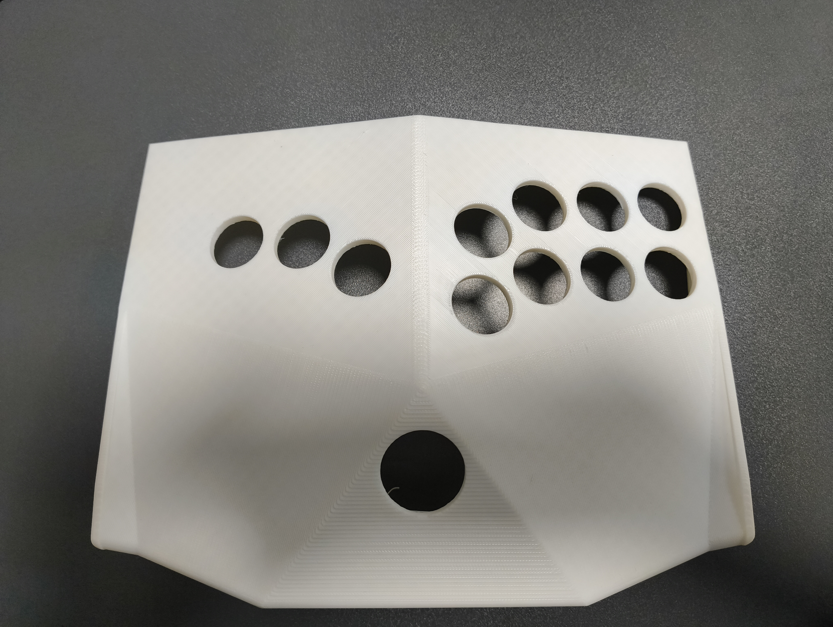
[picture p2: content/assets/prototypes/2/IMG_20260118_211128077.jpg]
v2 上面（実機）

*実際に出力した v2。左右のボタン面を開きつつ、中央に向かって立体感をつけている。*

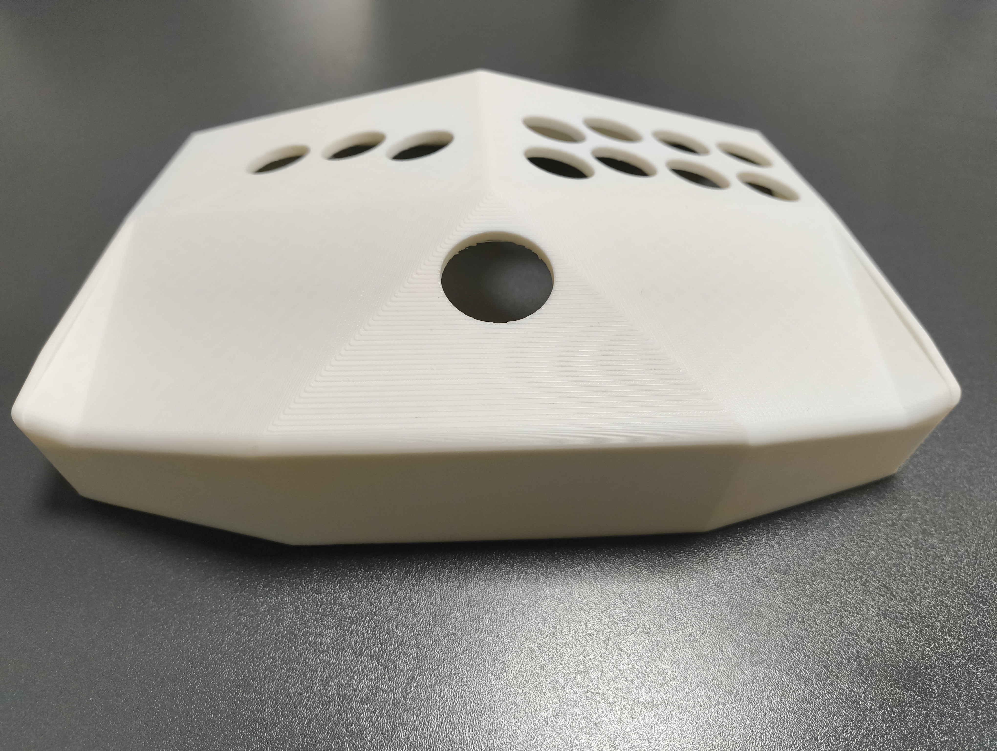
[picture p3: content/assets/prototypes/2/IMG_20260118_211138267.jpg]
v2 斜め前から

*斜め前から見ると、中央に向かって盛り上がる形がわかりやすい。*

今回やりたかったのは、単に変わった見た目にすることではなく、**手の開き方とボタン面の角度を合わせること** でした。
見た目の違いより、「置いたときに自然かどうか」を優先した試作です。

## 今回いちばん前進したこと

いちばん良かったのは、**角度の方向性そのものには手応えがあったこと** です。

v1 では、左右の傾きはあっても、全体としてまだ「無理やり置いている」感じが残っていました。
でも v2 では、手を置いた瞬間の違和感が少し減って、少なくとも「この方向は違う」とは感じませんでした。

まだ完成形ではないのですが、**テンティング＋ハの字** という方向性は続ける価値がありそうです。
エルゴノミクス寄りのレバーレスを見るときも、角度がついていること自体より、**その角度で手首と指が自然に置けるか** を見る方が大事だと感じました。

## 逆に、まだ微妙だったところ

### 1. 作りやすさが追いつかなかった

この形は、使い心地の方向性としては悪くなかったのですが、**3Dプリントではかなり作りにくい形** でした。
一体成形にしたせいで、裏面に無理が出やすく、印刷時間も長くなりました。

つまり、**楽な形と作りやすい形は別** でした。
試作を何度も回したい段階では、見た目のきれいさより、もう少し作りやすい構成を優先した方が良さそうです。

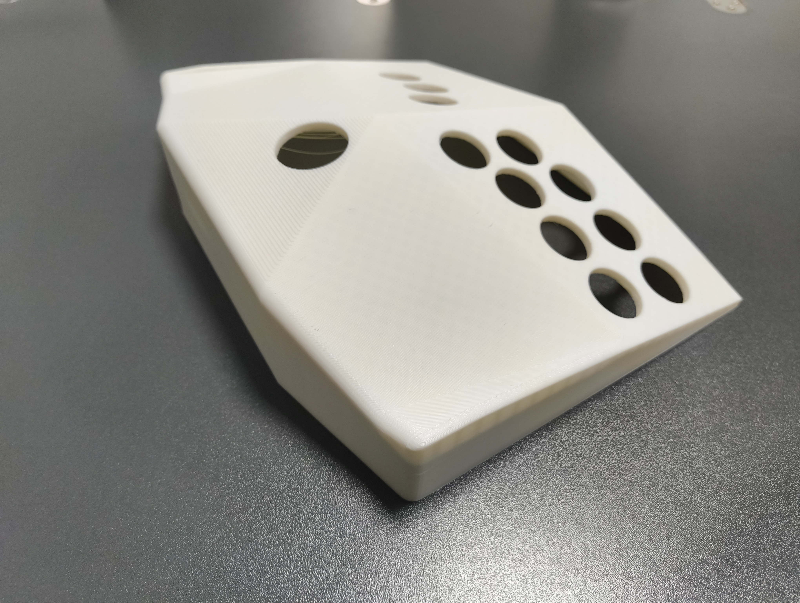
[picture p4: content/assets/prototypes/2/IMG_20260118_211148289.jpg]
v2 側面（テンティングの断面）

*側面から見ると、角度のぶんだけ造形も難しくなる。*

### 2. 親指だけ、別ルールで考えた方がよさそう

もうひとつ大きかったのが、**親指のジャンプボタン** です。

v2 では、ジャンプボタンも他のボタンとほぼ同じ面に置いたのですが、実際に手を置くと、親指は他の指よりも少し低い位置や手前に動きたがる感じがありました。
そのため、同じ高さにそろえると、親指の付け根に少し無理が出ます。

さらに、ボタン全体も少し手前すぎました。
**パームレスト（手首や手のひらを支える部分）** に手を置いたとき、指が自然に届く位置とボタン位置が少しズレていて、全体として窮屈でした。

ここは、自作する人だけでなく、エルゴノミクス寄りのレバーレスに興味がある人が製品を見るときにも気にすると良さそうです。
親指ボタンがどこにあって、どんな角度から押す前提なのかで、印象はかなり変わる気がします。

## 次に試したいこと

- 親指ボタンを一段下げた配置を試す
- ボタン全体を少し奥にずらす
- 一体成形にこだわりすぎず、もっと試作しやすい構成も考える

今回は「かなり良くなった」と「まだ詰まる」が両方見えた試作でした。
完成には遠いですが、少なくとも次に見るべきポイントはかなりはっきりした気がします。

同じように、普通のレバーレスの置き方や親指の押し方に違和感がある人はいるのか、ちょっと気になっています。
自作している人でも、まだしていない人でも、「ここが気になる」という点があれば教えてもらえるとうれしいです。

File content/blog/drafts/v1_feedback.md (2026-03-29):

# 自作レバーレス製作記 Vol.1：理想の角度を求めて失敗した話

こんにちは。
趣味で格闘ゲーム用のレバーレスコントローラーを自作しようと試行錯誤しています。

普段、仕事で**分割キーボード** をハの字に開いて使っているのですが、この発想を自作レバーレスにも持ち込めないか？と思い、試作を始めました。

※この記事は完成報告じゃなくて、試作の**メモ／ログ** です。数値や結論も、あくまで現時点の体感と観察にもとづく**暫定** として書きます。

## 先に結論（この記事でわかること）

- **テンティング（左右の傾き）** をつけたら、手が滑って踏ん張ることになった
- **前後方向の傾き（チルト）** がないと、手首が反ってキツかった
- **v2では3方向の角度＋パームレスト** が必要そう、という暫定ルールが見えた

<!-- 画像メモ: 画像は後で差し替え予定。パスは仮で `content/blog/images/v1/` を想定 -->

v1試作機の全体写真（トップ）
*ここで今回の主役（v1）を最初に見せる用。*

今回は、最初の仮説を立てて、勢いで作った**最初の試作機（v1）** で想定どおりにいかなかった点を記録します。

## なぜ作ろうと思ったのか

前段のとおり、仕事で分割キーボードを使うようになってから、**肩こりが明らかに減った** という体験がありました。
左右を少し離してハの字に置くだけで、窮屈だった肩や胸が開いて、長時間作業しても疲れにくくなる。
「道具の形が変わるだけで、こんなに楽になるのか」と驚いたのが原体験です。

分割キーボードの使用イメージ（机上）
*ハの字に開く、を一枚で伝える用。*

この「分割キーボードの恩恵」を体感してしまうと、ゲーム用のレバーレスコントローラーも気になってきます。
レバーレスもボタンをパタパタ叩く操作で、感覚としてはキーボードにかなり近いです。

「**だったら、レバーレスもハの字にしたらもっと楽に遊べるんじゃないか？** 」

分割キーボードで感じたこの「楽な姿勢」の工夫を、コントローラーにも輸入してみたい。
単純だけど、それがすべてのきっかけでした。

机の上に手をだらんと置いてみると、手のひらは自然と内側を向き、腕はハの字になります。
でも、既存のコントローラーを使うときは、手のひらを真下に向けることが多いです（回内）。
回内＝腕をひねって手のひらを下に向ける動き。
脇も締まりやすくて、姿勢としてはちょっと窮屈になりがち。

エルゴノミクス（人間工学）の考え方も手がかりにしつつ、まずは自分なりに調べながら試してみることにしました。
正直、エルゴノミクスについて詳しく知っているわけではないので、わかったつもりで作り切るよりも、仮説を置いて小さく検証し、違和感が出たら前提から見直す、という進め方でやっています。

## 仮説：分割キーボードの発想はレバーレスにも効く？

ここでの仮説はシンプルです。

> **左右をハの字に開き、さらに少し傾ける（テンティング）と、手首と前腕が楽になるのでは？**

※ここでいうテンティングは、左右の面を内側に少し傾けて、手のひらが向かい合う方向に寄せるイメージです。

テンティングとハの字のイメージ図
*用語の補助図（ざっくりでOK）。*

一回、形にしてみないとわからないなと思い、次に3Dプリンタで試作へ進みました。

## レバーレス特有の壁：ジャンプボタン問題

ここで一つ、キーボードとは違うレバーレス特有の悩みがありました。
それは「**ジャンプボタン（上入力）** 」の存在です。

一般的なレバーレス（Hitbox配列など）では、最下段の大きなボタンをジャンプに割り当て、左右どちらの親指でも押せるように構えるのがセオリーです。
しかし、分割キーボードのように左右を物理的に切り離してしまうと、この「真ん中の共有ボタン」の置き場がなくなってしまいます。

今回のv1では、この問題を「**手前の平面部分** 」を作ることで解決してみました。
左右は角度をつけて分割しつつ、手前だけは水平な共有エリアを残し、そこにジャンプボタンを配置する設計です。

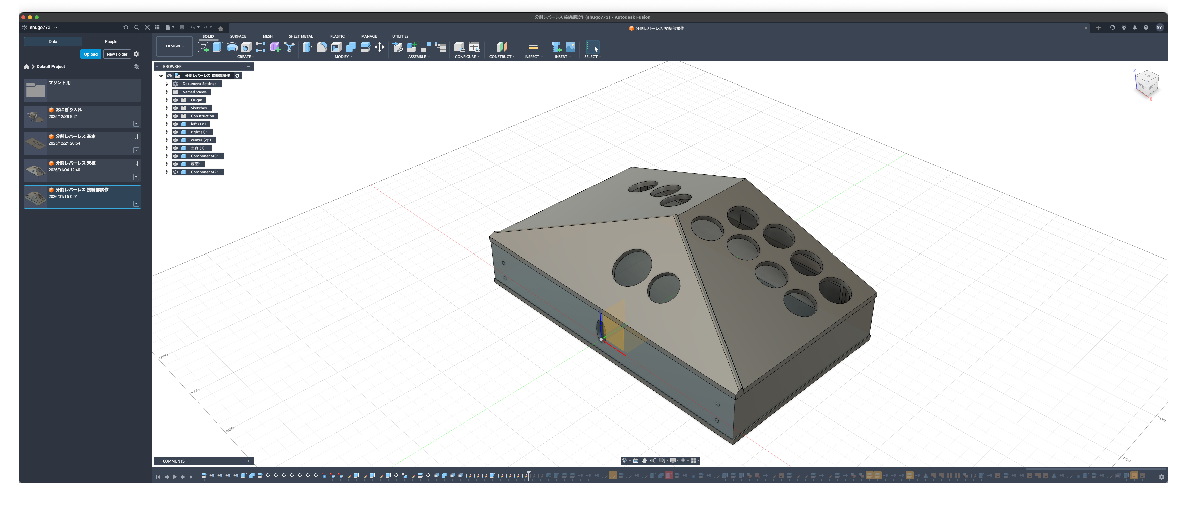
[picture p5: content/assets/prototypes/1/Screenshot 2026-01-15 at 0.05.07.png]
v1のジャンプボタン配置（CAD）

*左右分割＋手前共有エリアのアプローチ*

これなら従来の操作感を保ちつつ、エルゴノミクス的な角度も両立できそうに思えました。
ただし、この「中途半端な分割」がどう影響するかは、実際に使ってみないとわからない部分でもあります。

## v1で試したこと：テンティングとハの字を導入

検証したかったのは、**傾斜（テンティング）** と**開き角（ハの字）** を組み合わせた効果です。
左右のボタン配置面を山型に傾斜させ、さらに少しハの字に開くことで、腕のねじれが取れて楽になるはず……と考えました。

そう考えて、v1では**左右のユニットに傾斜（テンティング）とハの字（開き角）をつけた状態** を再現してみました。3Dプリンタで出力し、キースイッチをはめて、いざ手を置いてみました。

v1の構成（上面）
*ボタン配置とハの字の角度が分かる写真。*

v1の構成（側面）
*テンティングの傾斜が一目で分かるように。*

## やってみてわかった2つの誤算

頭の中では完璧な理論でしたが、実際に手を置いてみると、想像とは違う感覚が返ってきました。

### 1. 手が滑り落ちていく

傾斜がついているので、当然ですが重力で手が外側へ滑り落ちようとします。
それを防ぐために、無意識に親指の付け根や手首で踏ん張ってしまい、逆に腕に力が入ってしまいました。

楽にするための傾斜なのに、その場に留まるために筋力を使う。
これでは本末転倒です。傾斜をつけるなら、重力を受け止める支え（パームレスト）が自分にはかなり必要だと痛感しました。

手が滑り落ちる様子（手を置いた写真）
*何が起きたか、を一枚で伝える用。*

### 2. 手首が逆に痛い

これが一番の発見でした。
v1ではテンティングとハの字をつけましたが、**奥に向かって下がる傾斜（前後の傾き）** がついていませんでした。

膝の上にコントローラーを置いて使う場合、腕は上から降りてくる形になります。
それに対してボタン面が（前後方向に）水平だと、指の腹をボタンに正対させるために、**手首をグッと手前側に反らす（背屈する）** 必要がありました。

テンティングで左右の角度は合っていても、前後の角度が腕の進入角度と喧嘩していたため、常に手首を痛みが出る方向に曲げ続けることになってしまったのです。
「3次元の角度合わせ」の難しさを痛感した瞬間でした。

背屈が出てしまう例
*手首を無理に反らせている様子を伝える用。*

## 次の試作（v2）に向けて

今回の失敗から、ひとつの重要な**暫定ルール** が見えてきました。

> **テンティング・ハの字に加えて、「奥に向かって下がる傾斜」も必須。**

「楽な角度」を作るには、左右（テンティング）・水平（ハの字）・前後（奥への傾き）のすべてで無理がないか確認する必要がありそうです。

現在、この教訓を活かして**v2プロトタイプ** の設計を進めています。
次は以下のような形状を試してみるつもりです。

1.  **3方向の角度調整** : テンティング・ハの字に加え、奥側へ下がる傾斜をつける。
2.  **パームレストの一体化** : 角度がついたことで手が滑り落ちないよう、しっかり支える。

v2の方向性（ラフ図またはCADスクショ）
*次はこうする、を1枚で。パームレスト／ハの字／奥側角度が同時に見えると強い。*

自分が一番使いやすいコントローラーを目指して、少しずつ改良を重ねていこうと思います。
また進捗があれば、ここで報告します。

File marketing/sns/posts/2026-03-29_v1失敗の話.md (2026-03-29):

# 投稿下書き：v1失敗の話（note誘導）

プラットフォーム: Twitter/X → note誘導
テーマ: v1の失敗をnoteで公開（公開後に使用）
作成日: 2026-03-29

---

## 案A（シンプルnote告知）

自作レバーレスの製作ログをnoteに書きました。

1号機で「テンティング（傾き）をつけたら手が滑って、逆に腕に力が入った」という失敗の話。

「楽にするための傾きなのに、踏ん張るために筋力を使う」という本末転倒な結果でしたが、これがなければv2以降の設計方針は出てこなかった。

[URL]

---

## 案B（失敗の核心を先出し）

v1の一番の学び：テンティングだけじゃダメだった。

・左右の傾き（テンティング）→ OK
・手前から奥への傾き（チルト）→ 入れてなかった

手を置いた瞬間に手首が反って、痛みが出た。3次元の角度合わせは思ったより難しい。

詳しくnoteに書きました → [URL]

#自作キーボード #レバーレス

---

## 案C（問いかけ→note誘導）

自作レバーレスを作るとき、一番最初につまずいたのは「角度」でした。

傾きをつければ楽になるはず、という仮説がそのまま通らなかった話、noteに書いてます。

同じように悩んでる人の参考になれば。

→ [URL]

---

## 使用推奨案

**案B**（失敗の核心を具体的に見せている。note公開後すぐに使う）

※note公開後、URLを入れて投稿

ハッシュタグ候補: #自作キーボード #レバーレス #格ゲー #3Dプリンター

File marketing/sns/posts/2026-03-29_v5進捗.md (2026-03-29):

# 投稿下書き：v5進捗報告

プラットフォーム: Twitter/X
テーマ: v5試作の現状報告
作成日: 2026-03-29

---

## 案A（シンプル進捗型）

自作レバーレス、v5を設計中。

今回はチルト角 -15°（指先に向かって下がる傾き）はv4から据え置きで、ボタン配置の微調整に集中してる。

角度の検証はある程度固まってきた。次のフェーズは「どこにボタンがあると一番ミスしないか」を手で確かめること。

理論より手が正直。

---

## 案B（問いかけ型）

自作レバーレスのv5設計中。

テンティング20°・ハの字20°・チルト -15° という角度の組み合わせに今のところ落ち着いてる。

ただ「なんとなく楽」と「実際にゲームで使える」は別物で、連続入力してみるとまだ誤入力が出る。

レバーレス使ってる方、ボタン配置で意識してることありますか？

---

## 案C（失敗→改善型）

v4で「指が奥まで届かない」という問題が出た。

チルト角（奥下がりの傾き）が強くなるほど指先が遠くなる。エルゴノミクス的に正しい角度と、実際に操作しやすい配置は必ずしも一致しない。

v5ではボタン全体を手前に引いた。まず試作して手に聞く。

#自作キーボード #レバーレス

---

## 使用推奨案

**案C**（失敗→改善の構成がプロジェクトの哲学に合っている）

ハッシュタグ候補: #自作キーボード #レバーレス #格ゲー #自作コントローラー

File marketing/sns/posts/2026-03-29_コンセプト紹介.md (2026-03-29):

# 投稿下書き：コンセプト・原点紹介

プラットフォーム: Twitter/X
テーマ: なぜ作っているか（原点）
作成日: 2026-03-29

---

## 案A（体験ベース）

仕事で分割キーボードを使うようになってから、肩こりが明らかに減った。

左右を少しハの字に開くだけで、肩が開いて長時間作業しても疲れにくい。

「だったらレバーレスもそうすれば楽なのでは？」という単純な発想から、自作レバーレスを作り始めた。今v5まで来た。

---

## 案B（問題提起型）

既存のレバーレスコントローラーはほぼ全部フラット。

フラットな面に手を置くと手のひらが下を向く（回内）。腕がひねれて、長時間だと手首や腕に疲労が来やすい。

机に腕をだらんと置くと、手のひらは自然と内側を向く。この「楽な状態」のままゲームできないか、を試作で探している。

---

## 案C（シンプル宣言）

手首が痛くなる前にゲームを続けるために、自分用のレバーレスを作っている。

エルゴノミクスを勉強しながら試作を繰り返して、今5号機。完成はまだ先だけど、少しずつ手が楽になってきた実感がある。

作る過程も記録として残していきます。

---

## 使用推奨案

**案A**（分割キーボードとの接続が具体的で共感を得やすい）

ハッシュタグ候補: #自作キーボード #レバーレス #エルゴノミクス #格ゲー

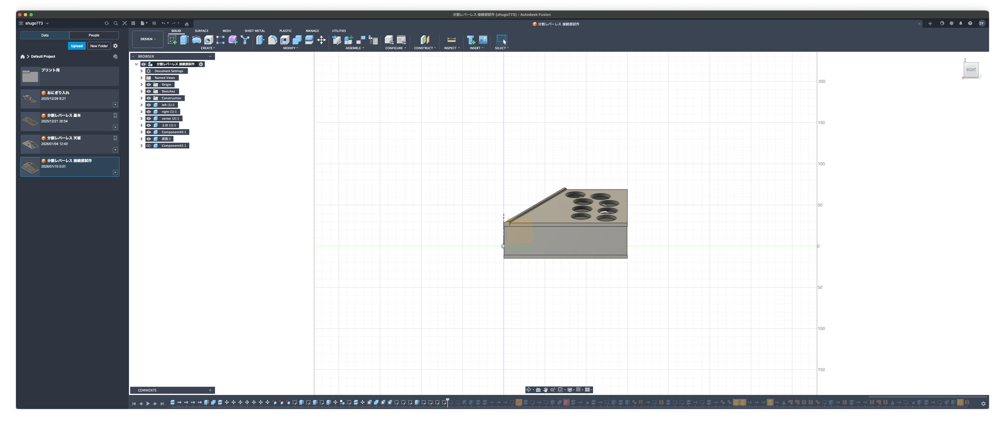
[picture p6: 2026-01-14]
content/assets/prototypes/1/Screenshot 2026-01-15 at 0.05.45.png

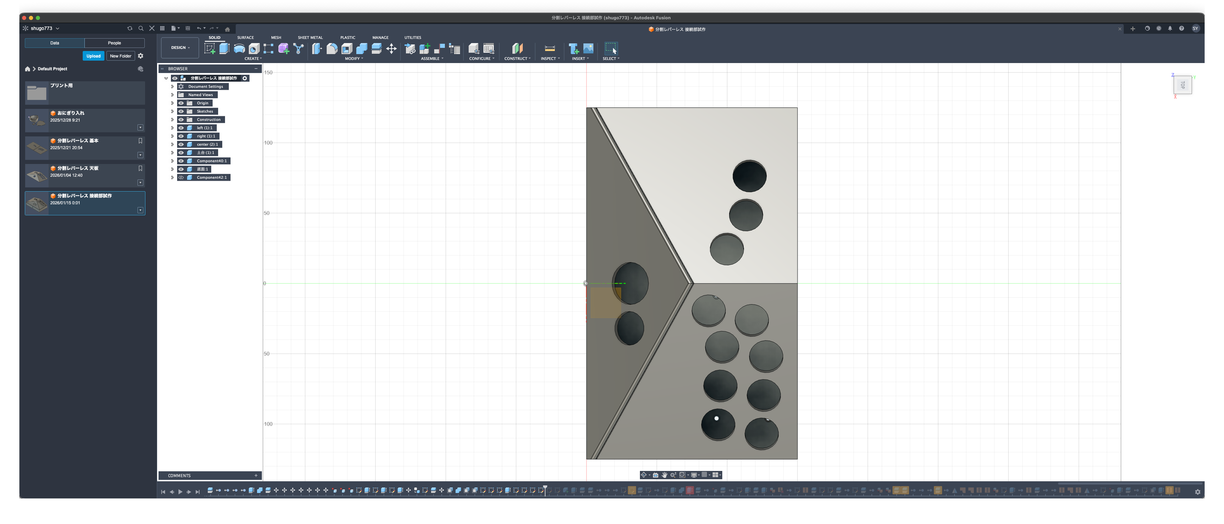
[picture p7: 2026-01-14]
content/assets/prototypes/1/Screenshot 2026-01-15 at 0.05.19.png

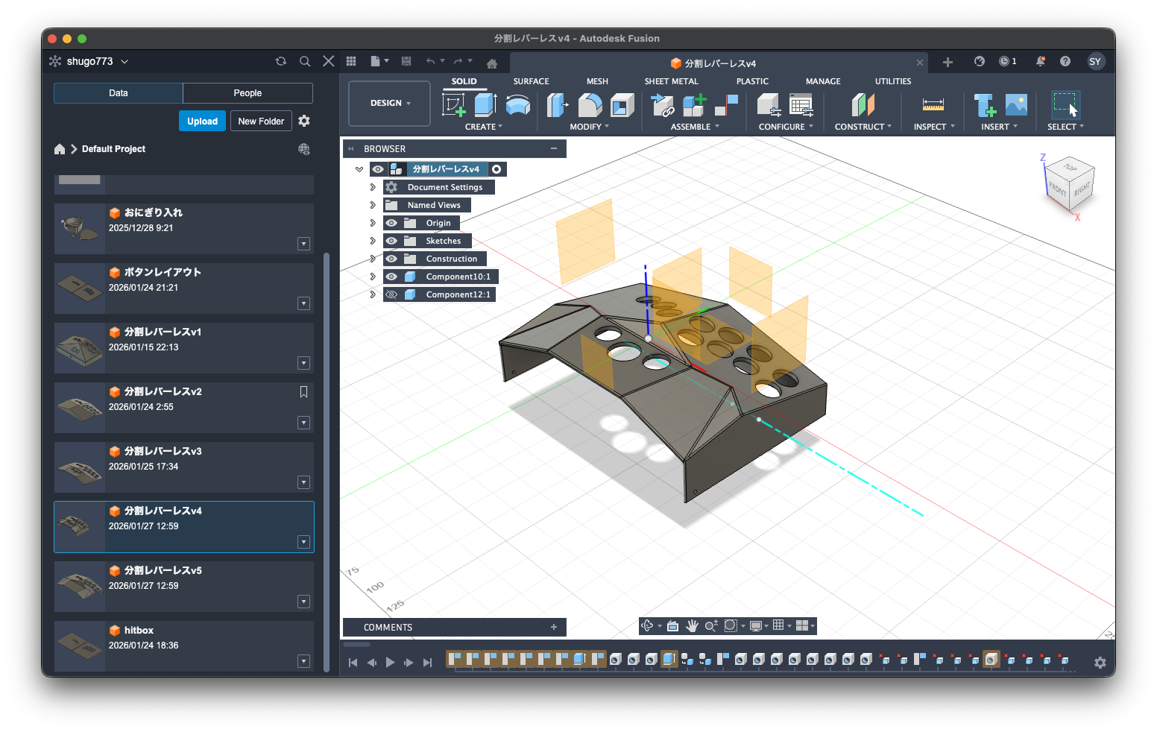
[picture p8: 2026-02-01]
content/assets/prototypes/4/Screenshot 2026-01-27 at 16.35.13.png

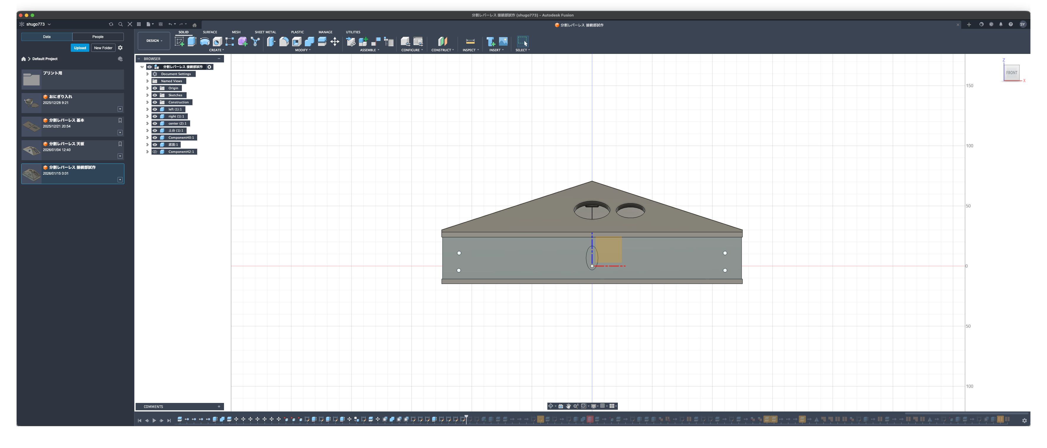
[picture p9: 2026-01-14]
content/assets/prototypes/1/Screenshot 2026-01-15 at 0.05.33.png

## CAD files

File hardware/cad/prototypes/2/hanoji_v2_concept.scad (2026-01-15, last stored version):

// Project Hanoji: Prototype v2 Concept Model
// Description: V-shape ergonomic leverless controller concept

// --- Parameters ---

// View Mode: Select "3D" or "BLUEPRINT" (2D Drawing)
view_mode = "BLUEPRINT";

// 1. Angles
tenting_angle = 15;      // Z-axis rotation (Tenting) [degree]
opening_angle = 30;      // Opening angle for V-shape (Total) [degree]
half_opening_angle = opening_angle / 2;

// 2. Dimensions
split_distance = 50;     // Distance between left and right units at center [mm]
plate_thickness = 5;     // Top plate thickness [mm]
case_height_min = 20;    // Minimum height of the case (front) [mm]

// 3. Button Config
btn_size_action = 24;    // Action button diameter [mm]
btn_size_thumb = 30;     // Thumb/Jump button diameter [mm]
btn_rim = 2;             // Rim size for hole cutout

// --- Modules ---

module button_hole(d) {
    color("DimGray")
    cylinder(h=plate_thickness + 2, d=d, center=true);
}

module button_cap(d) {
    color("Crimson")
    translate([0, 0, plate_thickness/2 + 1])
    cylinder(h=5, d=d-2, center=false);
}

// Left Hand Layout Module
module left_hand_layout() {
    // Left Hand: Movement (Left, Down, Right)
    translate([-40, 50, 0]) { button_hole(btn_size_action); button_cap(btn_size_action); } // Left
    translate([-10, 40, 0]) { button_hole(btn_size_action); button_cap(btn_size_action); } // Down
    translate([ 20, 50, 0]) { button_hole(btn_size_action); button_cap(btn_size_action); } // Right

    // Thumb: Up (Left side up)
    translate([ 30, -10, 0]) { button_hole(btn_size_thumb); button_cap(btn_size_thumb); }
}

// Right Hand Layout Module
module right_hand_layout() {
    // Right Hand: 8 Action Buttons (Vewlix/Noir style)

    // Row 1 (Bottom: Kicks)
    translate([-40, 40, 0]) { button_hole(btn_size_action); button_cap(btn_size_action); } // K1
    translate([-10, 40, 0]) { button_hole(btn_size_action); button_cap(btn_size_action); } // K2
    translate([ 20, 40, 0]) { button_hole(btn_size_action); button_cap(btn_size_action); } // K3
    translate([ 50, 40, 0]) { button_hole(btn_size_action); button_cap(btn_size_action); } // K4

    // Row 2 (Top: Punches)
    translate([-40, 70, 0]) { button_hole(btn_size_action); button_cap(btn_size_action); } // P1
    translate([-10, 75, 0]) { button_hole(btn_size_action); button_cap(btn_size_action); } // P2
    translate([ 20, 75, 0]) { button_hole(btn_size_action); button_cap(btn_size_action); } // P3
    translate([ 50, 70, 0]) { button_hole(btn_size_action); button_cap(btn_size_action); } // P4

    // Thumb: Up (Right side up - optional or Jump)
    translate([-30, -10, 0]) { button_hole(btn_size_thumb); button_cap(btn_size_thumb); }
}


module unit_base_shape() {
    color("LightGrey")
    hull() {
        translate([-60, -30, -case_height_min]) cube([130, 140, 2]); // Bottom plate area
        translate([-60, -30, 0]) cube([130, 140, plate_thickness]);   // Top plate area
    }

    // Palm Rest Area (Simplified)
    color("Silver")
    translate([-60, -100, -case_height_min])
    cube([130, 70, case_height_min + plate_thickness]);
}


module full_assembly() {

    // LEFT UNIT
    translate([-(split_distance/2), 0, 0])
    rotate([0, 0, half_opening_angle]) // Open V-shape
    translate([-60, 0, 0]) // Shift pivot point
    rotate([0, tenting_angle, 0])
    translate([60, 0, 0]) // Shift back
    {
        difference() {
            unit_base_shape();
            translate([0,0,-1]) left_hand_layout();
        }
        left_hand_layout();
    }

    // RIGHT UNIT
    translate([(split_distance/2), 0, 0])
    rotate([0, 0, -half_opening_angle]) // Open V-shape
    translate([60, 0, 0]) // Shift pivot
    rotate([0, -tenting_angle, 0]) // Tenting: Right side goes UP
    translate([-60, 0, 0]) // Shift back
    {
        difference() {
            unit_base_shape();
            translate([0,0,-1]) right_hand_layout();
        }
        right_hand_layout();
    }

    // Connecting Plate (Base) - Simplified representation
    color("Black")
    translate([0, -50, -case_height_min - 2])
    cube([100, 50, 2], center=true);

}

// --- Render Logic ---

$fn = 60; // Smoothness

if (view_mode == "3D") {
    full_assembly();
} else if (view_mode == "BLUEPRINT") {

    // 1. TOP VIEW (Plane XY)
    translate([0, 200, 0]) {
        color("Black") text("TOP VIEW", size=10, halign="center");
        projection(cut=false) full_assembly();
    }

    // 2. FRONT VIEW (Looking from -Y)
    translate([0, 0, 0]) {
        color("Black") text("FRONT VIEW", size=10, halign="center");
        // Rotate so Front faces Up (Z)
        projection(cut=false) rotate([90, 0, 0]) full_assembly();
    }

    // 3. SIDE VIEW (Looking from +X, Right side)
    translate([250, 0, 0]) {
        color("Black") text("SIDE VIEW", size=10, halign="center");
        // Rotate so Right faces Up (Z)
        projection(cut=false) rotate([0, -90, 0]) full_assembly();
    }
}

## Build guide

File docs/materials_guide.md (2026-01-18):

# プロジェクトHanoji ハードウェア素材選定ガイド

本ドキュメントは、プロジェクトHanojiにおける筐体製造（3Dプリント・外注）の素材選定基準をまとめたものである。
目的（試作、コスト重視、品質重視）に応じて適切な素材・工法を選択すること。

## 1. 素材・コスト比較マトリクス

※コストは1kgフィラメントリールの市場価格目安（外注は部品単価目安）。

| 素材カテゴリ | おすすめ素材 | コスト感 (目安) | 積層痕 | 強度・耐久性 | こんな場合におすすめ |
| :--- | :--- | :--- | :--- | :--- | :--- |
| **デザイン・安価** | **PLA**<br>(Matte / Silk) | **低**<br>(¥3,000〜) | **Matte**: やや隠れる<br>**Silk**: 目立つが綺麗 | **中**<br>熱に弱い (〜55℃) | ・色や光沢で個性を出したい<br>・室内利用のみ<br>・**とにかく安く作りたい** |
| **実用・高コスパ** | **PETG** | **低**<br>(¥3,000〜) | **目立つ**<br>(テカテカする) | **高**<br>割れにくい、薬品に強い | ・**コスパ最強の実用品**を作りたい<br>・持ち運びで乱暴に扱いたい<br>・見た目は二の次 |
| **工業・タフ** | **ASA**<br>(またはABS) | **中**<br>(¥4,000〜) | 普通<br>(後加工で消せる) | **特高**<br>耐熱・耐候性が高い | ・市販品レベルの**頑丈さ**が欲しい<br>・長く使える製品にしたい<br>・アセトン燻蒸等に挑戦したい |
| **高級・質感** | **CF-PLA**<br>**CF-PETG** | **高**<br>(¥5,500〜) | **目立たない**<br>(マットな質感) | **高**<br>カッチリ硬い | ・**自家生産で最高クオリティ**を出したい<br>・塗装なしで高級感を出したい<br>・硬化鋼ノズル等の準備が可能 |
| **究極・プロ** | **Nylon (PA12)**<br>(MJF/SLS外注) | **特高**<br>(¥15,000〜/個) | **なし**<br>(梨地仕上げ) | **最高** | ・**予算度外視**で完璧な製品を作りたい<br>・積層痕を絶対になくしたい<br>・ハイエンドモデルとして販売 |

## 2. 製造コスト試算 (Case Study)

v2プロトタイプ相当（約294g PLA / 一体型 / V字形状）を製造した場合の概算比較。

| 製造方法 | サービス・機器 | 概算コスト (1個あたり) | 特徴 |
| :--- | :--- | :--- | :--- |
| **自家生産 (PLA)** | Bambu Lab | **約 ¥800 〜 ¥1,200** | フィラメント代のみ。圧倒的に安い。 |
| **自家生産 (CF素材)** | Bambu Lab | **約 ¥1,800 〜 ¥2,500** | 材料費は倍になるが、それでも激安。 |
| **海外委託 (MJF)** | **JLCPCB** (中国) 等 | **約 ¥15,000 〜 ¥25,000**<br>($100〜$160 送料込) | 安価だが円安の影響大。「一体型」はかさばるため送料・体積計算が高くなる傾向。 |
| **国内委託 (MJF/SLS)** | **DMM.make** 等 | **約 ¥30,000 〜 ¥50,000** | 品質・サポートは最高だが高額。体積課金のため中身が詰まっていると非常に高価になる。 |

**コスト削減のヒント (外部委託時):**
MJF/SLSなどの粉末造形は「占有体積（Bounding Box）」が価格に大きく影響する。
一体型のV字形状は「隙間（デッドスペース）」が多く、高額になりやすい。
→ **「左右分割型」** に設計変更し、パーツを重ねてコンパクトに配置（ネースティング）することで、コストを **30%〜50% 削減** できる可能性がある。

## 3. 各フェーズにおける推奨戦略

### 3.1 試作フェーズ (Prototyping)
- **推奨**: **PLA (Basic/Matte)**
- **理由**:
    - 印刷が最も安定しており、失敗が少ない。
    - 安価であるため、形状確認のために何度でも出力し直せる。
    - **Tree Hybrid** サポートとの相性が良く、取り外しが容易。

### 3.2 小ロット販売・自家生産 (Small Batch)
- **A案: コスト重視・カラー展開**
    - **素材**: **Matte PLA**
    - **戦略**: 積層痕を「デザインの一部」として許容し、豊富なカラーバリエーションを売りにする。
- **B案: クオリティ重視**
    - **素材**: **CF-PETG / CF-PLA** (カーボン配合)
    - **戦略**: 単価は上がるが、塗装レスで高級感を出し「プレミアムモデル」として差別化する。
    - **必須要件**: 硬化鋼ノズル (Hardened Steel Nozzle)。

### 3.3 ハイエンド・量産 (Mass Production)
- **推奨**: **Nylon (PA12) - MJF/SLS**
- **理由**:
    - 積層痕が一切ないプロ品質。
    - 手汗に強いサラサラした質感。
    - 外部委託（JLCPCB, DMM.make等）となるため、設計の制約（オーバーハング等）から解放される。

## 4. テクニカルノート
- **サポート設定**: 傾斜面や内部空洞が多い本プロジェクトの形状には、Bambu Studioの **"Tree Hybrid"** が最適。
- **PLAの注意点**: 夏場の車内など高温環境（50℃以上）で変形するリスクがあるため、ユーザーへの注意喚起が必要。耐久性を謳うならPETG/ASAへの切り替えを検討すること。

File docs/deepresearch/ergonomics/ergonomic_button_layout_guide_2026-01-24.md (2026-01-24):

# 指に優しいボタンレイアウトの設計ガイド

成人の平均的な手を前提に、さまざまな分野のインターフェース設計から「指にとって効率的で負担の少ないボタン配置」の知見をまとめます。エルゴノミクスキーボードから楽器、操縦デバイス、医療ロボットまで具体例を挙げ、指の解剖学に適した配置パターンとその数値指標、そして人間工学的な根拠を解説します。

## エルゴノミクスキーボードの設計理念

### 指の長さ差への対応 – 縦方向オフセット vs. 円弧配置

従来のタイプライター由来のキーボードは水平な段差配置でしたが、人間工学的には各指の長さに合わせて縦方向にずらす（Column Stagger）方が自然です。具体的には中指列を基準として、他の指のキー列を上下にオフセットします。エルゴノミクスキーボード設計者の一人は「中指列と小指列で少なくとも1.0キー分（約19mm）の高さ差をつけるべきだ」と述べています。実際、DIYキーボード愛好家からも「小指列は薬指列に対して0.75～1.0キー分の下げ（約15～19mm）が快適」だとの報告があります。この程度のオフセットがあれば、短い小指でも上段に手を伸ばしやすく、下段で中指が窮屈になるのを防げます。事実、縦ズレ列型の配列では、オフセット無しのグリッド配列と比べ、各指が自然な曲げ伸ばしの範囲で上下のキーに届くため、特に薬指・小指の無理な伸展が減少します。

さらに進んだ設計では、円弧上のキー配置（Arcレイアウト）が採用されています。これは手のひら側から見て指の付け根（MP関節）を中心とした同心円状にキーを配置するもので、各指を曲げた自然なカーブにキー列を沿わせます。たとえばMaltronやKinesisといった立体的キーボードでは、キー面を手前にすり鉢状に湾曲させ、長い指ほど遠い位置、短い指ほど近い位置に配置します。Kinesis Advantageは指を軽く曲げたときのカール（丸み）に合わせてキーを並べた凹面ウェル構造を持ち、各指の自然な可動域内で押下できるよう工夫されています。この円弧配置により、指を大きく伸ばさずともキーに届き、腱や筋への負担軽減につながります。

**バイオメカニクス的根拠:**
手をリラックスさせ机上に指先をトントンと置くと、中指が最も高く、小指と薬指ほど低い位置になります。したがってキー列も同様に高低差をつけるのが理にかなっており、これがColumn Staggerの基本発想です。また指を曲げるとき各指先は手のひら中央付近に向かうため、円弧状・曲面状にキーを配置すると指先とキー面との角度ズレが減り、押下が楽になります。長い指ほど遠くにキーを配置することで、各指がほぼ同じ程度の屈曲でホームポジションから上下のキーに届くため、打鍵ストレスを均等化できるのです。

### 指の開き角度への対応 – スプレイ角（Splay）とハの字配置

人は指を開くと扇状に広がり、握ると内側にすぼまります。この特性に合わせ、キー列自体を放射状に傾けるのがスプレイ（splay）設計です。一般的な直線配列では各指を真っ直ぐ前方に伸ばしますが、自然な手の姿勢では人差し指～小指は少し外斜め方向に向かいます。そこでエルゴノミクスキーボードでは小指側の列を外側に傾ける工夫が見られます。自作キーボードコミュニティのある提案では、小指列を他の列から約15度外側に傾ける配置が示されています。実際にこの角度で小指キーを配置すると、小指を自然に外旋させた状態でキーに触れられるため、捻じり込み動作が減ります。ほかの指の列は平行でも、小指列だけわずかに外向きにオフセットすることで「小指だけ不自然に内側へ曲げないと届かない」という状況を緩和できます。

またキーボード全体を左右に分割し、左右手首が自然にハの字になるようキーボードの半分ごと外側に開く（V字配置）手法も広く使われています。たとえば「Alice配列」キーボードでは左右のキー群がそれぞれ数度ずつ外側に向けられ、手首の角度（尺側偏位）を軽減します。このハの字角度は5～15°程度が多く、Logitech K860等の市販品でも緩やかにカーブした一体型で実装されています。研究によれば、腕の自然な開きに合わせてキーボードを5–7°内側に回転させるだけで手首の無理なひねりが大幅に減るとの報告があります。つまりスプレイ角を持たせることで、肘から手首までを一直線に保ち、タイピング時の外側への偏りストレス（尺側偏位）を低減できるのです。

**バイオメカニクス的根拠:**
手首をまっすぐ保つには、手のひらを向かい合わせにした自然な角度で鍵盤に向かう必要があります。平行なキー列では肘を張り出すか手首を曲げる必要がありますが、列を外向きに開けば手首は中立位に近づきます。また小指側の列角度を付けるのは、小指が手の構造上他の指より斜めについているためです。実際、小指を真っ直ぐ前に突き出す動きは苦手ですが、やや外側に開く方が自然に力が入ります。スプレイ設計はこの点を踏まえ、小指・薬指が無理なく押せる角度でキーを配置することで、腱鞘や関節への負荷を和らげています。

### 到達範囲と快適ゾーン – フィッツの法則と頻度配置

エルゴノミクス設計では、「よく使う操作ほど指のホームポジションから近い“プライマリ・ゾーン”に配置する」ことが重要です。これは人間の動作時間モデルであるフィッツの法則にも合致します。フィッツの法則では「目標までの距離が短く、目標が大きいほど素早く正確に到達できる」とされ、キーボードやゲームコントローラーでも頻繁に押すボタンほどホーム位置からの移動距離を短く・押下面積を大きくするのが合理的です。

具体的には、親指・人差し指など器用で力のある指の下に主要ボタンを置き、ホームポジションから半径数cm以内に収まるよう配置します。たとえばゲームパッドでは、攻撃やジャンプなど頻用ボタンは親指がほぼ動かず届く位置（十字キーやABXYボタン周辺）にあり、滅多に使わないメニューや設定ボタンは一段遠くに配置されています。格闘ゲーム用のアーケードコントローラーでも、**強パンチ・強キックなど主要4～6ボタンは指を置いたホームから指先の届く範囲（おおむね半径50mm程度以内）**に固め、たまにしか使わない「押し込み」「パリィ」などは少し手を移動しないと届かない隅に配置する、といったメリハリが推奨されます。

実際のキーボード設計でも、使用頻度と配置の関係を定量的に最適化しようとする試みがあります。ある研究では、「握ったときの指の届きやすさ（reachability）とキー使用頻度を数値で結びつけ、頻用キーを自然に指が届く範囲に配置するアルゴリズム」が提案されています。このアプローチでは、人差し指～薬指がホームポジションから無理なく動かせる角度・距離内を“快適領域”と定義し、その中にエンター・スペース・バックスペース等の多用キーを割り当てます。一方、小指が担当するキー数は減らし、代わりに親指クラスタ（スペースや修飾キー）に役割を分散させる設計も取られています。例えばErgoDoxやMoonlanderでは親指に4〜6個ものキーを持たせ、小指の負担を軽減しています。

**バイオメカニクス的根拠:**
指先の素早い動きには可動範囲内での短距離運動が適しています。ホームポジションから数十ミリ程度の微小な移動なら指先の屈伸だけで済み、高速かつ正確なタッチが可能です。しかし手を開いて移動するような大きな距離（数センチ以上）の移動では上肢全体の関与が必要になり、動作時間も増えエラーも起こりやすくなります。そのため、一連の操作で頻出するボタンほどホームから近く・まとまった配置にするのが合理的です。加えて、ゲームやタイピングでは動作の連続性も考慮されます。例えば格闘ゲームではコンボ入力を素早く行うため、連打すべきボタン同士が指の移動経路上に一直線に並んでいることが望ましく、これもフィッツの法則に沿った配置最適化と言えます。

## 楽器のインターフェースに見る指使い最適化

### ボタン式アコーディオン – クロマチック配列の指運び

クロマチックボタンアコーディオン (CBA) は、ピアノ式鍵盤に比べボタンが格子状に密集配置された独特のインターフェースです。その代表的な配列にはCシステムとBシステム（それぞれ音名CやBを基準に配置）の2種類があります。この配置は一見複雑ですが、人間工学的に見ると音階や和音のパターンを指のパターンに直結させる利点があります。CBAでは隣り合うボタンが半音階で並び、斜めに指を移動することでスケールをなぞれるため、どの調でも同じフィンガリングパターンで演奏可能（等距離鍵盤的な性質）です。これは「指使いのパターンが音楽上のパターンに対応する」ことを意味し、演奏者の脳内マッピングを単純化します。事実、クロマチック式の均一なボタン配列によりキーが違っても運指が共通になり、大きな跳躍音程（例：2オクターブ離れた音）もボタン間隔が狭いため手の移動量が少なく届きます。

BシステムとCシステムの違いについては諸説ありますが、Bシステムでは親指を使った演奏がしやすいと言われます。B配列では音階が斜め左上がりに進行するため、熟練者は右手の親指を第5列（重複列）で活用して高速フレーズを補助することもあります。一方Cシステムはピアノ鍵盤にやや指使いが近い感覚とも言われ、ホ長調などシャープ系の曲でメロディが指下に収まりやすい利点があります。いずれのシステムも基本的には3列でほとんどの音階をカバーし、残りの2列は指の運びを楽にするための重複列です。この重複のおかげで、難しいパッセージでは運指に複数の選択肢が生まれ、手首をひねるような無理な動きを避けたフィンガリングが可能になります。

例えば、ある音を中指で押さえたままその隣の音を他の指で取る際、重複キーがあれば指を滑らせるだけでなく別の列の同音を押す選択ができます。このように**「同じ音への別経路」**を提供する配置は、指や手首の動きを最小限に抑える運指最適化に貢献しています。

**バイオメカニクス的根拠:**
CBAのボタン間隔はおよそ音程半音あたり約18mm前後で、ピアノ鍵盤よりもはるかに密です。この物理的近接性により、指を大きく移動せずとも広い音域をカバーできます。例えばピアノで1オクターブ離れた音を押さえるには手を大きく開く必要がありますが、ボタンアコーディオンでは配置のおかげで指を少し斜めに動かすだけで済みます。さらに、各指の独立性という観点では、ボタンの配置が等間隔ゆえに4本の指を均等に使った運指が発達しやすく、特定の指（小指など）ばかり酷使しないバランスの良い運指が実現できます。Bシステムで親指を使う奏法も、5本指全てを活用して筋肉負担を分散する合理的なテクニックと言えます。

なお、関連するボタン式楽器のバンドネオンは特殊な例です。標準的なドイツ式バンドネオン（Rheinische Layout）は音配置が一見ランダムで、右手・左手それぞれ押し引きで異なる音配列を持つ複雑系です。このため習得は難しいものの、特定の和音進行やメロディを最小の指移動で演奏できるよう歴史的に最適化されています。例えばタンゴで多用される音形は、結果的に伝統配列だと指の置き換えが少なく演奏可能になっています。一方で近年では統一鍵盤的なバンドネオン（ユニソノリック）も開発されており、KusserowやPeguriシステムでは押し引きで同音が出るクロマチック配列を採用。これはスケールや和音の配置が論理的（順番通り）になるため、初心者でも習得しやすく即興も行いやすいというメリットがあります。実際、「配置の違いは指パターンを変えこそすれ音色には影響しない」という観点から、21世紀にはCBA式バンドネオン（B配列やC配列のボタンを持つもの）も製作されています。これらはアコーディオンの運指論理をバンドネオンで活かし、演奏時の指・手首の負荷を軽減する試みと言えます。

### 管楽器のキー配置改良 – ベーム式システムの功績

木管楽器の鍵系における人間工学的革新としては、フルートのベーム式システムが代表的です。19世紀半ば、フルート奏者で発明家のテオバルト・ベームは、それまでの8鍵フルートの欠点を解消するために画期的なキー配列を考案しました。ベームの発想は、「音響的に最適な位置にトーンホール（指穴）を開け、その穴を機械式キーで連結して指が届く場所から操作する」ことでした。具体的には、大きな音量・正確な音程を得るため指先では塞げない大径の穴を楽器に開け、その上にリングキー（開いた指輪状のキー板）を配置しました。指である穴を塞ぐと、その指輪を通じて連動する別の穴も同時に塞がれる仕組みです。例えばフルートの薬指で1つのキーを押すと、連動して難reachな位置の穴が閉まるようになっています。これにより演奏者は指が届きやすい場所だけを押さえれば、遠くの穴もカバーできるのです。

ベーム式フルートでは他にもオープンG#問題（G#キーを常開から常閉に変更）やブリチアルディキー（左手親指による易しいH（シ）音押さえ）など、指の負担軽減策が取られています。またトーンホールをできる限り指に無理のない配置に再配置しつつ、従来は指で直接押さえていた穴をプレートキー（蓋）でカバーすることで、穴径を指先サイズに制約されずに拡大しました。結果、音響的に改良されたうえで指は常に自然なカーブを保ったままキーを操作できるようになりました。ベームシステム導入後、フルート演奏時の手指の形はかなりリラックスしたものになり、以前のような指の窮屈なストレッチ動作（例えば小指で遠いキーレバーを押し下げる等）が減ったと言われます。

このベーム式機構は他の管楽器にも波及しました。クラリネットやサクソフォンの近代的キー配列も基本的にベームの原理を採用し、人差し指・中指・薬指が自然に届くところに主音孔を配置し、足りないところは連動キーで補う形となっています。サクソフォンの場合、アドルフ・サックスが基礎設計を行いましたが、その後Selmer社などが改良を重ね、左手小指のスパチュラキー群（低音域の複数キー）を斜めに並べて小指の押し替えをスムーズにしたり、右手側キーを人間工学的にオフセット配置（下管のキーを指の長さに合わせて段違い配置）するなどの改善を行いました。1930年代のSelmer社「Balanced Action」モデルでは、それまで左側についていた低音キー（B♭・B）を右側に移し、左小指で扇状に操作できるより直感的な配列に再設計されています。さらに同モデルでは左手薬指のスタック（並び）をオフセットし、各指が自然に届くようキー高さを調節、小指キー（スパチュラ）の形状もより押しやすい角度に変更されました。

総じて近代木管楽器のキーシステムは、「音響上必要な穴位置」と「解剖学上楽な指位置」とのギャップを巧妙なキー連動メカニズムで埋めたものと言えます。これにより演奏者は指を大きく開いたり押し込んだりしなくても、指先の軽い動きで複雑な運指をこなせるようになりました。

**バイオメカニクス的根拠:**
人間の指は、 特定方向への細かな動きには長ける一方、指穴を強く押さえ込むような力や、指を大きく広げる動作には限界 があります。ベーム式はこの点で、力よりも器用さを活かす設計です。指先でリングを押すだけで複数穴を閉じられるため、一点にかける力は小さくて済み、腱に優しい。また大きな穴を直接塞ぐには相当の指腹の広さと力が要りますが、キーでカバーすれば指は軽くキーをタップするだけになります。さらに、指の動きを見ると、中指や薬指はある程度長さがあるため一部穴には届きませんが、連動キーでその不足分を補うことで手の平の開きすぎを防いでいます。サクソフォンの左手小指キー群の改良も同様に、小指が無理なストレッチや屈曲をしない角度を研究した結果で、わずかな手首の回内・回外だけで4つの鍵を切り替え可能にするなど、指の生理に適った配置になっています。

## 高機能操縦デバイスの指先インターフェース

### 戦闘機のHOTAS – 親指・人差し指に集約したスイッチ配置

戦闘機の操縦桿とスロットルに代表されるHOTAS（Hands On Throttle-And-Stick）デバイスは、「両手を主要操作から離さずにあらゆる操作を行う」ことを目指した設計です。そのため、武器の選択や通信、視点操作など多数のスイッチが親指と人差し指の届く範囲に集中的に配置されています。例えばF-16戦闘機の操縦桿（サイドスティック）には、人差し指で引くトリガーの他、親指で操作する4方向ハットスイッチ（視線やセンサー制御用）や武器発射ボタンが上部に並びます。左手のスロットルレバー側も、親指で押す各種ボタン・ハット（レーダーモード切替、無線送受信ボタン等）や人差し指で引くスイッチ類（指で前方に押し出すミサイル制御スティックなど）が立体的に配置されています。

この配置の肝は、使用頻度の高い操作ほど指をほとんど動かさず届く位置に置く点です。戦闘中にパイロットが頻繁に使うトリガーや武器選択、視点移動スイッチは、スティックを握った手の親指・人差し指がそのまま自然に触れられる位置にあります。逆に緊急時のみのスイッチ（例：非常用のリミッター解除など）は誤操作防止の観点から敢えてカバー付きであったり、指を大きく伸ばさないと届かない位置（例えば小指側や手のひら側奥）に配置されます。これは**「重要だが頻度の低い操作は意図しない操作を避けるため距離を置く」**設計思想です。

実際の研究でも、HOTASのボタン配置について**「押しやすさ（届きやすさ）と使用頻度をリンクさせることで操作効率を上げる」手法が提唱されています。特に右手用スティックでは、親指と人差し指の協調動作がキーになります。最新の人間工学研究では、親指と人差し指で同時に別々のスイッチを操作するような拇指-示指の協調タスクに注目が集まっています。これは戦闘機パイロットが高度な状況で複数の入力を同時に行うケース（例: 人差し指で照準追随トリガーを半押ししつつ、親指で視線センサーを操作）に対応した解析で、指の独立性を生かしつつ干渉しない配置**を模索するものです。結論として、指先の届く範囲を逸脱しないように配置しつつ、複数のボタン操作が物理的に妨げ合わない間隔と角度を与えることが最適とされています。

例えばF-16では、左スロットルのTDC（目標指示カーソル）コントローラを親指ではなく人差し指で前面から操作する配置に変更した例があります。これは人差し指の前後動作の方が親指の横動作より精密かつ自然とのパイロットのフィードバックによるもので、指ごとの得意な動きに合わせて配置換えがなされた好例です。

**バイオメカニクス的根拠:**
操縦桿を握った際の手の形を見ると、親指と人差し指は他の指より自由度が高く、素早い動きが可能です。特に親指は回旋（ひねり）と内転・外転が得意で、多方向スイッチの操作に向きます。一方人差し指はトリガーのような引き金操作やボタン押下に力と速度を発揮できます。HOTASはこの特性を踏まえ、親指=多方向入力／人差し指=トリガー＆ボタン入力という役割分担が多用されています。また、人間は視線を動かさず触覚だけでボタン識別する際、手が基準位置に固定されている方が圧倒的にミスが減ります。スティックやスロットルに手を添えた状態で親指・人差し指だけを動かす操作は、手の位置記憶と触覚によりブラインドでも正確に行えます。これは手を離してコックピットの計器パネルに腕を伸ばして押す場合と比べ、格段に速く疲労も少ない動作です。HOTAS配置は、人の手の触覚的なボディマップを活用し、パイロットが「握った姿勢」のまま直感的に操作できるよう設計されているのです。

### F1マシンのステアリングホイール – 指を離さず操作できるボタン配置

フォーミュラ1（F1）のステアリングホイールは、現代のあらゆるコントローラの中でも極限まで洗練された指先インターフェースです。ドライバーは時速数百kmでコーナリング中でもハンドルから手を離さずにエンジンモード変更や無線送信などを行う必要があるため、ホイール上のボタンやダイヤルの大半は親指で届く位置に配置されています。各チームのステアリング設計は異なりますが共通しているのは、使用頻度の高いボタンほどグリップから近いことです。典型的な例として、DRS（ドラッグリダクション）やERSブーストのオーバーテイクボタン、ピット交信の無線ボタン、エンジン設定を切り替えるロータリースイッチの一部などは、親指を軽く動かすだけで押せる位置にあります。実際、F1ドライバーはステアリングを握ったまま親指でボタンを押し込む動作でERSや無線を操作し、これは数ミリのボタン移動に0.1秒以下しかかからないよう計算されています。

一方、使用頻度の低い調整ノブ（例えば微調整的な多段ロータリースイッチ類）はホイール下面など一旦手を片方離さないと回せない位置に置かれます。これは走行中に誤って触れてしまうのを防ぐ意味もありますし、走行中ずっと操作し続ける類のものではないためです。実際Williamsチームのステアリング解説によれば、「1周ごとに何度も使う操作ほど指先に近く配置し、稀にしか回さない多機能ノブは手を離して操作する下部に置く」とされています。例えばシフト（変速）は最も頻繁な操作なので人差し指のすぐ先にパドルがあり、クラッチはスタート時以外あまり使わないためそれよりやや下に配置されています。また、親指が届く正面にはKERSやモード切替のボタンが色分けされ配置され、触覚と視覚の両面で識別しやすく設計されています。

ステアリング裏側にもシフト用やクラッチ用のパドル（レバー）が配置され、これも指をほとんど伸ばさずに指先で弾ける位置と反発力に調整されています。F1ではシフトチェンジは一瞬の遅れも許されないため、変速パドルは人差し指第一関節付近で即座に引けるようなレバー比になっています。さらに、各ドライバーの手の大きさや持ち方に合わせてボタンの位置・角度・高さは個別にカスタムされます。メルセデスAMGのエンジニアによれば、「すべてのボタンはドライバーの親指が届く範囲に色分けして配置するのが鉄則」と述べており、実際F1ステアリング上の25個前後の入力デバイスは、ほぼ全てが両親指でカバー可能な扇形領域内に収まっています。

**バイオメカニクス的根拠:**
車両のハンドルを握った状態で、ドライバーの手指には遠心力やG負荷がかかります。親指で押す操作はハンドルを握る力を多少緩めても他の指で支えられるため安定していますが、もし手を離してダッシュボードに触れるような操作をすれば、その瞬間に操作精度が落ちて危険です。従って親指・指先の微細運動だけで完結する配置が安全かつ高速なのです。さらに、F1ドライバーはレース中、視線はコースに固定しつつ周辺視野でステアリングのLEDや色付きボタンを識別します。ボタンが常に同じ位置にありブラインドタッチできること、および触った感触で機能がわかることが極めて重要です。そのため、人間の手指の位置覚（Proprioception）をフル活用し、各指が届く範囲で段差や大きさを変えてボタン識別しやすくしてあります。例えば「プッシュトーク」は他より盛り上がったボタン、「ERS」ボタンはリブ付きなどの工夫です。これも指先の触覚能力を活かした人間工学的配置であり、極限環境下でもミスを最小化する重要なポイントとなっています。

## 医療・産業用ロボットのマスターコントローラ

### 手術支援ロボット（da Vinci）の指インターフェース – ピンチグリップによる精密操作

手術支援ロボット「ダヴィンチ (da Vinci Surgical System)」の外科医用コンソールは、人間の手の器用さを拡張するインターフェース設計がなされています。外科医はコンソールに座り、両手の親指と人差し指（場合によっては中指も）をリング状のマスターコントローラに差し込んで操作します。このコントローラはちょうど鉗子(フォーセプス)をつまむようなピンチグリップで動かす設計で、外科医の手首・肘は楽な姿勢のまま、指先の細かな動きをロボットアームの先端に伝達できます。具体的には、親指と中指・人差し指で輪っかを挟むように持ち、指を開閉する動きが鉗子の開閉に対応し、手首の回旋や屈伸が器具の回転・上下動に対応します。まさに道具を握るのではなく指先でつまむことで、長時間操作しても疲労しにくく、しかも極めて精密なコントロールが可能になるのです。

このマスターコントローラには指抜きクラッチという機能もあり、指をリングから外すとロボット側の動きを一時停止（マスター-スレーブの位置対応を切り離す）できます。これにより術中に外科医が姿勢を直したり腕を持ち替えたりする際も、無理な関節角度を強いられず快適な手首位置で再開できます。このような配慮はインターフェース設計上、手指・手首の中立姿勢を保つことを重視した結果です。実際、ダヴィンチでは術者の手は自然な目線の延長線上に置かれ、肘を大きく張ったり手首を極端に曲げたりせずとも操作できるコンソール配置になっています。これにより何時間にも及ぶ手術でも術者の筋骨格系への負担が軽減されます。

精密な指先操作という点では、ダヴィンチのマスターは意図的に操作抵抗を付与してある点も特筆されます。すなわち、あまりに軽すぎると指が動きすぎて細かな制御が難しいため、適度な触覚フィードバック（ハプティック抵抗）が感じられるよう調整されています。これにより外科医は自分の指に力を入れている感覚で器具に力を加えられ、まるで実際に組織をつかんでいるかのようなフィードバックを得られます。人間工学の観点からも、指先には精密な力加減を感じ取るメカノレセプタが集中しているため、このフィードバックがあることで過剰な力を入れずに済み、結果として疲労を抑える効果があります。

産業用のマスタースレーブロボットでも、ペンダント型コントローラや手指をセンサグローブで追跡する方式がありますが、いずれも人の手の自然な動き方に沿うことを原則としています。例えば熟練クレーン操縦者向けの産業ロボットでは、操縦桿を力一杯倒す動作より、指先のジョイスティックをつまむ操作の方が長時間楽なため、親指と人差し指で操る小型スティックが採用される例があります。これもダヴィンチ同様、ピンチ動作の高い精度と低疲労性を利用したものです。

**バイオメカニクス的根拠:**
人間の親指と人差し指で物をつまむ動作（ピンチング）は、最も微細な力加減と位置制御が可能な動きです。筋電図的にも、ピンチ動作では手のひら全体を握るパワーグリップに比べ不要な筋緊張が少なく、長時間持続可能です。ダヴィンチのようにこのピンチ動作をそのまま遠隔操作に使えば、外科医はまるで自分の指先が患者体内で動いているかのような錯覚すら覚えます。また、術者が楽な姿勢で座りながら操作できる点も重要です。立って腕を挙げ続ける通常の内視鏡手術に比べ、座位で腕を支持された状態で手元操作するダヴィンチでは、首肩の負担や全身疲労が大幅に減少するとの報告があります。さらにロボット側で手ぶれをフィルタし尺度変換してくれるため、術者は神経質に力を入れずリラックスして指を動かせます。このように**「人間が最も巧みに動かせる指先」を使い、かつ「人間が疲れにくい姿勢と力加減」**で操作できるよう設計されたマスターコントローラは、まさに人間工学とロボティクスの融合したインターフェースと言えるでしょう。

---

以上、各分野の例に学ぶ指に優しいインターフェース設計のポイントをまとめると:

*   **キーやボタンの幾何配置**: 指の長短差に応じた高さオフセット（例: 小指列は中指列より 1キー分下げる）、指の自然な開き角度に合わせた傾き（例: 小指列を15°外側に傾ける）、手のひらカーブに沿った円弧・曲面配置。
*   **適切な角度と距離**: キー列やデバイス全体をハの字・テント化して手首をまっすぐ保つ（例: ハーフスプリットキーボードの外開き5–15°、F1ステアリングのボタンを親指届く扇状に配置）。指先操作デバイスではピンチ動作を活かし、無理なひねりが出ない角度に調整。
*   **ゾーニングと頻度設計**: 頻用ボタンはホームポジションから半径数cmのプライマリゾーンに集約し、稀用・危険操作はあえて距離を置く。使用頻度と届きやすさをリンクさせる配置最適化はどの分野でも有効。
*   **生体負荷の分散**: 弱い指（小指）の担当を減らし強い指（親指）に割り振る、5指すべてを使う等距離配列で指ごとの負担を平準化、腕ごと動かすより指先だけ動かす操作を採用。
*   **触覚・直感性**: 人は見なくても指位置を把握できるため、触ってすぐ分かる形状・配置にする（F1のボタン形状差別化等）。また指先に適度な抵抗やクリック感を与えフィードバックを持たせることで精度向上と誤操作防止。

これらの知見は自作ゲームコントローラー設計にも応用できます。平均的な成人の手に合わせてボタンを立体配置し、主要操作を各指の自然な届く範囲に置き、頻度や重要度で配置にメリハリをつけることで、操作性と快適性が飛躍的に向上するでしょう。各分野のエルゴノミクスの知恵を取り入れ、ぜひ快適で負担の少ないインターフェースを設計してみてください。

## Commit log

2026-01-14 Add prototype screenshots for January 15, 2026
2026-01-15 Update ergonomics research summary with feedback from prototype v1 validation. Added insights on the importance of palm rests and the necessity of a 'V' configuration for wrist comfort.
2026-01-15 Add prototype v2 concept model and design specifications
    This commit introduces a new SCAD file for the v2 concept model of the Hanoji project, featuring an ergonomic leverless controller design with defined parameters for angles, dimensions, and button co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
    [hanoji_v2_concept.scad]
2026-01-15 Implement view mode functionality and refine layout modules in Hanoji v2 concept
    This commit introduces a view mode parameter allowing users to switch between "3D" and "BLUEPRINT" (2D Drawing) views. The layout modules for the left and right hands have been refined, with the left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
    [hanoji_v2_concept.scad]
2026-01-15 新しいプロジェクトルールと初期ブログコンテンツを追加
    このコミットでは、プロジェクトのルールをまとめた新しいファイル「.cursorrules」を追加し、エルゴノミクスに基づく自作レバーレスコントローラーの製作に関する初回のフィードバックを記録したブログドラフト「v1_feedback.md」を作成しました。また、v2プロトタイプの設計仕様を更新し、曲げ天板構造の採用や角度設定についての詳細を追加しました。
2026-01-15 v2プロトタイプの設計仕様を更新し、多面体・屈曲天板構造の採用を明記。角度設定やボタン配置の詳細を追加し、エルゴノミクスに基づく快適な操作性を追求。新たに「天板屈曲構造」に関する市場調査レポートを追加し、設計パラメータの導出を行った。
2026-01-15 v2プロトタイプの設計仕様を更新し、Ridgeの位置やボタン配置の距離を見直しました。手首の自然な位置を考慮し、快適な操作性を追求するための調整を行いました。
2026-01-17 v2プロトタイプの設計仕様を更新し、外側ストッパーのデザインを追加しました。テンティング傾斜による手の滑り落ちを防止するための形状や寸法を明記し、快適な操作性を向上させるための調整を行いました。
2026-01-17 ハードウェア素材選定ガイドを新規作成し、試作から量産までの素材選定基準をまとめました。また、v2プロトタイプの製造・素材選定に関する方針を更新し、具体的な素材と製造方法を明記しました。これにより、プロジェクト全体の素材選定に関する指針を強化しました。
2026-01-18 ハードウェア素材選定ガイドを更新し、製造コスト試算を追加しました。v2プロトタイプの製造方法に関する具体的なコスト比較を示し、コスト削減のヒントを提供することで、各フェーズにおける推奨戦略を強化しました。また、テクニカルノートの章を整理し、サポート設定やPLAの注意点についての情報を明確化しました。
2026-01-18 v2プロトタイプの新しい画像を追加しました。これにより、プロトタイプのビジュアルドキュメンテーションが強化され、設計の進捗をより明確に示すことができます。
2026-01-18 プロジェクトルールの更新を行い、CADデータポリシーを明確化しました。また、プロトタイプの管理方法を整理し、ドキュメントとフィードバックの管理を`docs/prototypes/{version}/`に変更しました。これにより、設計プロセスの透明性と効率を向上させることを目指します。
2026-01-18 プロトタイプv2の設計仕様書とフィードバックドキュメントを新規作成しました。設計仕様書では、快適な操作性を実現するための主要変更点や幾何学パラメータを明記し、フィードバックドキュメントでは3Dプリント製造上の課題と対策を整理しました。これにより、プロトタイプの改善に向けた具体的な戦略を示し、次期(v3)検討事項を明確化しました。
    [hanoji_v2_concept.scad]
2026-01-24 新規に3つの市場調査ドキュメントを作成しました。これには「人間の手の解剖学的特性に基づく高効率・低負荷指先操作インターフェースの包括的研究」、「競技型格闘ゲーム用デバイスにおける曲面幾何学と解剖学的適合性の統合研究」、「指に優しいボタンレイアウトの設計ガイド」が含まれます。これらのドキュメントは、エルゴノミクスに基づく自作レバーレスコントローラーの設計における重要な知見を提供し、次世代デバイスの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
2026-02-01 プロトタイプv4の新しい画像を追加しました。これにより、プロトタイプのビジュアルドキュメンテーションがさらに充実し、設計の進捗をより明確に示すことができます。
2026-02-01 試作5号機（v5）の仕様書を新規作成しました。v4の筐体仕様を踏襲しつつ、ボタンレイアウトを微調整し、手の届きやすさと誤入力の減少を目指した検証機です。各ボタンの配置やY間隔の調整に関する詳細を記載し、次のステップとしてCADモデリングと部分試作を計画しています。
2026-02-11 docs(blog): 初回記事導入を分割キーボード起点に更新
2026-02-11 docs(blog): 初期発信スタンス調査レポートの整形ドラフトを追加
2026-02-11 docs: 調査結果をdocs/researchへ集約しINDEXを追加
2026-02-11 docs(blog): 初回下書きを仮説検証ログ構成に調整
2026-02-11 chore: 情報発信方針(調査ベース)と初回記事方針を.cursorrulesへ追加
2026-02-11 Adjust post: replace paper test with 3D print-first flow
2026-02-11 WIP: 5ee521f 自作レバーレスコントローラー市場における参入戦略と価格最適化に関する調査報告書を新規作成しました。個人クリエイターが持続可能な利益を確保するための販売価格レンジや初期販売プラン、避けるべき価格帯について詳細に分析し、競合状況を踏まえた戦略を提案しています。このドキュメントは、信頼性の構築と顧客層の獲得に向けた重要な基盤となります。
2026-02-11 WIP: b43f5fa 試作5号機（v5）の仕様書を新規作成しました。v4の筐体仕様を踏襲しつつ、ボタンレイアウトを微調整し、手の届きやすさと誤入力の減少を目指した検証機です。各ボタンの配置やY間隔の調整に関する詳細を記載し、次のステップとしてCADモデリングと部分試作を計画しています。
2026-02-11 docs: 自作レバーレスコントローラーに関する深層研究のINDEXを新規作成し、各研究成果を整理しました。また、解剖学的特性に基づく指先操作インターフェースの包括的研究と、天板屈曲構造の有効性に関する報告書を追加しました。これにより、今後の設計や開発に向けた基盤を強化します。
2026-02-11 docs: 記事作成チェックリストに「コンテンツの重複を避ける」項目を追加し、記事全体での内容の一貫性を強化しました。また、v1フィードバックの内容を整理し、テンティングとハの字の組み合わせの重要性を明確にしました。
2026-02-23 docs: note.com用のMarkdownフォーマットに関するルールを追加し、太字の使用時に半角スペースを挿入することを明記しました。また、試作1号機のドラフトファイルを削除し、v1フィードバックの内容を整理しました。
2026-03-29 feat: Claude Codeマルチエージェント構成を追加
    CLAUDE.mdファイルを階層的に配置し、SNS発信・商品企画・戦略立案・コンテンツの4つの専門エージェントを並列起動できる構成にした。各エージェントはディレクトリごとに専用の指示を持ち、プロジェクト共通ルールはルートのCLAUDE.mdで一元管理する。また、README.mdにエージェント起動方法を追記した。
2026-03-29 docs: Markdownフォーマットに関するルールを更新し、太字の日本語引用符に関する新しいガイドラインを追加しました。また、.gitignoreファイルを新規作成し、環境設定ファイルを無視するように設定しました。v1フィードバックの内容を整理し、v2の試作記録を新規作成しました。
